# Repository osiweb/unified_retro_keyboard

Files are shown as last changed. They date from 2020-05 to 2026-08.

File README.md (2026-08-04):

## Unified Retrocomputer Keyboard Project

This project aims to provide a unified collection of keyboards and encoders for
vintage computers, with modular design to reuse as many elements as possible
across the designs.

Home computers of the 1970's typically either polled a switch matrix, or
interfaced to a parallel ASCII keyboard via a parallel port.

The keyboard allows use of Cherry MX keys, or Futaba MD-4PCS (aka George Risk
KBM-01-01) keys.

The keyboard is designed using KiCad in order to be the most useful for anybody
wishing to modify the keyboard for more specific uses, or to add to the project.

For construction and notes, see the the wiki at https://github.com/osiweb/unified_retro_keyboard/wiki.

### Capabilities so far:
- Replacement keyboard for OSI computers
- Replacement keyboard for Apple II/II+ computers
- Replacement keyboard for the Sol-20 computer
- Generic ADM-3A/Teletype style keyboard
- Apple I keyboard (multiple styles)
- Franklin ACE 1000 replacement keyboard by Chris Ryu (https://github.com/ryucats/Franklin-ACE-1000-Keyboard)

### Coming soon:
- Replace encoder board on Apple II/II+ keyboards
- Convert an OSI 542 keyboard into a generic ASCII keyboard
- Replica for Knight keyboard

### This keyboard project so far consists of:
- A classic retro-style ASCII keyboard, modeled after the ADM-3A keyboard, which
  can be also be populated to fit perfectly in an Apple II/II+ case (with corresponding Apple II keymaps), or an OSI
  case (with OSI adapter).
- A Sol-20 compatible keyboard.
- Keyscan/decoder interface modules that can output parallel ASCII, and can be adapted for other protocols.
- An OSI interface module, to connect the classic keyboard to an OSI computer.

### Firmware

The ASDF keyscan/encoder firmware lives in its own repository:
<https://github.com/unified-retro-keyboard/asdf-firmware>

- **Download page**: <https://unified-retro-keyboard.github.io/asdf-firmware/> — per-target `.hex` files and release notes.
- **GitHub Releases**: <https://github.com/unified-retro-keyboard/asdf-firmware/releases/latest>

The full firmware history, including everything that was previously under `firmware/`
in this repository, is preserved there.

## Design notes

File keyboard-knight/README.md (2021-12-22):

# Knight keyboard

This keyboard replicates the keyboards on the MIT AI PDP-10.

## Differences from the original include:

1. The original keyboard used Hall effect switches. This keyboard uses
   standard switches (either Cherry or Futaba).

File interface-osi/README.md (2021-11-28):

* OSI Compatible interface

An interface for OSI computers that is compatible with the OSI 542C keyboard, including sound circuits.  

This interface also permits substitution of a soft-shiftlock function using 
a regular momentary keyswitch, instead of the hard-to-find latching keyswitch.
An LED is provided to indicate SHIFT LOCK status.  This interface mates with
the Classic ASCII keyboard, configured with the OSI keycaps.  

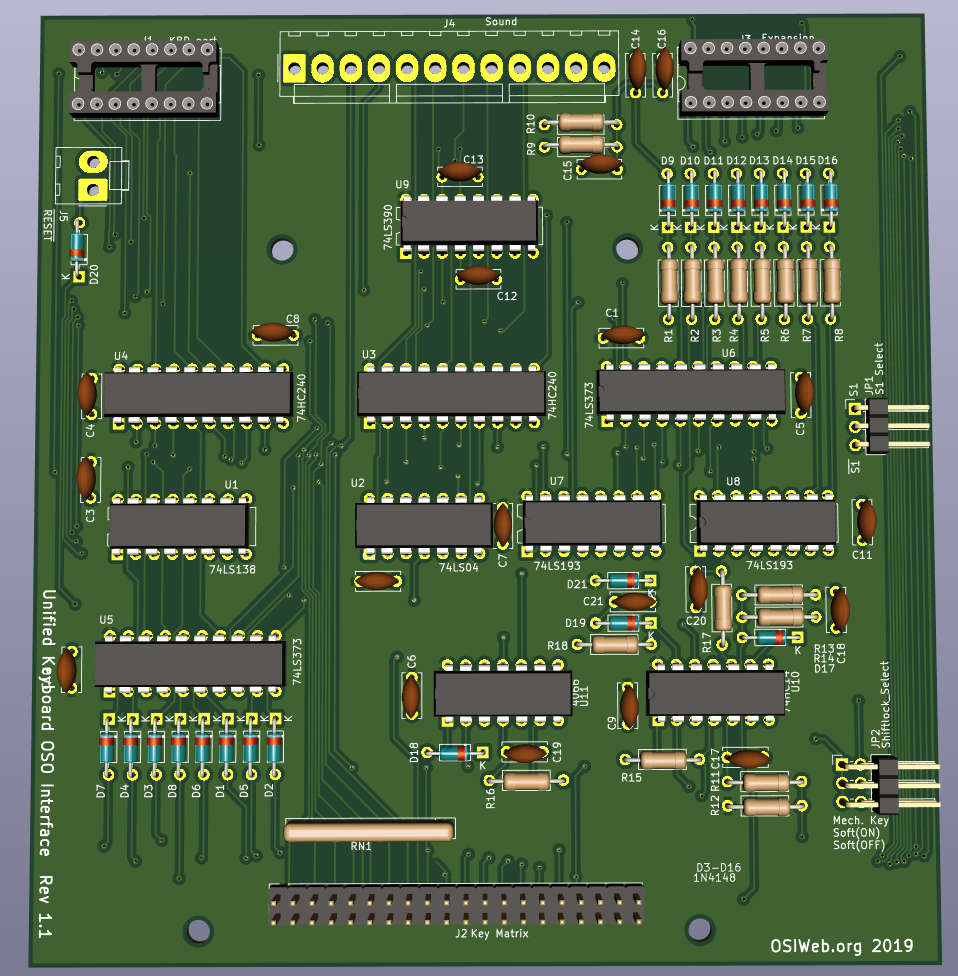
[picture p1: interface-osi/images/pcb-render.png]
Assembly Rendering


**Construction Notes:

1. If a diode per key is installed on the keyboard, then omit diodes D1-D8 and install D18.

1. If the keyboard is not installed with a diode per key, then install D1-D8, and omit D18.

1. The RESET delay is about 3 seconds with a 6.8 uF capacitor at C20.  4.7 uF gives about
2 seconds, and 3.3 uF gives about a 1 second delay.

1. If you want to use the sound circuit with an older 540A video board, then on the 540A board, jumper pin 13
of IC E4 to pin 15 of the keyboard connector, and on the OSI interface board, set JP1 to "S1".

1. If you use a 540B video board, then set JP1 to "/S1"

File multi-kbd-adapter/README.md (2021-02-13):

# Unified Keyboard Project Multi Adapter

This is a keyboard adapter to permit use of Apple 1, Apple 2, and Sol-20
compatible keyboards with any of these three computers.

## Notes
- Protoboard-style pad matrix permits flexible choice of on-board RESET and CLEAR (OR
  LOCAL) switches.
- Pin header allows external RESET and CLEAR (or LOCAL) switches
- Note that the SOL and Apple keyboards have different strobe polarity. Make
  sure the strobe polarity on the keyboard is properly configured.

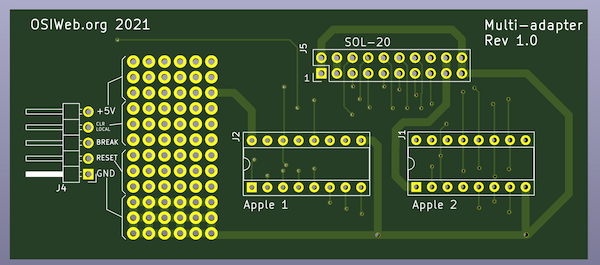
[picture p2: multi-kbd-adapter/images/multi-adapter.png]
Assembly Rendering


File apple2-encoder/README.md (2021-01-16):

# Apple II/II+ Encoder

This is a version of the ASCII interface wired up to be compatible with the
Apple II/Apple II+ keyboard matrix. This board was broken out as a separate PCB
from the Atmega2560-based interface board on which it was based, in order to
keep the "custom" connector customizable on that board.

This board is otherwise identical to rev 3.4 of the ATMega2560-based ASCII interface board, and shares the same firmware and features.

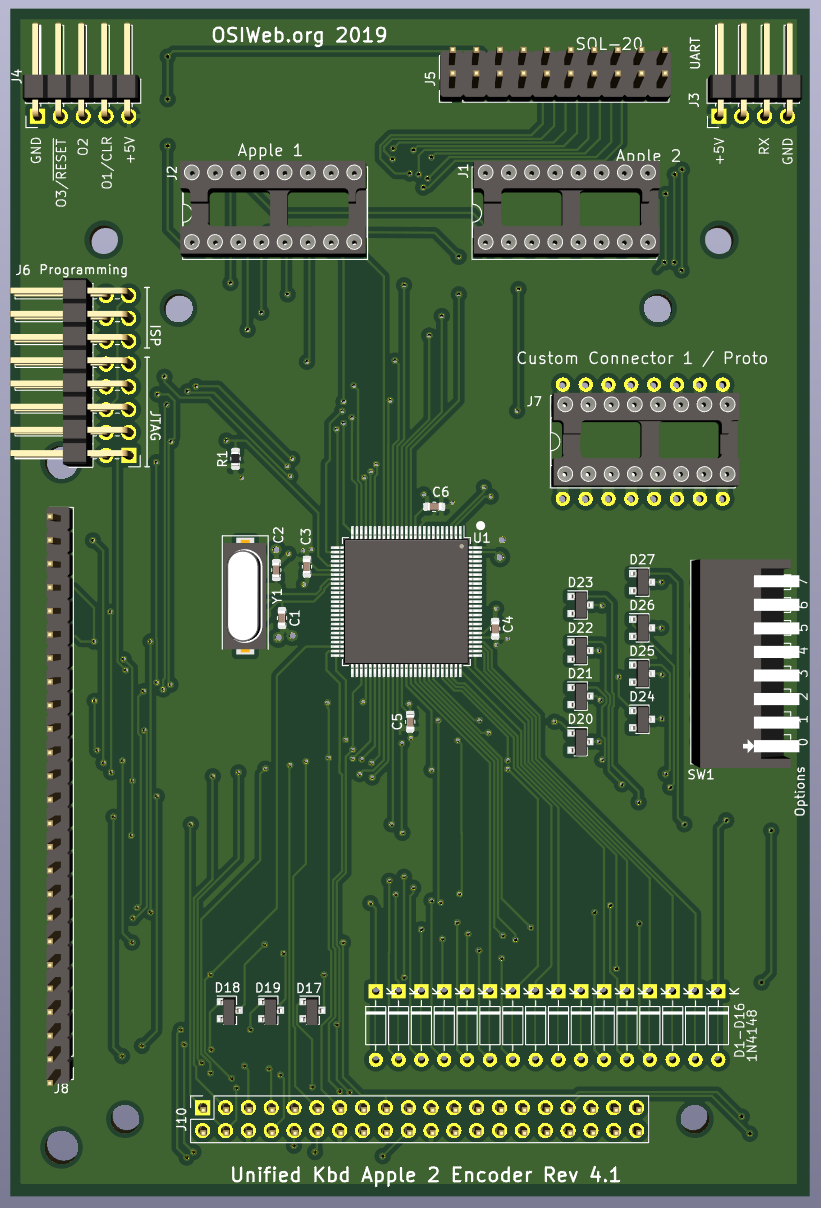
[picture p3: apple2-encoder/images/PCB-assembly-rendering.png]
Assembly Rendering


## Features
- Parallel or serial output
- Up to 8 configuration settings via an up-to-8 position DIP switch
- Apple 1, Apple 2, and SOL-20 compatible outputs. Other configurations can be
  supported by making a custom cable.
- Can decode arbitrary keyboards up 16 rows by 8 columns.
- Supports up to 3 keyboard LEDs
- Supports up to 3 "special" host outputs, such as RESET, SCREEN_CLEAR, BREAK, etc.
- Socket for custom connector

## Assembly Notes

- You may build this board as if it is a general purpose ASCII interface. In
   that case, you may want to avoid installing the 1x25 Apple2 keyboard header
   if it interferes with the target keyboard matrix. 
   
- This encoder is normally used with keyboards that have a diode per key.  For use 
with a key  matrix with no diodes (such as the Apple 2 key matrix), cut the PCB 
traces that short diodes D1-16, and install D1-16.

- If you ARE building this board as an Apple 2 encoder, then you may OMIT:

    - Sol-20 connector J5
    - Custom connector J7
    - D17,D18,D19 - These are used for the "classic" keyboard matrix.
    - D7,D8,D15,D16 - These are diodes for rows 12-15, which are not used.
    - The serial out connector J3 if you do not plan to use a serial output.
    - The I/O connector J4, as all the I/O lines are routed through the
       keyboard connector.
    - If you will be using the keyboard with only an Apple 1 or Apple 2, then
       you do not need to install both the Apple 2 connector (J1) AND the Apple
       1 connector (J2). You may install only the one you plan to use, and
       reduce the risk of plugging into the wrong socket (and possibly damaging
       the encoder).
    
1. Solder the surface-mount microcontroller first. Be sure to match pin 1 to the
   dot on the silk-screen layer.
1. Next, install the surface mount crystal, Y1.  The orientation is not important.
1. Next, solder in the resitor R1
1. Install all the capacitors. Be sure to separate out the two capacitors for the XTAL 
   circuit from the other capacitors, the rest of which are 0.1uF bypass capacitors.
1. Install the In-circuit Serial Programming (ISP) header, J6. (right-angle, 2x3
   0.100")
1. If you will be using the Apple 1 connector, install the DIP socket J1 (16-pin
   dip). If you plan to insert and remove the cable many times, a dual-wipe
   socket may be preferable to machine-pin, since it has a lower insertion
   force, and you will be less likely to bend pins. If you plan to insert the
   cable once and leave it forever, I suggest a machine-pin DIP socket.
1. If you will be using the Apple 2 connector, install the DIP socket J2 (16-pin
   dip).  The note for the Apple 1 connector selection applies here as well.

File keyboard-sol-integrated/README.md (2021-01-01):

# SOL keyboard with built-in encoder

This keyboard with integrated encoder replicates the keyboard on the SOL-20.

This keyboard has a sibling Sol-20 keyboard without integrated
encoder [(here)](../keyboard-sol). The two keyboards are identical except for the following differences:

1. This integrated version places the connector closer to the main board keyboard
   socket, so the original cable fits more easily.

1. The non-integrated version requires a piggy-back encoder board. When
   installing in a Sol-20, this piggyback board must be mounted on the right
   side of the keyboard, and connected with a cable, to avoid mechanical
   interference from the Sol main board.
   
1. The piggy-back encoder is more flexible for use with other machines, via the Apple-1 and
   Apple-2 sockets, and two different user-configurable headers.
   
1. The piggy-back encoder also includes a UART interface.

The keyboard is designed using KiCad in order to be the most useful for anybody
wishing to modify the keyboard for more specific uses, or to add to the project.

The keyset for the SOL-20 keyboard consists of the Unified Keyboard Project
classic ASCII keyset, with a special SOL-20 add-on keyset.

## Differences from the original include:

1. The original keyboard is a capacitive keyboard. This keyboard uses standard
   switches (either Cherry or Futaba).
   
1. The original keycaps have an 11 degree angled stem. It may be possible to
   find such keycaps, but I was unable to find any. It also may be possible to
   create 11 degree adapters. But this keyboard uses straight keycaps. I have
   tried both styles, and do not find a difference in typing comfort or speed,
   althought there is an aesthetic difference. There is s tiny bit of space
   between keys using straight keycaps, so an 11 degree adapter may not require
   any change to the layout.

1. The original uses UPPERCASE+REPEAT to reset the system. For technical
   reasons, this version uses CTRL+MODE_SELECT to RESET the system. 

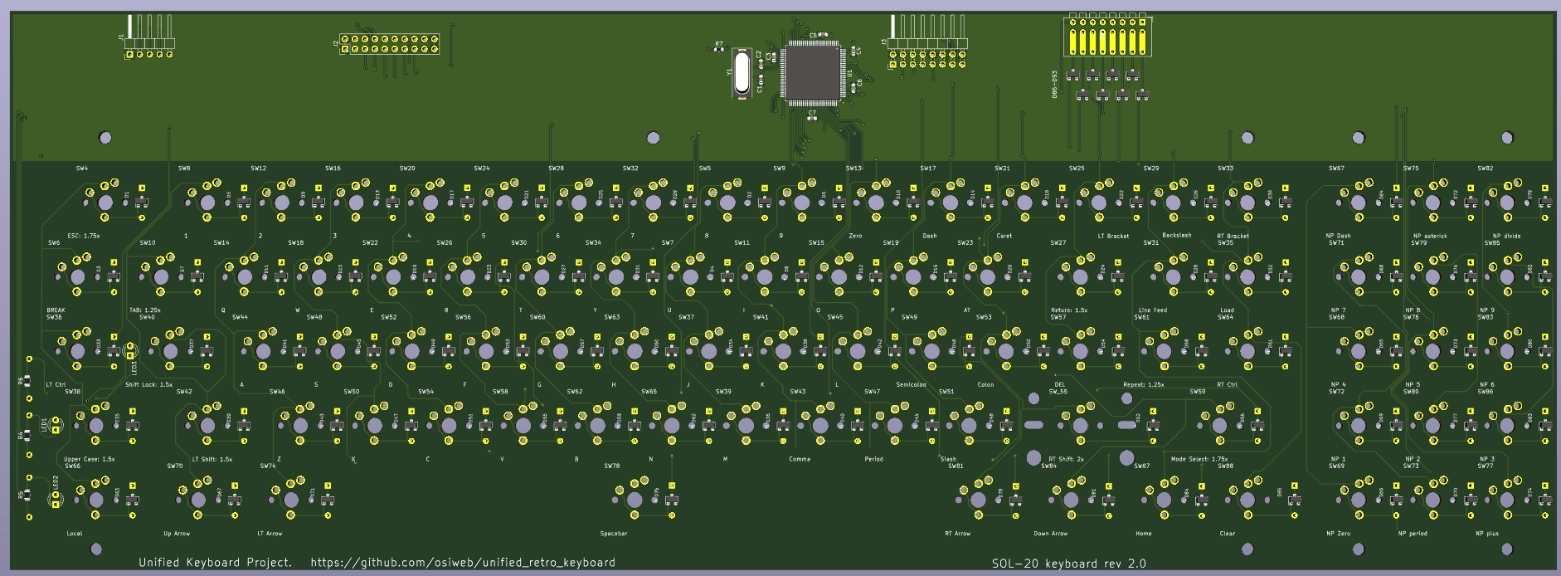
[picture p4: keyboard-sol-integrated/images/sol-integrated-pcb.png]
Sol 20 Keyboard

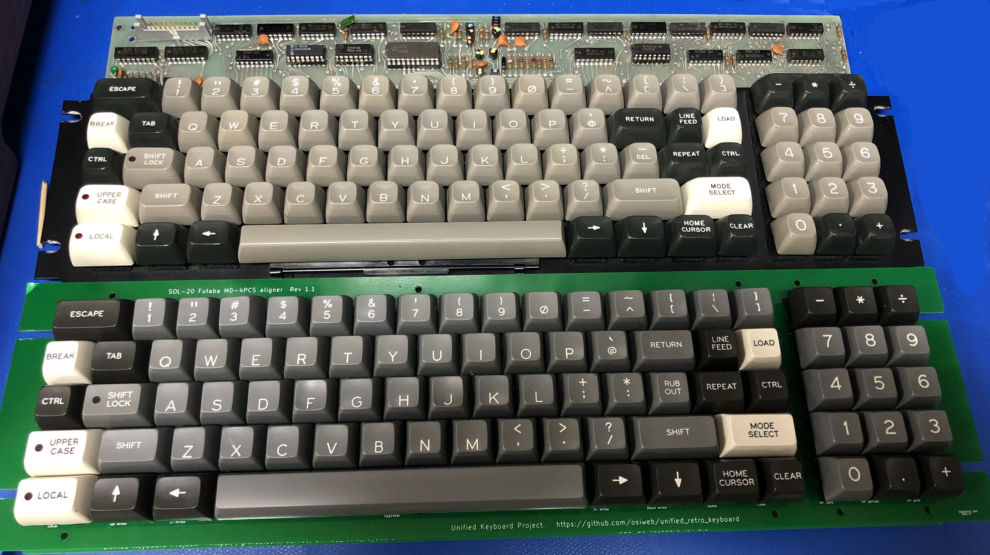
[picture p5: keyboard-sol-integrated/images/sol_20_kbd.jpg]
Sol 20 Keyboard

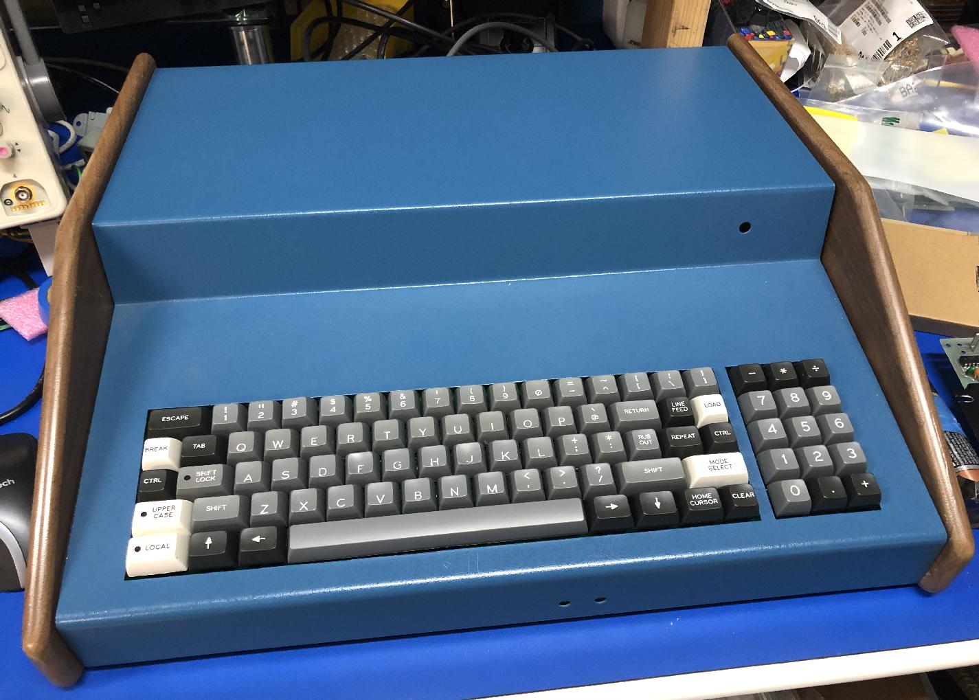
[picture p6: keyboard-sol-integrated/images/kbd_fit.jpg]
Sol 20 Keyboard


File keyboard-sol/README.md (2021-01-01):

# SOL keyboard

This keyboard replicates the keyboard on the SOL-20.

This keyboad matrix works with one of the add-on ASCII encoders from this
project, which must be separately built or acquired.

This keyboard has a sibling Sol-20 keyboard with integrated
encoder [(here)](../keyboard-sol-integrated). The two keyboards are identical except for the following differences:

1. The integrated version places the connector closer to the main board keyboard
   socket, so the original cable fits more easily.

1. This non-integrated version requires a piggy-back encoder board. When
   installing in a Sol-20, this piggyback board must be mounted on the right
   side of the keyboard, and connected with a cable, to avoid mechanical
   interference from the Sol main board.
   
1. The piggy-back encoder is more flexible for use with other machines, via the
   Apple-1 and Apple-2 sockets, and two different user-configurable headers.
   
1. The piggy-back encoder also includes a UART interface.

The keyboard is designed using KiCad in order to be the most useful for anybody
wishing to modify the keyboard for more specific uses, or to add to the project.

The keyset for the SOL-20 keyboard consists of the Unified Keyboard Project
classic ASCII keyset, with a special SOL-20 add-on keyset.

## Differences from the original include:

1. The original keyboard is a capacitive keyboard. This keyboard uses standard
   switches (either Cherry or Futaba).
   
1. The original keycaps have an 11 degree angled stem. It may be possible to
   find such keycaps, but I was unable to find any. It also may be possible to
   create 11 degree adapters. But this keyboard uses straight keycaps. I have
   tried both styles, and do not find a difference in typing comfort or speed,
   althought there is an aesthetic difference. There is s tiny bit of space
   between keys using straight keycaps, so an 11 degree adapter may not require
   any change to the layout.

1. The original uses UPPERCASE+REPEAT to reset the system. For technical
   reasons, this version uses CTRL+MODE_SELECT to RESET the system. 

Sol 20 Keyboard
Sol 20 Keyboard

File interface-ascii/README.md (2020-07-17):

# ASCII Interface - Atmega328p

This is is a key scanner module with parallel output, and optional serial
output, supporting keyboards of up to 16 rows X 8 columns.

The ATMega 328P was selected for the sole reason that it is an architecture
familiar to many hobbyists, with an accessible programming environment and
ecosystem, in a DIP format that fits the retro look and is easy to solder for
most hobbyists. All of the ICs, other than the microcontroller, are only present
to compensate for the limited number of GPIO lines on this small 28-pin
microcontroller. Using a bigger chip would greatly simplify the hardware and
even slightly simplify the hardware layer of the firmware.

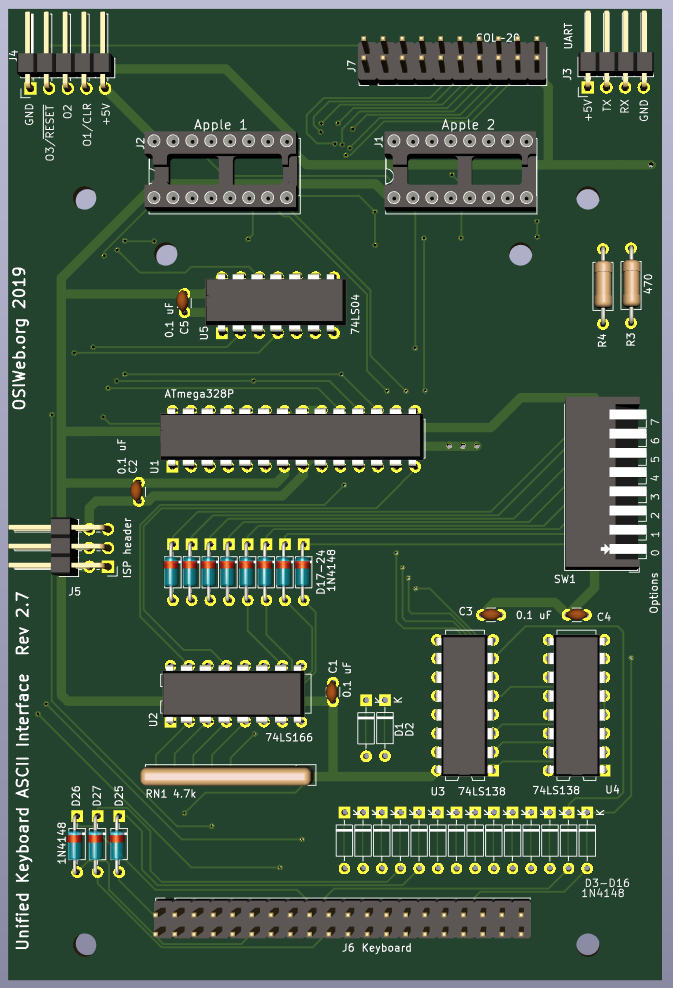
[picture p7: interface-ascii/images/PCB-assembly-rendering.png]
Assembly Rendering


## Features
- Parallel or serial output
- Up to 8 configuration settings via an up-to-8 position DIP switch
- Apple 1, Apple 2, and SOL-20 compatible outputs. Other configurations can be
  supported by making a custom cable.
- Can decode arbitrary keyboards up 16 rows by 8 columns.
- Supports up to 3 keyboard LEDs
- Supports up to 3 "special" host outputs, such as RESET, SCREEN_CLEAR, BREAK, etc.

## Overview
- The keyboard rows are driven by a pair of 74LS138 decoders, allowing 4 GPIO
  lines to drive 16 rows.
- The columns are read in via an 8-bit shift register, controlled by 3 GPIO lines.
- One 8-bit port is used for the parallel ASCII output.
- Three GPIO lines are used to generate special outputs to the host. These could
  be RESET, BREAK, CLEAR, etc. Two of these may be configured as emulated
  open-collector drivers.
- Three GPIO lines are used to control keyboard LEDs. 
- The DIP switch is wired into row 8 (of 0-15) to reduce RAM usage and speed up
  key scanning.

- The top two parallel I/O bits can also be configured as UART I/O. This could
be used to provide serial output instead or parallel output, to support a
bootloader, or even to accept a serial input stream from another computer to
send to the host as parallel ASCII data. This last application would require
careful timing to avoid conflicts.

## Assembly Notes

A typical build includes:
1. the Microcontroller (U1)
1. the 74LS166 shift register (U2)
1. both 74LS138 decoder (U3)
1. Diodes D17-D24 and D25-D27.
1. The two resistors R3 and R4. If you are using the keyboard in only a parallel
   configuration or only a serial configuration, then you can jumper these
   resistors with a piece of wire.
1. The resistor network RN1
1. The DIP switch SW1
1. The 40-pin keyboard connector (2x20 0.1" pin header)
1. At least one output connector (Apple 1, Apple 2, or Sol-20)
1. The 6-pin programming header J5.

The MINIMUM functioning circuit includes 
1. the Microcontroller (U1)
1. the 74LS166 shift register (U2)
1. One 74LS138 decoder (U3). Without the second decoder, the DIP switch is not
   supported, so only one keymap must be assigned as keymap 0 at compile time.
1. The resistor network RN1
1. The two resistors R3 and R4. If you are using the keyboard in only a parallel
   configuration or only a serial configuration, then you can jumper these
   resistors with a piece of wire.
1. Any connectors required.

## Optional components
### Diodes D1-D16
NOT NORMALLY POPULATED. 

These diodes are intended to prevent conflicts between
high and low keyboard driver outputs. They allow the row drivers to pull rows
low, but not high, emulating open collector outputs.

If you are attaching a keyboard with no diodes, then you only need to populate
the diodes corresponding to rows on the keyboard. If the keyboard has 8 rows,
then you may want to install 8 diodes corresponding to those rows.

Note that the footprints for these diodes include a copper jumper on the TOP
copper layer. If you install any of these diodes, you should cut the jumpers for
those diodes. Otherwise the diodes would do nothing.

If you are attaching a keyboard with a diode per key, then the diodes on the
keys perform the same function, in addition to preventing "ghosting", so the
per-row diodes do not need to be installed.

### DIP switch and associated diodes
TYPICALLY INSTALLED.

If you don't want to select keymaps or options via the DIP
switch, then you may omit the DIP switch and diodes. If you do this, then you
will have to set the keymap and all preferences in the firmware. DIP switches,
you can set all your preferences in the firmware, or just accept the default
behavior, and skip the DIP switch and Diodes D17-D20 and D24-D27.

### Second 74LS138 multiplexer (U4)
TYPICALLY INSTALLED.

You may omit this if 
1. your keyboard matrix has 8 rows or fewer
1. AND you don't want any DIP options
1. AND you only want one pre-compiled keymap.

### The 74LS07 hex buffer (U5) and pullup R6
TYPICALLY INSTALLED.

The 74LS07 is needed if you are using LED2 or LED3 on the keyboard, or the OUT2
open collector output. If OUT2 is not open collector, then use a 74LS04 instead.

### Diodes D21, D22, D23
TYPICALLY INSTALLED.

Some keyboards may not wire all keys into the matrix. For example, some other
interface modules may assign special hardware functions to certain keys. Those
keys are brought directly to the keyboard connector. For the classic keyboard,
the POWER key, the '@' key, and the RUBOUT key are not directly wired. This
module wires them into the matrix via D21, D22, and D23, respectively. For
keyboards with no separately wired keys, these diodes may be omitted.

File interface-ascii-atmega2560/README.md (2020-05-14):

# ASCII Interface - Atmega2560

This is is a key scanner module with parallel output, and optional serial
output, supporting keyboards of up to 16 rows X 8 columns.  This design uses the ATMega2560, since it's an easy port from the ATMega328P, which was initially selected for the sole reason of being familiar to hobbyists. The 2560 has much more I/O, which simplifies the design, assembly, and firmware, and opens up some additional possibilities. 

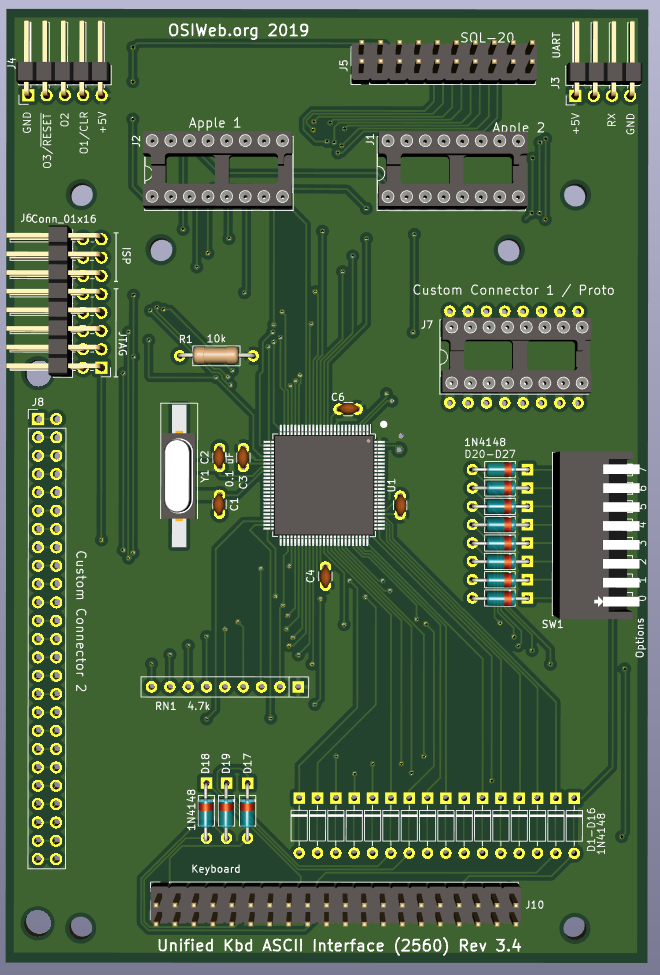
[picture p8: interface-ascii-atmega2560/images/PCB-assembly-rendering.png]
Assembly Rendering


## Features
- Parallel or serial output
- Up to 8 configuration settings via an up-to-8 position DIP switch
- Apple 1, Apple 2, and SOL-20 compatible outputs. Other configurations can be
  supported by making a custom cable.
- Can decode arbitrary keyboards up 16 rows by 8 columns.
- Supports up to 3 keyboard LEDs
- Supports up to 3 "special" host outputs, such as RESET, SCREEN_CLEAR, BREAK, etc.
- Socket for custom connector

## Differences from ATMega328P version
- Backward compatible with the ATMega328P version, with following enhancements:
1. All the TTL outputs can be regualar push-pull TTL, open-collector, or open-emitter. In the
   328P version, changing between regular TTL output and open-collector on
   Output 2 required changing an IC.
1. The serial port no longer shares lines with the parallel output port, so both
   serial I/O and parallel output can be used at the same time without risk of
   conflict. However, serial I/O is not yet supported in the firmware.
1. Because the rows are no longer driven by a 4-to-16 decoder circuit, and the
   columns are no longer read via a shift register, the row and column lines can
   be used for both input and output, which allows this board to interface with
   OSI keyboards directly (not yet supported in firmware).
   
## Overview
- Two GPIO ports are used to drive the row outputs, and one GPIO port is used to
  read the columns.
- One 8-bit port is used for the parallel ASCII output.
- Three GPIO lines are used to generate special outputs to the host. These could
  be RESET, BREAK, CLEAR, etc. These may be configured as open-collector (Hi-Z
  for HI, GND for LO), or open-emitter (5V for high, Hi-Z for LO).
- Three GPIO lines are used to control keyboard LED, or other keyboard functions.
- A serial (UART) port is provided. This could be used to provide serial output
instead or parallel output, to support a bootloader, or even to accept a serial
input stream from another source to send to the host as parallel ASCII data.
- JTAG port is provided for programming and debugging
- Two custom connectors (16-pin DIP and 1x25 0.1" header) are provided to allow
  custom ASCII interfaces, or custom keyboard matrix interface.
  
## Assembly Notes

1. Solder the surface-mount microcontroller first. Be sure to match pin 1 to the
   dot on the silk-screen layer.
1. Next, install the surface mount crystal, Y1.  The orientation is not important.
1. Next, solder in the Diodes D17-D19 and D20-D27
1. Install all the capacitors. These are all 0.1 uF ceramic capacitors with 0.1"
   lead spacing. Many capacitors with 0.2" lead spacing are actually 0.1"
   emerging from the body, bent to 0.2", and can be straightened back to 0.1".
1. Next, solder in the resitor R1 and Resistor network RN1.
1. Install DIP switch SW1.
1. Install connector J7 
1. Install the In-circuit Serial Programming (ISP) header, J6. (right-angle, 2x3
   0.100")
1. (Optional) If you will be the digital outputs, or if you will be attaching
   switches or other sources of open-collector signals (such as RESET), then
   install connector J4 (riginht-angle, 1x5 0.100")
1. (Optional) If you will be using the serial port, install the serial header
   J3. (right angle, 1x4 0.100")
1. If you will be using the Apple 1 connector, install the DIP socket J1 (16-pin
   dip). If you plan to insert and remove the cable many times, a dual-wipe
   socket may be preferable to machine-pin, since it has a lower insertion
   force, and you will be less likely to bend pins. If you plan to insert the
   cable once and leave it forever, I suggest a machine-pin DIP socket.
1. If you will be using the Apple 2 connector, install the DIP socket J2 (16-pin
   dip).  The note for the Apple 1 connector selection applies here as well.
1. If you will be using the SOL-20 connector, install connector J5 (vertical
   2x10 0.100")
1. Do not populate diodes D1-D16. These diodes are jumpered short. If you are
   using a key matrix with no diodes, then cut the jumpers with an x-acto knife
   and populate the diodes.
1. Do not populate RN1. The Microprocessor uses internal pullups, so this
   network is not required. The footprint is left in place in case a stronger
   pullup (in the 1K-10K range) is needed.

configuration or only a serial configuration, then you can jumper these
resistors with a piece of wire.
1. Any connectors required.

## Optional components
### Diodes D1-D16
These diodes are intended to prevent conflicts between high and low keyboard
driver outputs. They allow the row drivers to pull rows low, but not high,
emulating open collector outputs.

If you are attaching a keyboard with no diodes, then you only need to populate
the diodes corresponding to rows on the keyboard. If the keyboard has 8 rows,
then you may want to install 8 diodes corresponding to those rows.

Note that the footprints for these diodes include a copper jumper on the TOP
copper layer. If you install any of these diodes, you should cut the jumpers for
those diodes. Otherwise the diodes do nothing.

If you are attaching a keyboard with a diode per key, then the diodes on the keys perform the same function, in addition to preventing "ghosting", so the per-row diodes do not need to be installed.

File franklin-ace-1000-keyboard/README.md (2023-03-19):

# Franklin-ACE-1000-Keyboard
Replacement Franklin ACE 1000 keyboard for use with osiweb's Unified Retro Keyboard

## Images
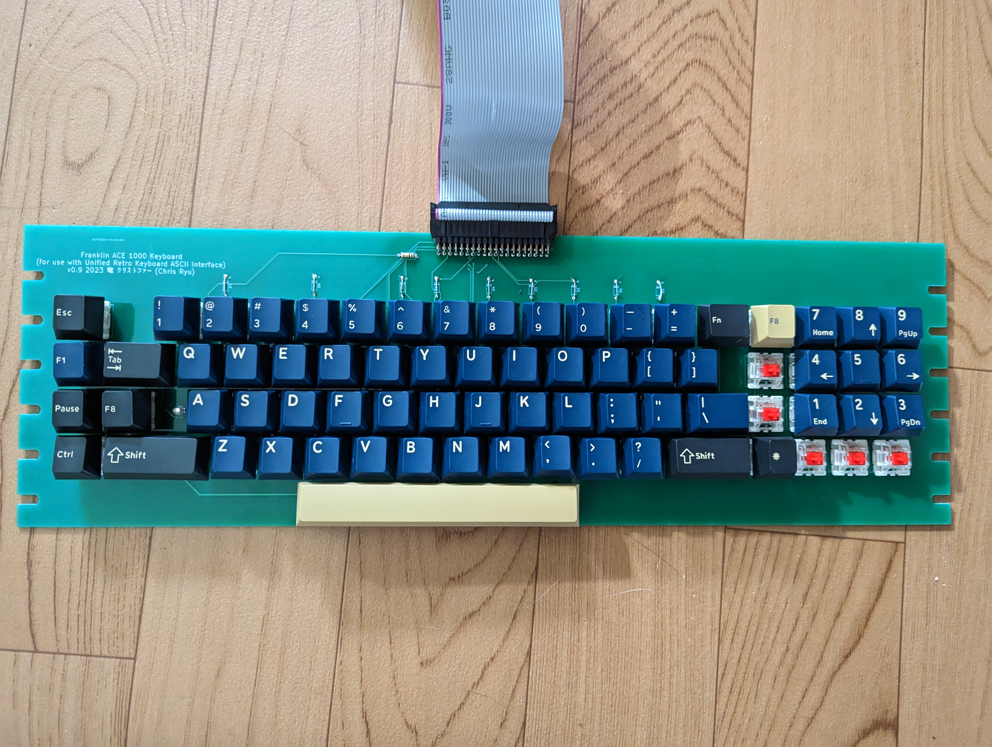
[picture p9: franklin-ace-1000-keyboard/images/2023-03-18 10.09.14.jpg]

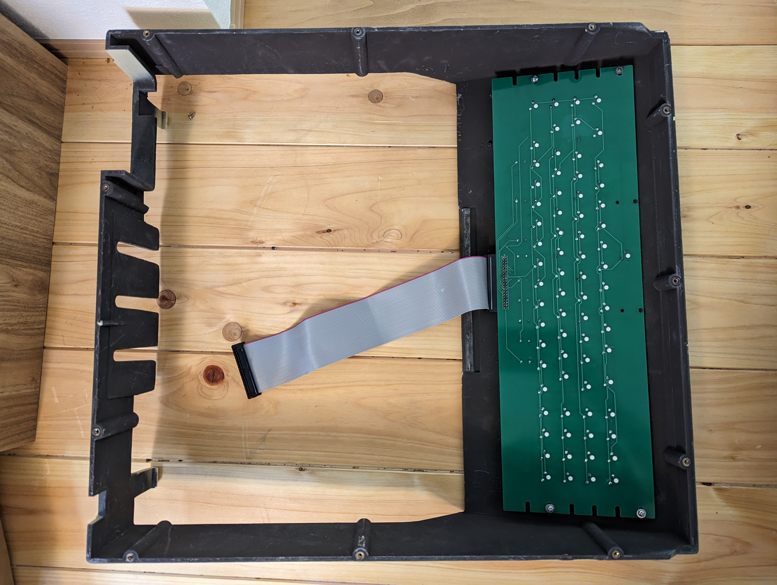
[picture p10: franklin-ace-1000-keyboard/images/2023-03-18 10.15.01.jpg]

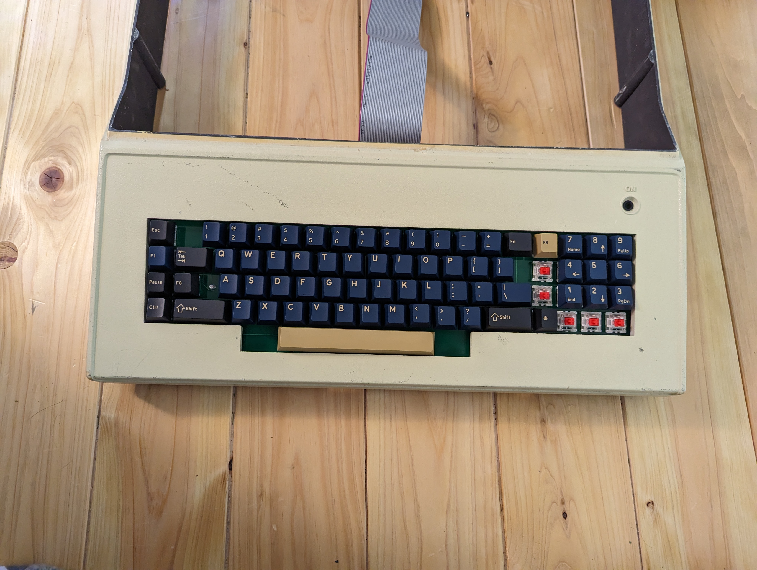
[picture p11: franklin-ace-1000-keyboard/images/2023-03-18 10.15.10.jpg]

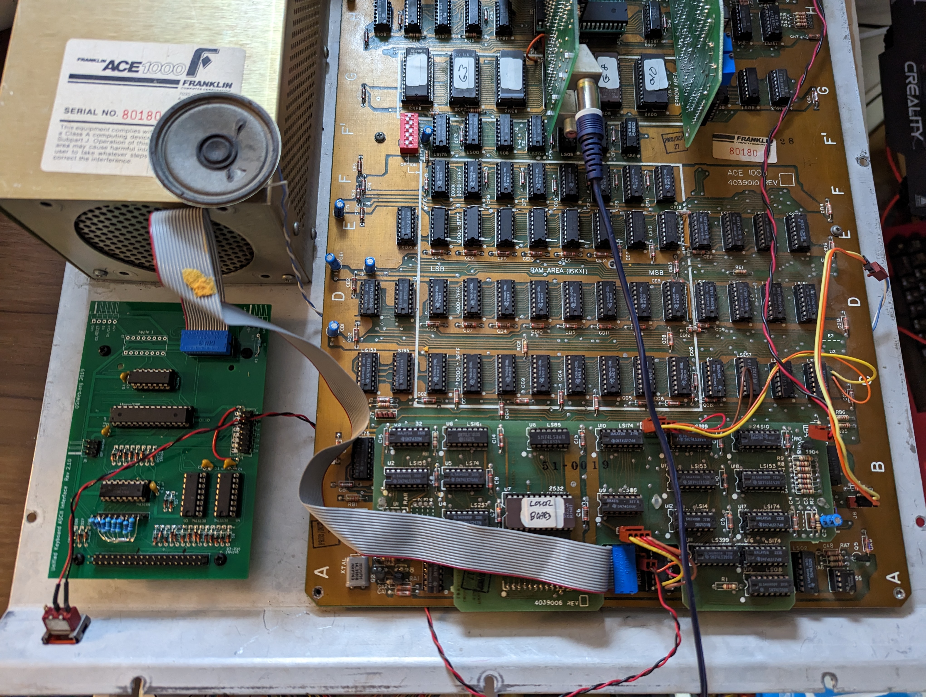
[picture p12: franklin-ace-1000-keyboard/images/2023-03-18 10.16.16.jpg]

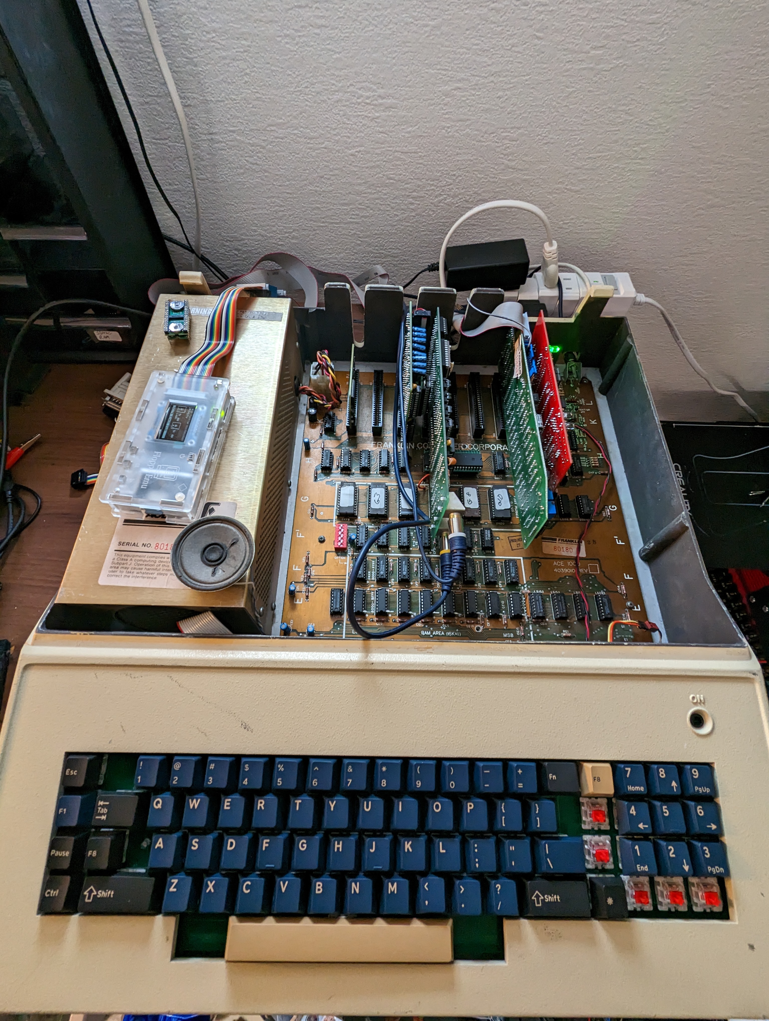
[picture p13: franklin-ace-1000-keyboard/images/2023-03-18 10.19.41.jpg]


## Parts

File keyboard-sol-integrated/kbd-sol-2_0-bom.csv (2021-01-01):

Comment | Designator | Footprint | LCSC
36pf | C1,C2 | Capacitor_SMD:C_0603_1608Metric | C134070
0.1 uF | C3,C4,C5,C6,C7 | Capacitor_SMD:C_0603_1608Metric | C14663
1N4148 | D1,D2,D3,D4,D5,D6,D7,D8,D9,D10,D11,D12,D13,D14,D15,D16,D17,D18,D19,D20,D21,D22,D23,D24,D25,D26,D27,D28,D29,D30,D31,D32,D33,D34,D35,D36,D37,D38,D39,D40,D41,D42,D43,D44,D45,D46,D47,D48,D49,D50,D51,D52,D53,D54,D55,D56,D57,D58,D59,D60,D61,D62,D63,D64,D65,D66,D67,D68,D69,D70,D71,D72,D73,D74,D75,D76,D77,D78,D79,D80,D81,D82,D83,D84,D85, D86,D87,D88,D89,D90,D91,D92,D93 | unikbd:diode-combined | C118751
330 | R4,R5,R6 | Resistor_SMD:R_0805_2012Metric
10k | R7 | Resistor_SMD:R_0603_1608Metric | C98220
ATmega2560-16AU | U1 | Package_QFP:TQFP-100_14x14mm_P0.5mm | C22460
16.000 MHz | Y1 | Crystal:Crystal_SMD_HC49-SD | C326544

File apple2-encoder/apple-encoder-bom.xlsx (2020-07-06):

Ref | Quantity | Value | Label | Fitted | Mount Style | Package | Manufacturer | LCSC | Part No. | Datasheet | Substitution OK | Comment
C1-C2 | 2 | 36pf | 36pf | YES | SMT | 603 |  | C159790 (https://lcsc.com/product-detail/Multilayer-Ceramic-Capacitors-MLCC-SMD-SMT_SAMSUNG_CL10C360JB8NNNC_36pF-36R-5-50V_C159790.html/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) |  | ~ | YES
C3-C6 | 4 | 100 nF | 0.1 uF | YES | SMT | 603 |  | C14663 (https://lcsc.com/product-detail/Multilayer-Ceramic-Capacitors-MLCC-SMD-SMT_100nF-104-10-50V_C14663.html/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) |  | ~ | YES
D17-D27 | 11 | Gen. Purpose, 1.25V or less forward drop | 1N4148 | YES | SMT | SOT-23-3 |  | C181113 (https://lcsc.com/product-detail/Switching-Diode_MMBD4148A_C181113.html/?href=jlc-SMT) |  | https://assets.nexperia.com/documents/data-sheet/1N4148_1N4448.pdf | YES
D1-D16 | 16 | Gen. Purpose, 1.25V or less forward drop | 1N4148 | NO | TH | Through-hole |  |  |  | https://assets.nexperia.com/documents/data-sheet/1N4148_1N4448.pdf | YES | Only install for key matrix without diodes. Cut jumper if installed.
J1 | 1 | 16-pin DIP socket | Apple 2 | YES | TH | 16-pin DIP socket |  |  |  | ~ | YES
J10 | 1 | 2x20 0.1" vertical header | Keyboard | YES | TH | 2x20 0.1" header |  |  |  | ~ | YES
J2 | 1 | 16-pin DIP socket | Apple 1 | NO | TH | 16-pin DIP socket |  |  |  | ~ | YES
J3 | 1 | 1x4 0.1" right angle header | UART | NO | TH |  |  |  |  | ~ | YES
J4 | 1 | 1x5 0.1" right angle header | Outputs | NO | TH |  |  |  |  | ~ | YES
J5 | 1 | 2x10 0.1" right angle pin header | SOL-20 | NO | TH |  |  |  |  | ~ | YES
J6 | 1 | 2x8 0.1" right angle header | Programming | YES | TH |  |  |  |  | ~ | YES
J7 | 1 | 16 pin DIP socket | Custom Connector 1 / Proto | NO | TH | 16-pin DIP socket |  |  |  | ~ | YES
J8 | 1 | 1x25 0.1" vertical header, 1" pins | Apple II Matrix | NO | TH |  | YES |  |  | ~ | YES | 1" pins
R1-R9 | 9 | 10k, 1% | 10k | YES | SMT | 603 | Panasonic | C25804 (https://lcsc.com/product-detail/Chip-Resistor-Surface-Mount_Uniroyal-Elec-0603WAF1002T5E_C25804.html/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) | ERJ-3EKF1002V | https://industrial.panasonic.com/cdbs/www-data/pdf/RDA0000/DMA0000COL9.pdf | YES
SW1 | 1 | 8-pos DIP switch, piano style | Options | YES | TH | Through-hole |  |  |  | ~ | YES
U1 | 1 | ATmega2560-16AU | ATmega2560-16AU | YES | SMT | TQFP-100 | Atmel | C22460 (https://lcsc.com/product-detail/ATMEL-AVR_MICROCHIP_ATMEGA2560-16AU_ATMEGA2560-16AU_C22460.html/?href=jlc-SMT) | AtMega2560-16AU | http://ww1.microchip.com/downloads/en/DeviceDoc/Atmel-2549-8-bit-AVR-Microcontroller-ATmega640-1280-1281-2560-2561_datasheet.pdf | NO
Y1 | 1 | 16.000 MHz, parallel resonant | 16.000 MHz | YES | SMT | HC-49/US | ABRACON |  | ABLS2-16.000MHz-B1U-T | https://abracon.com/Resonators/ABLS2.pdf | YES

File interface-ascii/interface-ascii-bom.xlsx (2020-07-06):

Bill of Materials, ASCII Interface, Rev 2.8
Referece Designator | Qty | Label | Fitted | Manufacturer | Manufacturer PN | Substitution OK | Value | Datasheet | Comments
C1-C5 | 5 | 0.1 uF | Y | Murata | RCER71E104K0A2H3B | Y | 0.1 uF | ~
D1-D16 | 16 | 1N4148 | N | Vishay | 1N4148 | Y | Gen. Purpose/switching | https://assets.nexperia.com/documents/data-sheet/1N4148_1N4448.pdf | Install only for matrix without diodes. Cut jumper if installed
D17-D27 | 11 | 1N4148 | Y | Vishay | 1N4148 | Y | Gen. Purpose/switching | https://assets.nexperia.com/documents/data-sheet/1N4148_1N4448.pdf
J1 | 1 | Apple 2 | Y | 3M | 4816-3000-CP | Y | 16-pin Dual-wipe DIP socket | ~ | Install for Apple 2. Dual Wipe recommended to reduce insertion force
J2 | 1 | Apple 1 | Y | 3M | 4816-3000-CP | Y | 16-pin Dual-wipe DIP socket | ~ | Install for Apple 2. Dual Wipe recommended to reduce insertion force
J3 | 1 | UART | Y | Molex | 22-28-8040 | Y | 1x4 0.1" right angle header | ~ | Install for UART
J4 | 1 | Outputs | Y | Molex | 22-28-8050 | Y | 1x5 0.1" right angle header | ~ | ~
J5 | 1 | ISP header | Y | Molex | 90122-0763 | Y | 2x3 0.1" right angle header | ~ | ~
J6 | 1 | Keyboard | Y | Molex | 90131-0140 | Y | 2x20 0.1" vertical header | ~ | ~
J7 | 1 | SOL-20 | Y | Molex | 90122-0770 | Y | 2x10 0.1" right angle header | ~ | Install for SOL-20
R3, R4 | 2 | 470 | Y | Yageo | MFR-25FTE52-470R | Y | 470 | ~ | ~
RN1 | 1 | 4.7k | Y | Bourns | 4609X-101-472LF | Y | 4.7k |  | ~
SW1 | 1 | Options | Y | CTS | 195-8MST | Y | 8-pos DIP switch | ~ | ~
U1 | 1 | ATmega328P | Y | Atmel (Microchip) | ATMEGA328P-PU | N | ATmega328P | http://ww1.microchip.com/downloads/en/DeviceDoc/ATmega48A-PA-88A-PA-168A-PA-328-P-DS-DS40002061A.pdf | ~
U2 | 1 | 74LS166 | Y | Texas Instruments | SN74LS166AN | Y | 74LS166 | https://www.ti.com/lit/ds/symlink/sn74ls166a | ~
U3, U4 | 2 | 74LS138 | Y | Texas Instruments | SN74LS138N | Y | 74LS138 | http://www.ti.com/lit/gpn/sn74LS138 | ~
U5 | 1 | 74LS04 | Y | Texas Instruments | SN74LS04N | Y | 74LS04 | www.ti.com/lit/ds/symlink/sn74ls04.pdf | ~

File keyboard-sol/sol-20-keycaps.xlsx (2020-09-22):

Sol-20 keycap set |  | Date: | 2020-01-30
All keys SA Row 3
Line # | Color (key/legend) | Size | Top | Top font | Bottom | Bottom Font | Centered | Centered Font | Comment
3 | GD/WFO | 1u |  |  |  |  | 0 | 0.230"
4 | GD/WFO | 1u |  |  |  |  | 1 | 0.230"
5 | GD/WFO | 1u |  |  |  |  | 2 | 0.230"
6 | GD/WFO | 1u |  |  |  |  | 3 | 0.230"
7 | GD/WFO | 1u |  |  |  |  | 4 | 0.230"
8 | GD/WFO | 1u |  |  |  |  | 5 | 0.230"
9 | GD/WFO | 1u |  |  |  |  | 6 | 0.230"
10 | GD/WFO | 1u |  |  |  |  | 7 | 0.230"
11 | GD/WFO | 1u |  |  |  |  | 8 | 0.230"
12 | GD/WFO | 1u |  |  |  |  | 9 | 0.230"
13 | GD/WFO | 1u | _ | 0.100" | DEL | 0.100" |  |  | Top is "_" (underscore)
14 | GD/WFO | 2u |  |  |  |  | SHIFT | 0.100"
15 | GX/WFO | 1u |  |  |  |  | CTRL | 0.100" | Right ctrl
16 | GX/WFO | 1u |  |  |  |  | CTRL | 0.100" | Left ctrl
17 | GX/WFO | 1u |  |  |  |  | CLEAR | 0.100"
18 | GX/WFO | 1u | LINE | 0.100" | FEED | 0.100"
19 | GX/WFO | 1u |  |  |  |  | - | 0.230" | minus
20 | GX/WFO | 1u |  |  |  |  | + | 0.230" | plus
21 | GX/WFO | 1u |  |  |  |  | ÷ | 0.230" | divide
22 | GX/WFO | 1u |  |  |  |  | * | 0.230" | multiply
23 | GX/WFO | 1u |  |  |  |  | . | 0.230" | decimal point. Centered vertically and horizontally in keycap.
24 | GX/WFO | 1.25u |  |  |  |  | → | 0.230" | Right arrow
25 | GX/WFO | 1.25u |  |  |  |  | ← | 0.230" | Left arrow
26 | GX/WFO | 1.25u |  |  |  |  | ↑ | 0.230" | Up arrow
27 | GX/WFO | 1.25u |  |  |  |  | ↓ | 0.230" | Down arrow
28 | GX/WFO | 1.25u | HOME | 0.100" | CURSOR | 0.100"
29 | GX/WFO | 1.25u |  |  |  |  | TAB | 0.100"
30 | GX/WFO | 1.25u |  |  |  |  | REPEAT | 0.100"
31 | GX/WFO | 1.5u |  |  |  |  | RETURN | 0.100"
32 | GX/WFO | 1.75u |  |  |  |  | ESCAPE | 0.100"
33 | WFO/NN | 1u |  |  |  |  | LOAD | 0.100"
34 | WFO/NN | 1u |  |  |  |  | BREAK | 0.100"
35 | WFO/NN | 1.75u | MODE | 0.100" | SELECT | 0.100"
For all LED keys: RED LED window is 0.12” diameter, positioned 0.4” to the LEFT of the stem center. (see example image)
36 | GD/WFO + LED | 1.5u | SHIFT | 0.100" | LOCK | 0.100" |  |  | Pad print the legend with WFO color.
37 | WFO/NN + LED | 1.5u | UPPER | 0.100" | CASE | 0.100" |  |  | Pad print the legend with NN color.
38 | WFO/NN + LED | 1.5u |  |  |  |  | LOCAL | 0.100" | Pad print the legend with NN color.

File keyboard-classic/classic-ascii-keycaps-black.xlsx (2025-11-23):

Classic Keycap set (Black) |  |  |  | Date: |  | 2021-11-29
Order specifications for Signature Plastics keycaps
Colors are specified using Signature Plastics color codes. Reference for colors: https://pimpmykeyboard.com/colors
Reference for key profiles: https://pimpmykeyboard.com/key-cap-family-specs
All keys SA Row 3
Line | Keycap Color | Legend Color | Size | Top | Top font | Bottom | Bottom Font | Centered | Centered Font | Comment
1 | NN | WFO | 1u |  |  | A | 0.187"
2 | NN | WFO | 1u |  |  | B | 0.187"
3 | NN | WFO | 1u |  |  | C | 0.187"
4 | NN | WFO | 1u |  |  | D | 0.187"
5 | NN | WFO | 1u |  |  | E | 0.187"
6 | NN | WFO | 1u |  |  | F | 0.187" |  |  | Deep Dish
7 | NN | WFO | 1u | BELL | 0.100" | G | 0.187"
8 | NN | WFO | 1u |  |  | G | 0.187"
9 | NN | WFO | 1u |  |  | H | 0.187"
10 | NN | WFO | 1u |  |  | I | 0.187"
11 | NN | WFO | 1u |  |  | J | 0.187" |  |  | Deep Dish
12 | NN | WFO | 1u |  |  | K | 0.187"
13 | NN | WFO | 1u |  |  | L | 0.187"
14 | NN | WFO | 1u |  |  | M | 0.187"
15 | NN | WFO | 1u |  |  | N | 0.187"
16 | NN | WFO | 1u | ^ | 0.187" | N | 0.187"
17 | NN | WFO | 1u |  |  | O | 0.187"
18 | NN | WFO | 1u |  |  | P | 0.187"
19 | NN | WFO | 1u | @ | 0.187" | P | 0.187"
20 | NN | WFO | 1u |  |  | Q | 0.187"
21 | NN | WFO | 1u |  |  | R | 0.187"
22 | NN | WFO | 1u |  |  | S | 0.187"
23 | NN | WFO | 1u |  |  | T | 0.187"
24 | NN | WFO | 1u |  |  | U | 0.187"
25 | NN | WFO | 1u |  |  | V | 0.187"
26 | NN | WFO | 1u |  |  | W | 0.187"
27 | NN | WFO | 1u |  |  | X | 0.187"
28 | NN | WFO | 1u |  |  | Y | 0.187"
29 | NN | WFO | 1u |  |  | Z | 0.187"
30 | NN | WFO | 1u | ! | .150" | .150" | 0.187"
31 | NN | WFO | 1u | “ | .150" | .150" | 0.187"
32 | NN | WFO | 1u | # | .150" | .150" | 0.187"
33 | NN | WFO | 1u | $ | .150" | .150" | 0.187"
34 | NN | WFO | 1u | % | .150" | .150" | 0.187"
35 | NN | WFO | 1u | & | .150" | .150" | 0.187"
36 | NN | WFO | 1u | ' | .150" | .150" | 0.187" |  |  | straight apostrophe and 7
37 | NN | WFO | 1u | ( | .150" | .150" | 0.187"
38 | NN | WFO | 1u | ) | .150" | .150" | 0.187"
39 | NN | WFO | 1u |  |  | .150" | 0.187"
40 | NN | WFO | 1u | * | .150" | .150" | 0.187"
41 | NN | WFO | 1u | = | .150" | .150" | 0.187" |  |  | equal and minus
42 | NN | WFO | 1u | + | .150" | .150" | 0.187"
43 | NN | WFO | 1u | < | .150" | .150" | 0.187" |  |  | < and comma
44 | NN | WFO | 1u | > | .150" | .150" | 0.187" |  |  | > and period
45 | NN | WFO | 1u | ? | .150" | .150" | 0.187"
46 | NN | WFO | 1u | { | .150" | .150" | 0.187"
47 | NN | WFO | 1u | } | .150" | .150" | 0.187"
48 | NN | WFO | 1u | ~ | .150" | .150" | 0.187"
49 | NN | WFO | 1u | ` | .150" | .150" | 0.187" |  |  | grave accent and @
50 | NN | WFO | 1u | | | .150" | .150" | 0.187" |  |  | vertical bar and backslash
51 | NN | WFO | 1u |  |  |  |  | → | 0.230" | Right arrow
52 | NN | WFO | 1u |  |  |  |  | ← | 0.230" | Left arrow
53 | NN | WFO | 1u |  |  |  |  | ↑ | 0.230" | Up arrow
54 | NN | WFO | 1u |  |  |  |  | ↓ | 0.230" | Down arrow
55 | NN | WFO | 1u |  |  |  |  | ESC | 0.100"
56 | NN | WFO | 1u |  |  |  |  | CTRL | 0.100"
57 | NN | WFO | 1u |  |  |  |  | REPEAT | 0.100"
58 | NN | WFO | 1u |  |  |  |  | BREAK | 0.100"
59 | NN | WFO | 1u |  |  |  |  | TAB | 0.100"
60 | NN | WFO | 1u |  |  |  |  | RESET | 0.100"
61 | NN | WFO | 1u |  |  |  |  | CLEAR | 0.100"
62 | NN | WFO | 1u | RUB | 0.100" | OUT | 0.100"
63 | NN | WFO | 1u | LINE | 0.100" | FEED | 0.100"
64 | NN | WFO | 1u | SHIFT | 0.100" | LOCK | 0.100"
65 | NN | WFO | 1u | CAPS | 0.100" | LOCK | 0.100"
66 | NN | WFO | 1u | HERE | 0.100" | IS | 0.100"
67 | NN | WFO | 1.5u |  |  |  |  | SHIFT | 0.100" | Left shift
68 | NN | WFO | 1.5u |  |  |  |  | SHIFT | 0.100" | Right shift
69 | NN | WFO | 1.5u |  |  |  |  | RETURN | 0.100"
70 | NN | WFO | 1.5u |  |  |  |  | TAB | 0.100"
71 | NN | n/a (no legend) | 8u |  |  |  |  |  |  | Spacebar
72 | WEL | BLACK | 1u |  |  |  |  | POWER | 0.100" | Pad print legend (lighted key)

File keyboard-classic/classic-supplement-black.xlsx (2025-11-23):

Classic Supplement set |  |  |  | Date: |  | 2021-11-29
Order specifications for Signature Plastics keycaps
Colors are specified using Signature Plastics color codes. Reference for colors: https://pimpmykeyboard.com/colors
Reference for key profiles: https://pimpmykeyboard.com/key-cap-family-specs
All keys SA Row 3
Line | Keycap Color | Legend Color | Size | Top | Top font | Bottom | Bottom Font | Centered | Centered Font | Comment
1 | NN | WFO | 1u | { | 0.150" | [ | 0.150"
2 | NN | WFO | 1u | } | 0.150" | ] | 0.150"
3 | NN | WFO | 1u | ^ | 0.150" | ~ | 0.150" |  |  | ^ over ~
4 | NN | WFO | 1u | ~ | 0.150" | ^ | 0.150" |  |  | ~ over ^
5 | NN | WFO | 1u | @ | 0.150" | \ | 0.150" |  |  | grave accent and @
6 | NN | WFO | 1u | ` | 0.150" | @ | 0.150" |  |  | grave accent and @
7 | NN | WFO | 1u | | | 0.150" | \ | 0.150" |  |  | vertical bar and backslash
8 | NN | WFO | 1u |  |  |  |  | ↑ | 0.230" | Up arrow
9 | NN | WFO | 1u |  |  |  |  | ↓ | 0.230" | Down arrow
10 | NN | WFO | 1u |  |  |  |  | TAB | 0.100"
11 | NN | WFO | 1u |  |  |  |  | DELETE | 0.100"
12 | NN | WFO | 1u |  |  |  |  | CLEAR | 0.100"
13 | NN | WFO | 1u |  |  |  |  | SHIFT | 0.100" | 1U SHIFT (left)
14 | NN | WFO | 1u |  |  |  |  | SHIFT | 0.100" | 1U SHIFT (right)
15 | NN | WFO | 1u | HERE | 0.100" | IS | 0.100"
16 | NN | WFO | 1u | SHIFT | 0.100" | LOCK | 0.100"
17 | NN | WFO | 1u | ALPHA | 0.100" | LOCK | 0.100"
18 | NN | WFO | 1u | CAPS | 0.100" | LOCK | 0.100"
19 | NN | WFO | 1u |  |  | N | 0.187"
20 | NN | WFO | 1u |  |  | P | 0.187"
21 | NN | WFO | 1u |  |  | G | 0.187"
22 | NN | WFO | 1u | RUB | 0.100" | OUT | 0.100"
23 | NN | WFO | 1u | LINE | 0.100" | FEED | 0.100"
24 | NN | WFO | 1u |  |  |  |  |  | 0.100" | blank key
25 | NN | WFO | 1u |  |  |  |  |  | 0.100" | blank key
26 | NN | WFO | 1u |  |  |  |  |  | 0.100" | blank key
27 | NN | WFO | 1.5u |  |  |  |  | TAB | 0.100"

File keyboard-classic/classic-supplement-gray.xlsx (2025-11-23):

Classic Supplement set |  |  |  | Date: |  | 2021-11-29
Order specifications for Signature Plastics keycaps
Colors are specified using Signature Plastics color codes. Reference for colors: https://pimpmykeyboard.com/colors
Reference for key profiles: https://pimpmykeyboard.com/key-cap-family-specs
All keys SA Row 3
Line | Keycap Color | Legend Color | Size | Top | Top font | Bottom | Bottom Font | Centered | Centered Font | Comment
1 | GD | WFO | 1u | { | 0.150" | [ | 0.150"
2 | GD | WFO | 1u | } | 0.150" | ] | 0.150"
3 | GD | WFO | 1u | ^ | 0.150" | ~ | 0.150" |  |  | ^ over ~
4 | GD | WFO | 1u | ~ | 0.150" | ^ | 0.150" |  |  | ~ over ^
5 | GD | WFO | 1u | @ | 0.150" | \ | 0.150" |  |  | grave accent and @
6 | GD | WFO | 1u | ` | 0.150" | @ | 0.150" |  |  | grave accent and @
7 | GD | WFO | 1u | | | 0.150" | \ | 0.150" |  |  | vertical bar and backslash
8 | GD | WFO | 1u |  |  |  |  | ↑ | 0.230" | Up arrow
9 | GD | WFO | 1u |  |  |  |  | ↓ | 0.230" | Down arrow
10 | GD | WFO | 1u |  |  |  |  | TAB | 0.100"
11 | GD | WFO | 1u |  |  |  |  | DELETE | 0.100"
12 | GD | WFO | 1u |  |  |  |  | CLEAR | 0.100"
13 | GD | WFO | 1u |  |  |  |  | SHIFT | 0.100" | 1U SHIFT (left)
14 | GD | WFO | 1u |  |  |  |  | SHIFT | 0.100" | 1U SHIFT (right)
15 | GD | WFO | 1u | HERE | 0.100" | IS | 0.100"
16 | GD | WFO | 1u | SHIFT | 0.100" | LOCK | 0.100"
17 | GD | WFO | 1u | ALPHA | 0.100" | LOCK | 0.100"
18 | GD | WFO | 1u | CAPS | 0.100" | LOCK | 0.100"
19 | GD | WFO | 1u |  |  | N | 0.187"
20 | GD | WFO | 1u |  |  | P | 0.187"
21 | GD | WFO | 1u |  |  | G | 0.187"
22 | GD | WFO | 1u | RUB | 0.100" | OUT | 0.100"
23 | GD | WFO | 1u | LINE | 0.100" | FEED | 0.100"
24 | GD | WFO | 1u |  |  |  |  |  | 0.100" | blank key
25 | GD | WFO | 1u |  |  |  |  |  | 0.100" | blank key
26 | GD | WFO | 1u |  |  |  |  |  | 0.100" | blank key
27 | GD | WFO | 1.5u |  |  |  |  | TAB | 0.100"

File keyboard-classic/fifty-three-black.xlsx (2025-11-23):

Classic Keycap set |  |  |  | Date: |  | 2022-11-18
Order specifications for Signature Plastics keycaps
Colors are specified using Signature Plastics color codes. Reference for colors: https://pimpmykeyboard.com/colors
Reference for key profiles: https://pimpmykeyboard.com/key-cap-family-specs
All keys SA Row 3
Line | Keycap Color | Legend Color | Size | Top | Top font | Bottom | Bottom Font | Centered | Centered Font | Comment
1 | NN | WFO | 1u |  |  | A | 0.187"
2 | NN | WFO | 1u |  |  | B | 0.187"
3 | NN | WFO | 1u |  |  | C | 0.187"
4 | NN | WFO | 1u |  |  | D | 0.187"
5 | NN | WFO | 1u |  |  | E | 0.187"
6 | NN | WFO | 1u |  |  | F | 0.187" |  |  | Deep Dish
7 | NN | WFO | 1u | BELL | 0.100" | G | 0.187"
8 | NN | WFO | 1u |  |  | H | 0.187"
9 | NN | WFO | 1u |  |  | I | 0.187"
10 | NN | WFO | 1u |  |  | J | 0.187" |  |  | Deep Dish
11 | NN | WFO | 1u |  |  | K | 0.187"
12 | NN | WFO | 1u |  |  | L | 0.187"
13 | NN | WFO | 1u |  |  | M | 0.187"
14 | NN | WFO | 1u | ^ | 0.187" | N | 0.187"
15 | NN | WFO | 1u |  |  | O | 0.187"
16 | NN | WFO | 1u | @ | 0.187" | P | 0.187"
17 | NN | WFO | 1u |  |  | Q | 0.187"
18 | NN | WFO | 1u |  |  | R | 0.187"
19 | NN | WFO | 1u |  |  | S | 0.187"
20 | NN | WFO | 1u |  |  | T | 0.187"
21 | NN | WFO | 1u |  |  | U | 0.187"
22 | NN | WFO | 1u |  |  | V | 0.187"
23 | NN | WFO | 1u |  |  | W | 0.187"
24 | NN | WFO | 1u |  |  | X | 0.187"
25 | NN | WFO | 1u |  |  | Y | 0.187"
26 | NN | WFO | 1u |  |  | Z | 0.187"
27 | NN | WFO | 1u | ! | 0.150" | 1 | 0.150"
28 | NN | WFO | 1u | “ | 0.150" | 2 | 0.150"
29 | NN | WFO | 1u | # | 0.150" | 3 | 0.150"
30 | NN | WFO | 1u | $ | 0.150" | 4 | 0.150"
31 | NN | WFO | 1u | % | 0.150" | 5 | 0.150"
32 | NN | WFO | 1u | & | 0.150" | 6 | 0.150"
33 | NN | WFO | 1u | ' | 0.150" | 7 | 0.150" |  |  | straight apostrophe and 7
34 | NN | WFO | 1u | ( | 0.150" | 8 | 0.150"
35 | NN | WFO | 1u | ) | 0.150" | 9 | 0.150"
36 | NN | WFO | 1u |  |  | 0 | 0.150"
37 | NN | WFO | 1u | * | 0.150" | : | 0.150"
38 | NN | WFO | 1u | = | 0.150" | - | 0.150" |  |  | equal and minus
39 | NN | WFO | 1u | + | 0.150" | ; | 0.150"
40 | NN | WFO | 1u | < | 0.150" | , | 0.150" |  |  | < and comma
41 | NN | WFO | 1u | > | 0.150" | . | 0.150" |  |  | > and period
42 | NN | WFO | 1u | ? | 0.150" | / | 0.150"
43 | NN | WFO | 1u |  |  |  |  | → | 0.230" | Right arrow
44 | NN | WFO | 1u |  |  |  |  | ← | 0.230" | Left arrow
45 | NN | WFO | 1u |  |  |  |  | ESC | 0.100"
46 | NN | WFO | 1u |  |  |  |  | CTRL | 0.100"
47 | NN | WFO | 1u |  |  |  |  | REPEAT | 0.100"
48 | NN | WFO | 1u |  |  |  |  | RESET | 0.100"
49 | NN | WFO | 1.5u |  |  |  |  | SHIFT | 0.100" | Left shift
50 | NN | WFO | 1.5u |  |  |  |  | SHIFT | 0.100" | Right shift
51 | NN | WFO | 1.5u |  |  |  |  | RETURN | 0.100"
52 | NN | n/a (no legend) | 8u |  |  |  |  |  |  | Spacebar, leveling posts 5.25" apart
53 | WEL | BLACK | 1u |  |  |  |  | POWER | 0.100" | Pad print legend (lighted key)

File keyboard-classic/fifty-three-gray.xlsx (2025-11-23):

Classic Keycap set |  |  |  | Date: |  | 2021-11-29
Order specifications for Signature Plastics keycaps
Colors are specified using Signature Plastics color codes. Reference for colors: https://pimpmykeyboard.com/colors
Reference for key profiles: https://pimpmykeyboard.com/key-cap-family-specs
All keys SA Row 3
Line | Keycap Color | Legend Color | Size | Top | Top font | Bottom | Bottom Font | Centered | Centered Font | Comment
1 | GD | WFO | 1u |  |  | A | 0.187"
2 | GD | WFO | 1u |  |  | B | 0.187"
3 | GD | WFO | 1u |  |  | C | 0.187"
4 | GD | WFO | 1u |  |  | D | 0.187"
5 | GD | WFO | 1u |  |  | E | 0.187"
6 | GD | WFO | 1u |  |  | F | 0.187" |  |  | Deep Dish
7 | GD | WFO | 1u | BELL | 0.100" | G | 0.187"
8 | GD | WFO | 1u |  |  | H | 0.187"
9 | GD | WFO | 1u |  |  | I | 0.187"
10 | GD | WFO | 1u |  |  | J | 0.187" |  |  | Deep Dish
11 | GD | WFO | 1u |  |  | K | 0.187"
12 | GD | WFO | 1u |  |  | L | 0.187"
13 | GD | WFO | 1u |  |  | M | 0.187"
14 | GD | WFO | 1u | ^ | 0.187" | N | 0.187"
15 | GD | WFO | 1u |  |  | O | 0.187"
16 | GD | WFO | 1u | @ | 0.187" | P | 0.187"
17 | GD | WFO | 1u |  |  | Q | 0.187"
18 | GD | WFO | 1u |  |  | R | 0.187"
19 | GD | WFO | 1u |  |  | S | 0.187"
20 | GD | WFO | 1u |  |  | T | 0.187"
21 | GD | WFO | 1u |  |  | U | 0.187"
22 | GD | WFO | 1u |  |  | V | 0.187"
23 | GD | WFO | 1u |  |  | W | 0.187"
24 | GD | WFO | 1u |  |  | X | 0.187"
25 | GD | WFO | 1u |  |  | Y | 0.187"
26 | GD | WFO | 1u |  |  | Z | 0.187"
27 | GD | WFO | 1u | ! | 0.150" | 1 | 0.150"
28 | GD | WFO | 1u | “ | 0.150" | 2 | 0.150"
29 | GD | WFO | 1u | # | 0.150" | 3 | 0.150"
30 | GD | WFO | 1u | $ | 0.150" | 4 | 0.150"
31 | GD | WFO | 1u | % | 0.150" | 5 | 0.150"
32 | GD | WFO | 1u | & | 0.150" | 6 | 0.150"
33 | GD | WFO | 1u | ' | 0.150" | 7 | 0.150" |  |  | straight apostrophe and 7
34 | GD | WFO | 1u | ( | 0.150" | 8 | 0.150"
35 | GD | WFO | 1u | ) | 0.150" | 9 | 0.150"
36 | GD | WFO | 1u |  |  | 0 | 0.150"
37 | GD | WFO | 1u | * | 0.150" | : | 0.150"
38 | GD | WFO | 1u | = | 0.150" | - | 0.150" |  |  | equal and minus
39 | GD | WFO | 1u | + | 0.150" | ; | 0.150"
40 | GD | WFO | 1u | < | 0.150" | , | 0.150" |  |  | < and comma
41 | GD | WFO | 1u | > | 0.150" | . | 0.150" |  |  | > and period
42 | GD | WFO | 1u | ? | 0.150" | / | 0.150"
43 | GD | WFO | 1u |  |  |  |  | → | 0.230" | Right arrow
44 | GD | WFO | 1u |  |  |  |  | ← | 0.230" | Left arrow
45 | GD | WFO | 1u |  |  |  |  | ESC | 0.100"
46 | GD | WFO | 1u |  |  |  |  | CTRL | 0.100"
47 | GD | WFO | 1u |  |  |  |  | REPEAT | 0.100"
48 | GD | WFO | 1u |  |  |  |  | RESET | 0.100"
49 | GD | WFO | 1.5u |  |  |  |  | SHIFT | 0.100" | Left shift
50 | GD | WFO | 1.5u |  |  |  |  | SHIFT | 0.100" | Right shift
51 | GD | WFO | 1.5u |  |  |  |  | RETURN | 0.100"
52 | GD | n/a (no legend) | 8u |  |  |  |  |  |  | Spacebar, leveling posts 5.25" apart
53 | WEL | BLACK | 1u |  |  |  |  | POWER | 0.100" | Pad print legend (lighted key)

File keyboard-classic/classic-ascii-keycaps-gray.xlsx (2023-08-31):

Classic Keycap set |  |  |  | Date: |  | 2021-11-29
Order specifications for Signature Plastics keycaps
Colors are specified using Signature Plastics color codes. Reference for colors: https://pimpmykeyboard.com/colors
Reference for key profiles: https://pimpmykeyboard.com/key-cap-family-specs
All keys SA Row 3
Line | Keycap Color | Legend Color | Size | Top | Top font | Bottom | Bottom Font | Centered | Centered Font | Comment
1 | GD | WFO | 1u |  |  | A | 0.187"
2 | GD | WFO | 1u |  |  | B | 0.187"
3 | GD | WFO | 1u |  |  | C | 0.187"
4 | GD | WFO | 1u |  |  | D | 0.187"
5 | GD | WFO | 1u |  |  | E | 0.187"
6 | GD | WFO | 1u |  |  | F | 0.187" |  |  | Deep Dish
7 | GD | WFO | 1u | BELL | 0.100" | G | 0.187"
8 | GD | WFO | 1u |  |  | G | 0.187"
9 | GD | WFO | 1u |  |  | H | 0.187"
10 | GD | WFO | 1u |  |  | I | 0.187"
11 | GD | WFO | 1u |  |  | J | 0.187" |  |  | Deep Dish
12 | GD | WFO | 1u |  |  | K | 0.187"
13 | GD | WFO | 1u |  |  | L | 0.187"
14 | GD | WFO | 1u |  |  | M | 0.187"
15 | GD | WFO | 1u |  |  | N | 0.187"
16 | GD | WFO | 1u | ^ | 0.187" | N | 0.187"
17 | GD | WFO | 1u |  |  | O | 0.187"
18 | GD | WFO | 1u |  |  | P | 0.187"
19 | GD | WFO | 1u | @ | 0.187" | P | 0.187"
20 | GD | WFO | 1u |  |  | Q | 0.187"
21 | GD | WFO | 1u |  |  | R | 0.187"
22 | GD | WFO | 1u |  |  | S | 0.187"
23 | GD | WFO | 1u |  |  | T | 0.187"
24 | GD | WFO | 1u |  |  | U | 0.187"
25 | GD | WFO | 1u |  |  | V | 0.187"
26 | GD | WFO | 1u |  |  | W | 0.187"
27 | GD | WFO | 1u |  |  | X | 0.187"
28 | GD | WFO | 1u |  |  | Y | 0.187"
29 | GD | WFO | 1u |  |  | Z | 0.187"
30 | GD | WFO | 1u | ! | .150" | .150" | 0.187"
31 | GD | WFO | 1u | “ | .150" | .150" | 0.187"
32 | GD | WFO | 1u | # | .150" | .150" | 0.187"
33 | GD | WFO | 1u | $ | .150" | .150" | 0.187"
34 | GD | WFO | 1u | % | .150" | .150" | 0.187"
35 | GD | WFO | 1u | & | .150" | .150" | 0.187"
36 | GD | WFO | 1u | ' | .150" | .150" | 0.187" |  |  | straight apostrophe and 7
37 | GD | WFO | 1u | ( | .150" | .150" | 0.187"
38 | GD | WFO | 1u | ) | .150" | .150" | 0.187"
39 | GD | WFO | 1u |  |  | .150" | 0.187"
40 | GD | WFO | 1u | * | .150" | .150" | 0.187"
41 | GD | WFO | 1u | = | .150" | .150" | 0.187" |  |  | equal and minus
42 | GD | WFO | 1u | + | .150" | .150" | 0.187"
43 | GD | WFO | 1u | < | .150" | .150" | 0.187" |  |  | < and comma
44 | GD | WFO | 1u | > | .150" | .150" | 0.187" |  |  | > and period
45 | GD | WFO | 1u | ? | .150" | .150" | 0.187"
46 | GD | WFO | 1u | { | .150" | .150" | 0.187"
47 | GD | WFO | 1u | } | .150" | .150" | 0.187"
48 | GD | WFO | 1u | ~ | .150" | .150" | 0.187"
49 | GD | WFO | 1u | ` | .150" | .150" | 0.187" |  |  | grave accent and @
50 | GD | WFO | 1u | | | .150" | .150" | 0.187" |  |  | vertical bar and backslash
51 | GD | WFO | 1u |  |  |  |  | → | 0.230" | Right arrow
52 | GD | WFO | 1u |  |  |  |  | ← | 0.230" | Left arrow
53 | GD | WFO | 1u |  |  |  |  | ↑ | 0.230" | Up arrow
54 | GD | WFO | 1u |  |  |  |  | ↓ | 0.230" | Down arrow
55 | GD | WFO | 1u |  |  |  |  | ESC | 0.100"
56 | GD | WFO | 1u |  |  |  |  | CTRL | 0.100"
57 | GD | WFO | 1u |  |  |  |  | REPEAT | 0.100"
58 | GD | WFO | 1u |  |  |  |  | BREAK | 0.100"
59 | GD | WFO | 1u |  |  |  |  | TAB | 0.100"
60 | GD | WFO | 1u |  |  |  |  | RESET | 0.100"
61 | GD | WFO | 1u |  |  |  |  | CLEAR | 0.100"
62 | GD | WFO | 1u | RUB | 0.100" | OUT | 0.100"
63 | GD | WFO | 1u | LINE | 0.100" | FEED | 0.100"
64 | GD | WFO | 1u | SHIFT | 0.100" | LOCK | 0.100"
65 | GD | WFO | 1u | CAPS | 0.100" | LOCK | 0.100"
66 | GD | WFO | 1u | HERE | 0.100" | IS | 0.100"
67 | GD | WFO | 1.5u |  |  |  |  | SHIFT | 0.100" | Left shift
68 | GD | WFO | 1.5u |  |  |  |  | SHIFT | 0.100" | Right shift
69 | GD | WFO | 1.5u |  |  |  |  | RETURN | 0.100"
70 | GD | WFO | 1.5u |  |  |  |  | TAB | 0.100"
71 | GD | n/a (no legend) | 8u |  |  |  |  |  |  | Spacebar
72 | WEL | BLACK | 1u |  |  |  |  | POWER | 0.100" | Pad print legend (lighted key)

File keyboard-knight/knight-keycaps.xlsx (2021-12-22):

Knight Keycap set |  |  |  | Date: |  | 2021-12-20
Order specifications for Signature Plastics keycaps
Colors are specified using Signature Plastics color codes. Reference for colors: https://pimpmykeyboard.com/colors
Reference for key profiles: https://pimpmykeyboard.com/key-cap-family-specs
All keys SA Row 3
Line | Keycap Color | Legend Color | Size | Top | Top font | Bottom | Bottom Font | Centered | Centered Font | Comment
1 | GY | WFO | 1u | ≤ | 0.187" | A | 0.187" |  |  | less than or equal
2 | GY | WFO | 1u | π | 0.187" | B | 0.187" |  |  | greek pi
3 | GY | WFO | 1u | ϵ | 0.187" | C | 0.187" |  |  | lunate epsilon
4 | GY | WFO | 1u | ≡ | 0.187" | D | 0.187" |  |  | equivalent
5 | GY | WFO | 1u | ∩ | 0.187" | E | 0.187" |  |  | set intersection
6 | GY | WFO | 1u | ∂ | 0.187" | F | 0.187" |  |  | partial differential
7 | GY | WFO | 1u | ≠ | 0.187" | G | 0.187" |  |  | not equals
8 | GY | WFO | 1u | HELP | 0.100" | H | 0.187"
9 | GY | WFO | 1u | ⊗ | 0.187" | I | 0.187"
10 | GY | WFO | 1u | ← | 0.187" | J | 0.187" |  |  | left arrow
11 | GY | WFO | 1u | → | 0.187" | K | 0.187" |  |  | right arrow
12 | GY | WFO | 1u | ↔ | 0.187" | L | 0.187" |  |  | double arrow
13 | GY | WFO | 1u | ∃ | 0.187" | M | 0.187" |  |  | there exists
14 | GY | WFO | 1u | ∀ | 0.187" | N | 0.187" |  |  | for all
15 | GY | WFO | 1u | ↓ | 0.187" | O | 0.187" |  |  | down arrow
16 | GY | WFO | 1u | ↑ | 0.187" | P | 0.187" |  |  | up arrow
17 | GY | WFO | 1u | ∧ | 0.187" | Q | 0.187" |  |  | logical and
18 | GY | WFO | 1u | ∪ | 0.187" | R | 0.187" |  |  | set union
19 | GY | WFO | 1u | ≥ | 0.187" | S | 0.187" |  |  | greater than or equal
20 | GY | WFO | 1u | ⊂ | 0.187" | T | 0.187" |  |  | subset
21 | GY | WFO | 1u | ¬ | 0.187" | U | 0.187" |  |  | logical not
22 | GY | WFO | 1u | λ | 0.187" | V | 0.187" |  |  | greek lambda
23 | GY | WFO | 1u | ∨ | 0.187" | W | 0.187" |  |  | logical or
24 | GY | WFO | 1u | β | 0.187" | X | 0.187" |  |  | greek beta
25 | GY | WFO | 1u | ⊃ | 0.187" | Y | 0.187" |  |  | superset
26 | GY | WFO | 1u | α | 0.187" | Ƶ | 0.187" |  |  | z with stroke, greek alpha
27 | GY | WFO | 1u | ! | 0.187" | 1 | 0.187"
28 | GY | WFO | 1u | " | 0.187" | 2 | 0.187"
29 | GY | WFO | 1u | # | 0.187" | 3 | 0.187"
30 | GY | WFO | 1u | $ | 0.187" | 4 | 0.187"
31 | GY | WFO | 1u | % | 0.187" | 5 | 0.187"
32 | GY | WFO | 1u | & | 0.187" | 6 | 0.187"
33 | GY | WFO | 1u | ´ | 0.187" | 7 | 0.187" |  |  | acute accent
34 | GY | WFO | 1u | ( | 0.187" | 8 | 0.187"
35 | GY | WFO | 1u | ) | 0.187" | 9 | 0.187"
36 | GY | WFO | 1u | _ | 0.187" | ∅ | 0.187" |  |  | underscore, zero with slash
37 | BFP | WFO | 1u | * | 0.187" | : | 0.187"
38 | BFP | WFO | 1u | = | 0.187" | - | 0.187" |  |  | equal, minus
39 | GY | WFO | 1u | + | 0.187" | ; | 0.187"
40 | GY | WFO | 1u | < | 0.187" | , | 0.187" |  |  | < and comma
41 | GY | WFO | 1u | > | 0.187" | . | 0.187" |  |  | > and period
42 | GY | WFO | 1u | ? | 0.187" | / | 0.187"
43 | BFP | WFO | 1u | { | 0.187" | [ | 0.187"
44 | BFP | WFO | 1u | } | 0.187" | ] | 0.187"
45 | BFP | WFO | 1u | ~ | 0.187" | ^ | 0.187"
46 | BFP | WFO | 1u | ` | 0.187" | @ | 0.187" |  |  | grave accent and @
47 | BFP | WFO | 1.5u | | | 0.187" | \ | 0.187" |  |  | vertical bar and backslash
48 | BFP | WFO | 1u | ∞ | 0.187" | / | 0.187" |  |  | infinity
49 | BFP | WFO | 1u | Δ | 0.187" | ⊖ | 0.187"
50 | BFP | WFO | 1u | ∇ | 0.187" | ⊕ | 0.187"
51 | BFP | WFO | 1u |  |  |  |  | BREAK | 0.100"
52 | BFP | WFO | 2u |  |  |  |  | ESC | 0.100"
53 | BFP | WFO | 2u |  |  |  |  | BS | 0.100"
54 | BFP | WFO | 2u |  |  |  |  | CALL | 0.100"
55 | BFP | WFO | 1u |  |  |  |  | CLEAR | 0.100"
56 | BFP | WFO | 1.5u |  |  |  |  | TAB | 0.100"
57 | BFP | WFO | 1u |  |  |  |  | ALT | 0.100"
58 | BFP | WFO | 1u |  |  |  |  | FORM | 0.100"
59 | BFP | WFO | 1u |  |  |  |  | VT | 0.100"
60 | BFP | WFO | 1.75u |  |  |  |  | RUB OUT | 0.100"
61 | BFP | WFO | 2u |  |  |  |  | RETURN | 0.100"
62 | BFP | WFO | 1.25u |  |  |  |  | LINE | 0.100"
63 | BFP | WFO | 1u | BACK | 0.100" | NEXT | 0.100"
64 | BFP | WFO | 1u | SHIFT | 0.100" | LOCK | 0.100"
65 | BFP | WFO | 1.25u |  |  |  |  | TOP | 0.100" | left
66 | BFP | WFO | 2u |  |  |  |  | SHIFT | 0.100" | left
67 | BFP | WFO | 1.75u |  |  |  |  | SHIFT | 0.100" | right shift
68 | BFP | WFO | 2u |  |  |  |  | TOP | 0.100" | right
69 | BFP | WFO | 1.5u |  |  |  |  | META | 0.100" | left
70 | BFP | WFO | 1.5u |  |  |  |  | CTRL | 0.100" | left
71 | BFP | WFO | 1.5u |  |  |  |  | CTRL | 0.100" | right
72 | BFP | WFO | 1.5u |  |  |  |  | META | 0.100" | right
73 | BFP | n/a (no legend) | 8u |  |  |  |  |  |  | spacebar

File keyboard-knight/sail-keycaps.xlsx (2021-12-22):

SAIL Keycap set |  |  |  | Date: |  | 2021-12-21
Order specifications for Signature Plastics keycaps
Colors are specified using Signature Plastics color codes. Reference for colors: https://pimpmykeyboard.com/colors
Reference for key profiles: https://pimpmykeyboard.com/key-cap-family-specs
All keys SA Row 3
Line | Keycap Color | Legend Color | Size | Top | Top font | Bottom | Bottom Font | Centered | Centered Font | Comment
1 | BFT | WFO | 1u | ≤ | 0.187" | A | 0.187" |  |  | less than or equal
2 | BFT | WFO | 1u | π | 0.187" | B | 0.187" |  |  | greek pi
3 | BFT | WFO | 1u | ϵ | 0.187" | C | 0.187" |  |  | lunate epsilon
4 | BFT | WFO | 1u | < | 0.187" | D | 0.187"
5 | BFT | WFO | 1u | @ | 0.187" | E | 0.187"
6 | BFT | WFO | 1u | > | 0.187" | F | 0.187"
7 | BFT | WFO | 1u | ≠ | 0.187" | G | 0.187" |  |  | not equals
8 | BFT | WFO | 1u | = | 0.100" | H | 0.187"
9 | BFT | WFO | 1u | ´ | 0.187" | I | 0.187" |  |  | acute accent
10 | BFT | WFO | 1u | ← | 0.187" | J | 0.187" |  |  | left arrow
11 | BFT | WFO | 1u | → | 0.187" | K | 0.187" |  |  | right arrow
12 | BFT | WFO | 1u | ↔ | 0.187" | L | 0.187" |  |  | double arrow
13 | BFT | WFO | 1u | ∃ | 0.187" | M | 0.187" |  |  | there exists
14 | BFT | WFO | 1u | ∀ | 0.187" | N | 0.187" |  |  | for all
15 | BFT | WFO | 1u | { | 0.187" | O | 0.187"
16 | BFT | WFO | 1u | } | 0.187" | P | 0.187"
17 | BFT | WFO | 1u | ∧ | 0.187" | Q | 0.187" |  |  | logical and
18 | BFT | WFO | 1u | # | 0.187" | R | 0.187"
19 | BFT | WFO | 1u | ≥ | 0.187" | S | 0.187" |  |  | greater than or equal
20 | BFT | WFO | 1u | & | 0.187" | T | 0.187"
21 | BFT | WFO | 1u | ` | 0.187" | U | 0.187" |  |  | grave accent
22 | BFT | WFO | 1u | λ | 0.187" | V | 0.187" |  |  | greek lambda
23 | BFT | WFO | 1u | ∨ | 0.187" | W | 0.187" |  |  | logical or
24 | BFT | WFO | 1u | β | 0.187" | X | 0.187" |  |  | greek beta
25 | BFT | WFO | 1u | “ | 0.187" | Y | 0.187"
26 | BFT | WFO | 1u | α | 0.187" | Ƶ | 0.187" |  |  | z with stroke, greek alpha
27 | BFT | WFO | 1u | ≡ | 0.187" | 1 | 0.187" |  |  | equivalent
28 | BFT | WFO | 1u | ∩ | 0.187" | 2 | 0.187" |  |  | set intersection
29 | BFT | WFO | 1u | ∪ | 0.187" | 3 | 0.187" |  |  | set union
30 | BFT | WFO | 1u | ⊂ | 0.187" | 4 | 0.187" |  |  | subset
31 | BFT | WFO | 1u | ⊃ | 0.187" | 5 | 0.187" |  |  | superset
32 | BFT | WFO | 1u | $ | 0.187" | 6 | 0.187"
33 | BFT | WFO | 1u | % | 0.187" | 7 | 0.187"
34 | BFT | WFO | 1u | ~ | 0.187" | 8 | 0.187"
35 | BFT | WFO | 1u | _ | 0.187" | 9 | 0.187"
36 | BFT | WFO | 1u |  |  |  |  | Ø | 0.200" | zero with slash
37 | BFT | WFO | 1u | ↓ | 0.187" | : | 0.187" |  |  | down arrow
38 | BFT | WFO | 1u | ¬ | 0.187" | - | 0.187" |  |  | logical not, minus
39 | BFT | WFO | 1u | ↑ | 0.187" | ; | 0.187" |  |  | up arrow
40 | BFT | WFO | 1u | ! | 0.187" | , | 0.187"
41 | BFT | WFO | 1u | ? | 0.187" | . | 0.187"
42 | BFT | WFO | 1u | ∂ | 0.187" | / | 0.187" |  |  | partial differential
43 | BFT | WFO | 1u | [ | 0.187" | ( | 0.187"
44 | BFT | WFO | 1u | ] | 0.187" | ) | 0.187"
45 | BFT | WFO | 1u | ⊗ | 0.187" | * | 0.187"
46 | BFT | WFO | 1u | | | 0.187" | + | 0.187" |  |  | vertical bar
47 | BFT | WFO | 1u | ∞ | 0.187" | \ | 0.187" |  |  | infinity
48 | BFT | WFO | 1u |  |  |  |  | BREAK | 0.100"
49 | BFT | WFO | 1.5u |  |  |  |  | ESC | 0.100"
50 | BFT | WFO | 1.5u |  |  |  |  | BS | 0.100"
51 | BFT | WFO | 1.5u |  |  |  |  | CALL | 0.100"
52 | BFT | WFO | 1u |  |  |  |  | CLEAR | 0.100"
53 | BFT | WFO | 2u |  |  |  |  | TAB | 0.100"
54 | BFT | WFO | 1u |  |  |  |  | ALT | 0.100"
55 | BFT | WFO | 1u |  |  |  |  | FORM | 0.100"
56 | BFT | WFO | 1u |  |  |  |  | VT | 0.100"
57 | BFT | WFO | 1.5u |  |  |  |  | RETURN | 0.100"
58 | BFT | WFO | 1u |  |  |  |  | LINE | 0.100"
59 | BFT | WFO | 1u | SHIFT | 0.100" | LOCK | 0.100"
60 | BFT | WFO | 1u |  |  |  |  | TOP | 0.100" | left
61 | BFT | WFO | 2u |  |  |  |  | SHIFT | 0.100" | left
62 | BFT | WFO | 2u |  |  |  |  | SHIFT | 0.100" | right
63 | BFT | WFO | 1u |  |  |  |  | TOP | 0.100" | right
64 | BFT | WFO | 2u |  |  |  |  | META | 0.100" | left
65 | BFT | WFO | 2u |  |  |  |  | CTRL | 0.100" | left
66 | BFT | WFO | 2u |  |  |  |  | CTRL | 0.100" | right
67 | BFT | WFO | 2u |  |  |  |  | META | 0.100" | right
68 | BFT | n/a (no legend) | 3u |  |  |  |  |  |  | spacebar

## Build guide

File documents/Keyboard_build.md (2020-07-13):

# Keyboard build notes
## Preparing the Keyboard PCB
I recommend installing the diodes and resistors at ALL switch positions.  Doing so will allow you to install additional switches later, and will give you flexibility to modify the keymap.  Installing the components is easiest before the switches are installed.

1. The keyboard is too big for most PCB holders. To keep the components flat as
   you insert them, I suggest taping the keyboard PCB to the edge of your bench,
   and install two rows at a time.

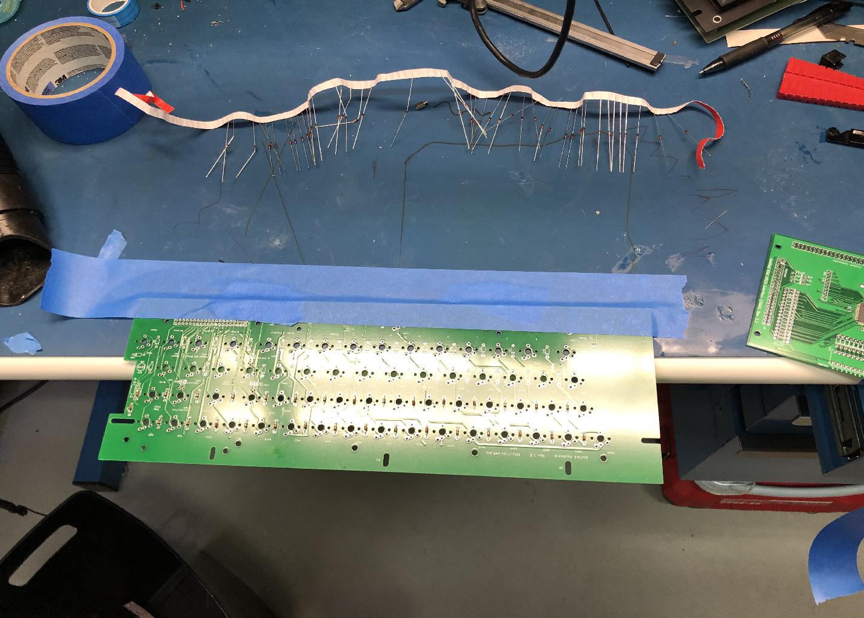
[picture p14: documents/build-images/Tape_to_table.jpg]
Secure the PCB with space for the leads
   

1. Using a lead-bender will help speed up the process and can help produce a
   neater result. However, neatness is not critical, as the diodes will be
   mostly hidden.
   
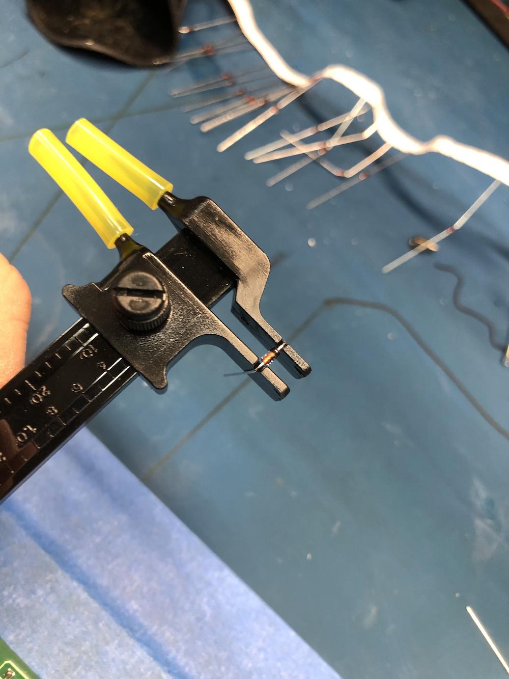
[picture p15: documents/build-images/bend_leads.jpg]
Lead bending tool
   

1. Check that the diodes are all facing the same (correct) direction.

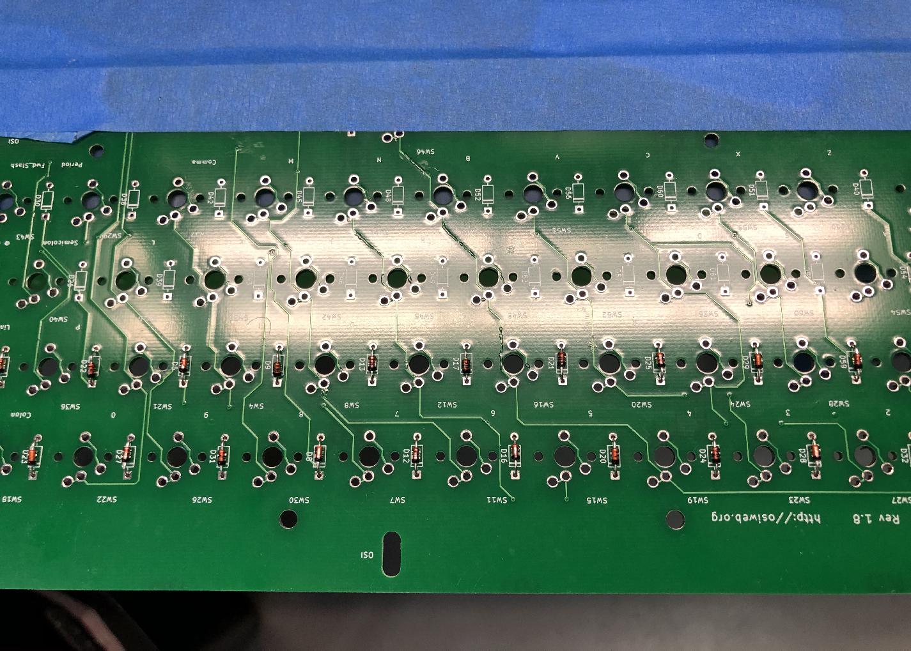
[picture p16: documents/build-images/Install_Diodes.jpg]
   

1. Once the diodes are inserted, I suggest using a piece of painters tape to
   keep then in place when you flip over the board for soldering.

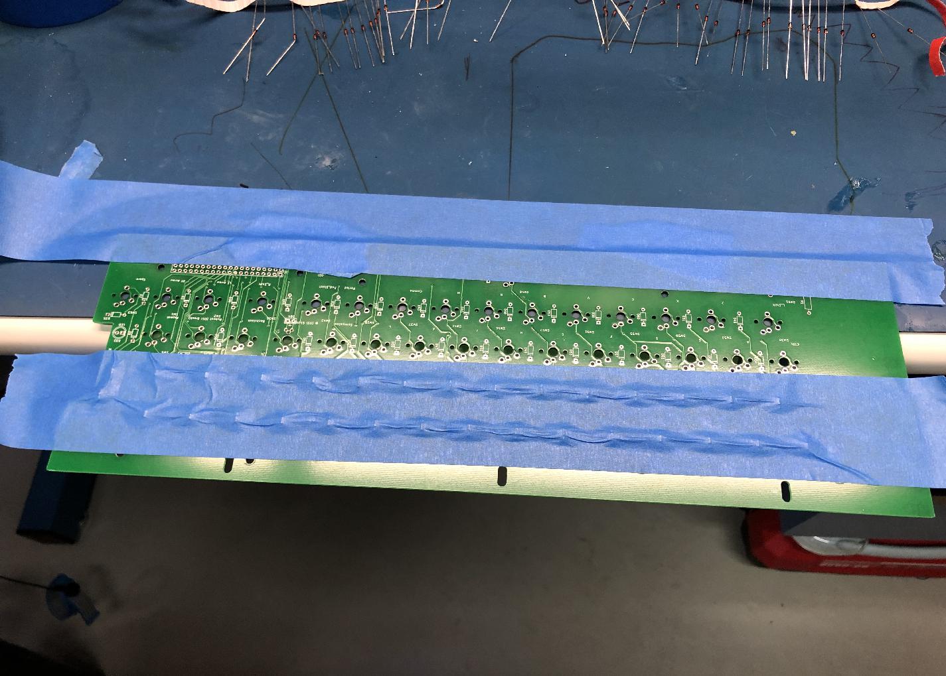
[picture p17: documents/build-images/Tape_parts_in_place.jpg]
Use Painters' tape to secure components
   

1. After installing the diodes, install all the through-hole resistors.

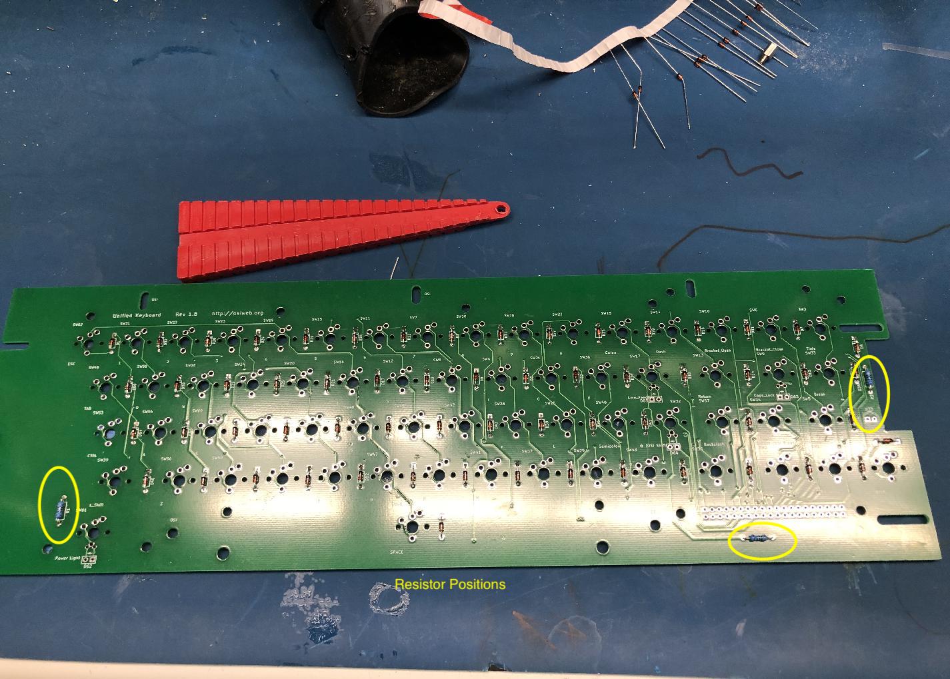
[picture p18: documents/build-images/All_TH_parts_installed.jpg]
All parts installed
   

1. Finally, flip over the PCB and install the 40-pin connector on the back side
   (opposite side from the diodes and resistors).
   
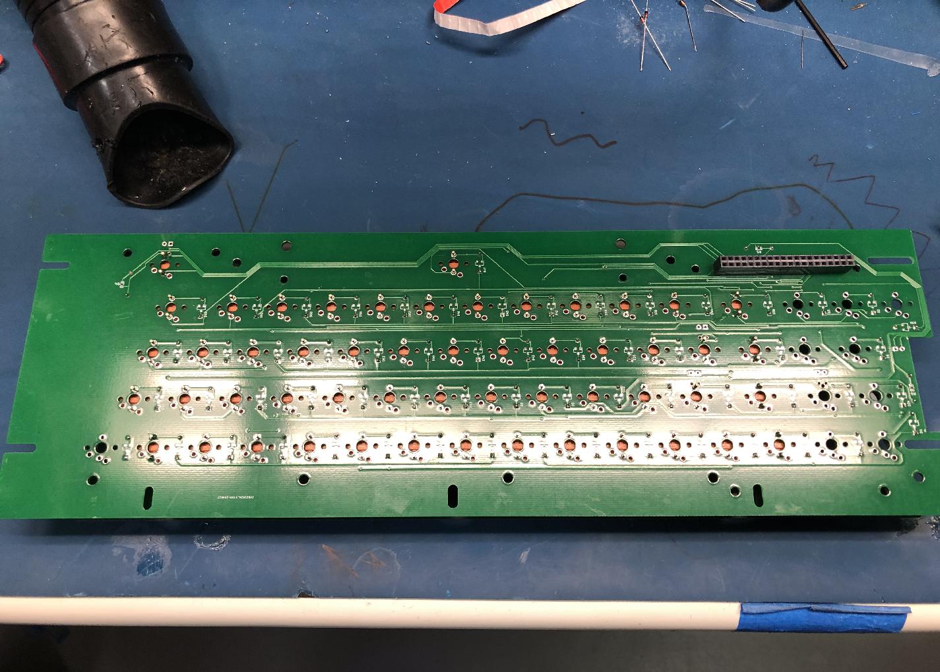
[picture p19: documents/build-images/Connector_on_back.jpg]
Connector is opposite side fromg the through-hole components
   

1. It's important that the connector is seated flat to the PCB. To ensure a
   properly seated connector, first tack pins on opposite corners of the
   connector. Then, applying heat to one tacked pin, press the connector flat
   onto the PCB. You will feel a small "snap" as the connector seats. Repeat for
   the other tacked pin.

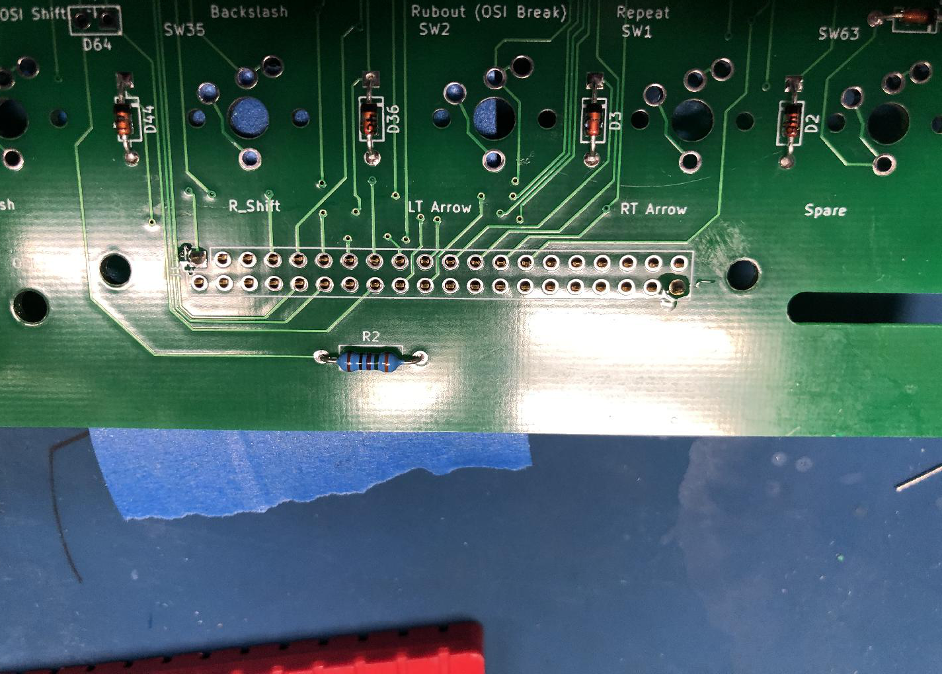
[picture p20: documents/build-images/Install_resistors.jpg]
Tack corners of connector for flush install
   

## Preparing the Aligner (futaba)

## Combining the PCB and aligner (futaba switches)
For futaba switches, no standoffs are required between the aligner and PCB,
   since the futaba switches provide sufficently sturdy mechanical support.
   
1. For the futaba aligners, the simplest way to assemble is to install all the
   key switches in the aligner by press-fitting them into place. Install the
   switches necessary for the keyboard you plan to build. Shown below is the
   switch configuration for the Apple II+ keyboard.
   
1. Install the cherry MX PCB-mount stabilizers onto the PCB.

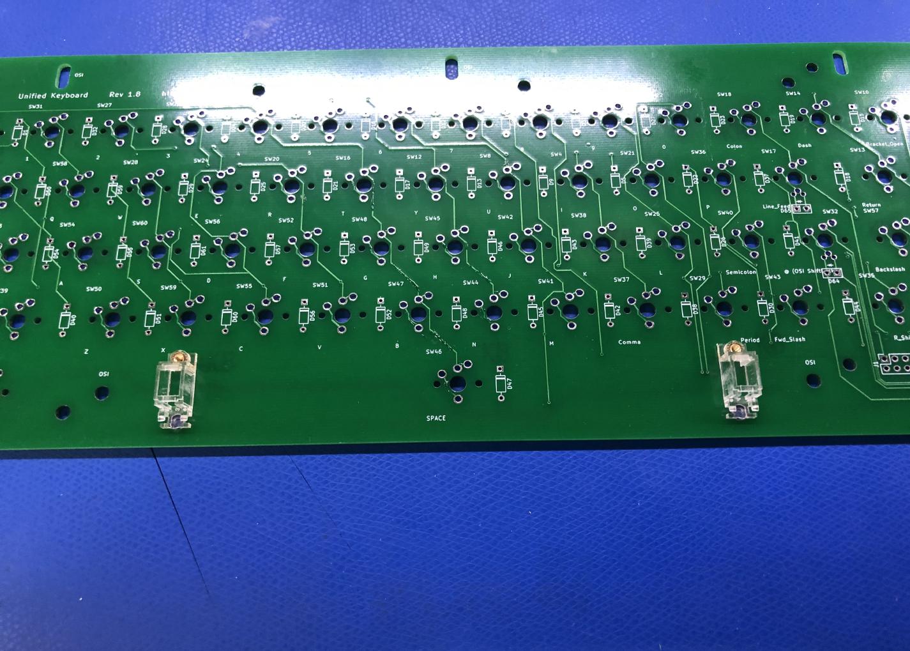
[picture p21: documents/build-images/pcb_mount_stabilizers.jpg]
Install the stabilizers
   

1. Line up the pins of the switches in the aligner assembly with the PCB. The
   two assemblies should "zip" together easily. If you feel resistance, take the
   assemblies apart and check the pins on all the switches to make sure none are
   bent.

1. Once the assemblies are combined, it's important to make sure that the
   switches are seated flush on the PCB. To do this, first tack ONE pin on each
   of the four switches at the corners of the keyboard.
   
1. Now, one by one, reheat each tacked pin while pressing the corresponding
   switch tightly against the PCB. You should feel a small "snap" as the key
   seats. Remove the heat, and repeat for the pins on all four corners. Finally,
   solder the second pin on each of the four corner keys.

1. Repeat the above for the spacebar and the middle key on the top row.

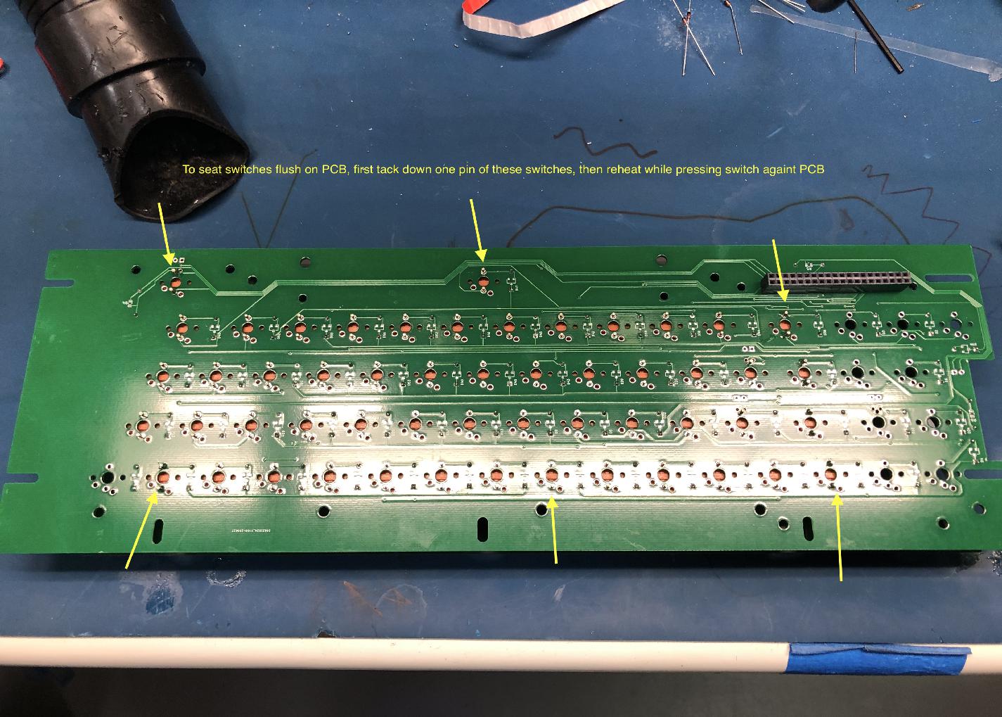
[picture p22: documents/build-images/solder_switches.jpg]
Tack down switches at the edges first
   

1. Now, solder in all the other keys.

### The Spacebar Stabilizer
#### Cherry MX keys
##### Stabilizer hardware
The keyboard is designed to accommodate PCB-mounted Cherry-MX compatible Spacebar aligner hardware.  Most standard aligner kits come with pre-bend rods for a 6.25u spacebar.  Since the 8u spacebar in the retro-keyboards, you will need to bend your own rod.  I have included some sources for the rods below (1).
##### Bending the stabilizer rod
The aligner PCB includes a guide for bending the stabilizer.

1. Start by creating a 90 degree bend about 2 cm from the end of the rod.  This allows enough room to clip the end down to the correct length later.

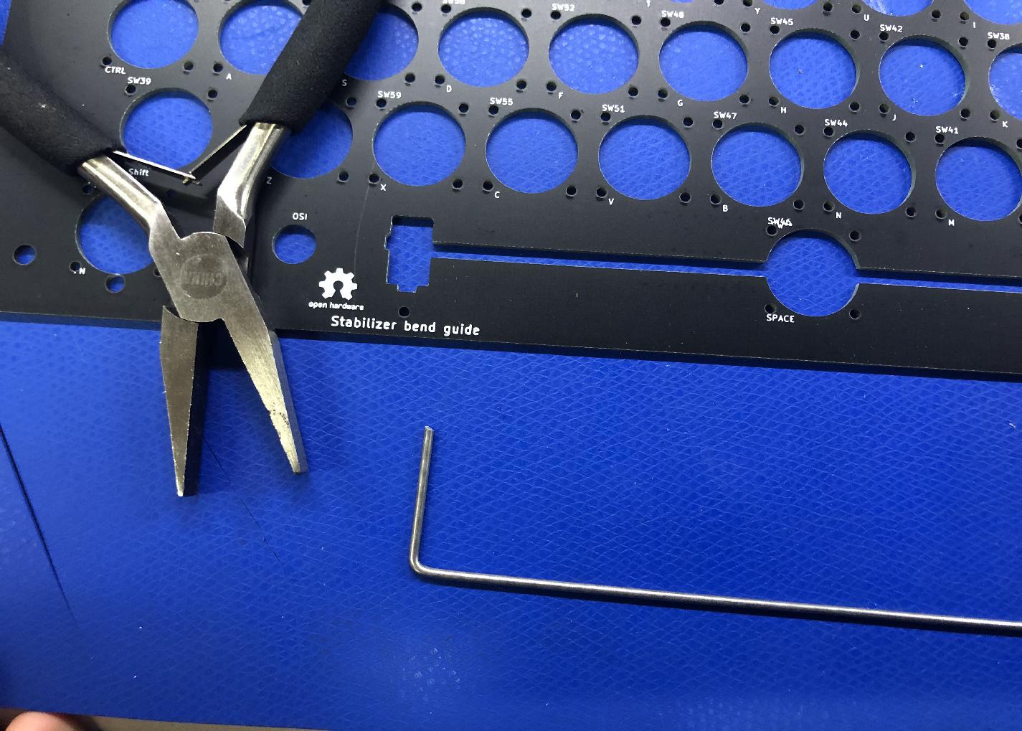
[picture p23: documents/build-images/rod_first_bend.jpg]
First Bend
    

1. Insert the bent end into one guide hole, and, keeping the rod as flat to the board as possible, use the second guide hole to estimate the position of the second bend.  Your estimate should be about 1mm short to allow for a bending radius.  Once you have the pliers positioned on the rod, make your 90 degree bend.

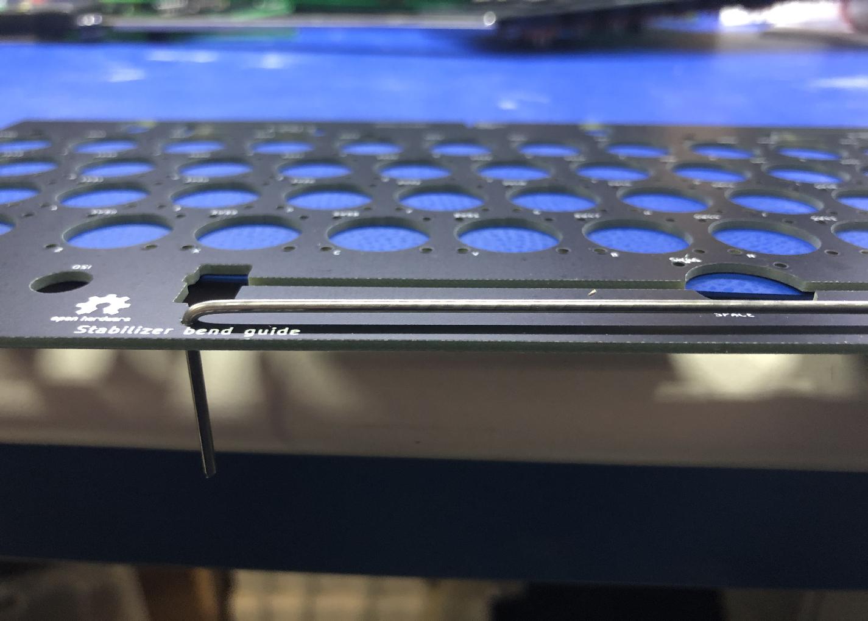
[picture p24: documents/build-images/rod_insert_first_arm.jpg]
Insert Rod in Guide
    

1. Look along the length of the rod to make sure that both "arms" are in line.  If necessary, align the two arms by twisting about the axis of the axis of the rod.

1. Test the fit of the rod by inserting it into the guide holes.  Adjust as needed.

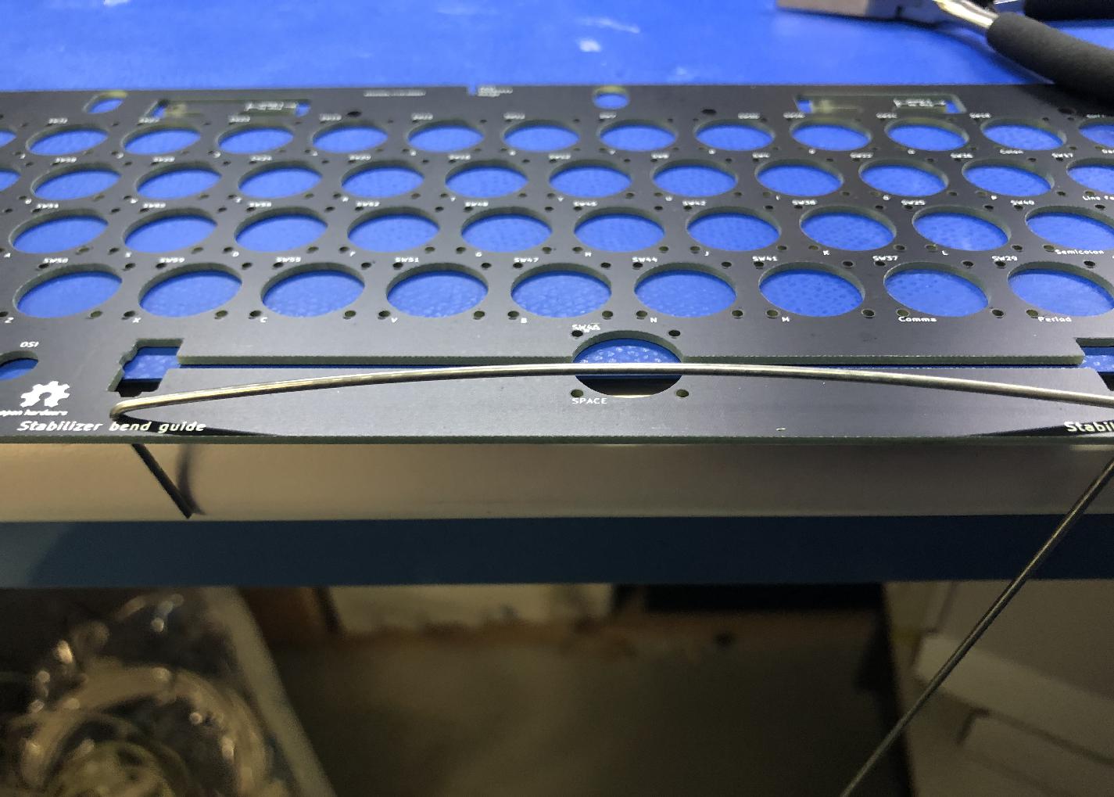
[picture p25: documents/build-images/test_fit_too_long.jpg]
Test Fit
    

1. Clip the arms of the rod to about 11 mm.

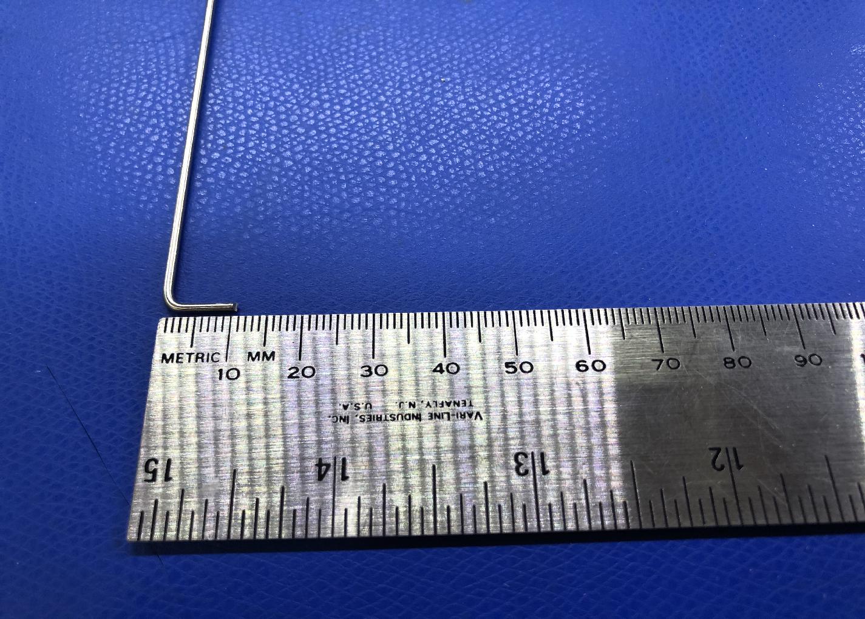
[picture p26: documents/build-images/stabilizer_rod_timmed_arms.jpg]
Clip Arms to Length
    

1. Install the Cherry MX stabilizers to the board.

1. Install the spacebar and insert the rod.

#### Futaba MD4-PCS keys
##### Stabilizer hardware
See the Cherry MX section above for notes on installing the Cherry MX stabilizer hardware and bending the spacebar stabilizer rod.

##### Longer Stabilizer posts for Futaba

The Futaba aligner PCB includes two stabilizer posts, allowing the futaba keys to be used with the Cherry MX PCB-mount stabilizers.

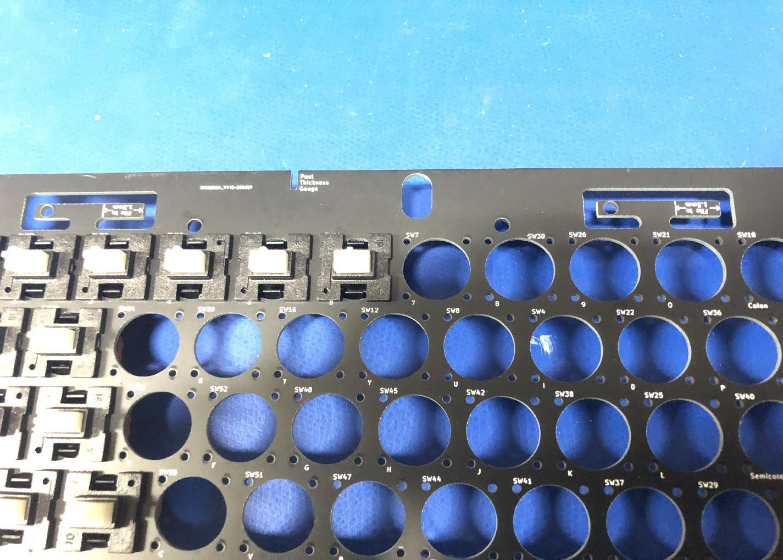
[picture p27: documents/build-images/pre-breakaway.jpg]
Futaba stabilizer adapter posts


1. Remove both posts from the PCB.  Newer revisions of the aligner board include perforations for easier break-away of the posts.

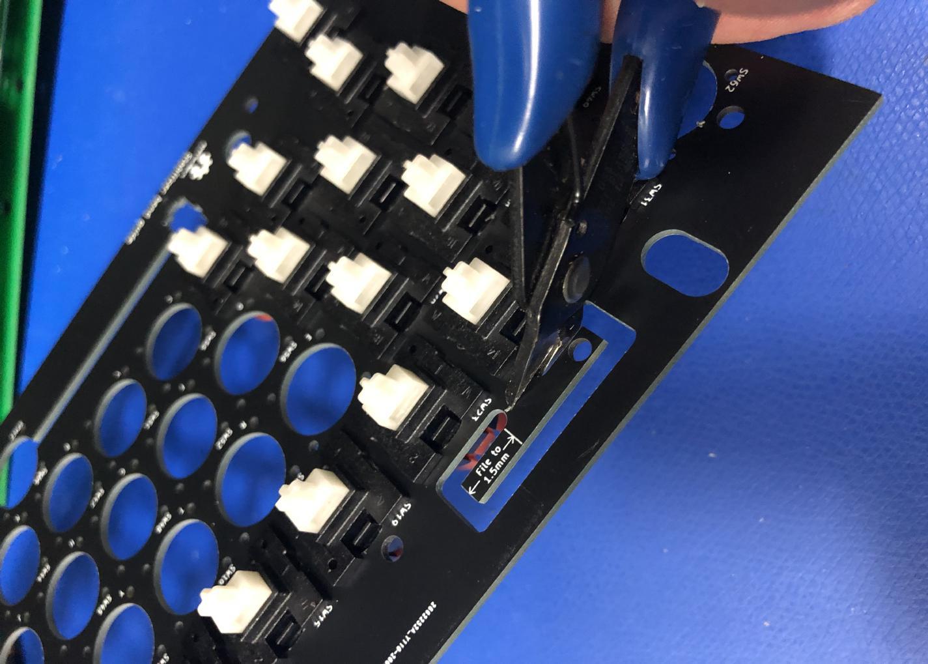
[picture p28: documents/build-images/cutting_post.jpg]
Break away posts from aligner
    

1. Be sure to file away any excess material from the breakaway tab.

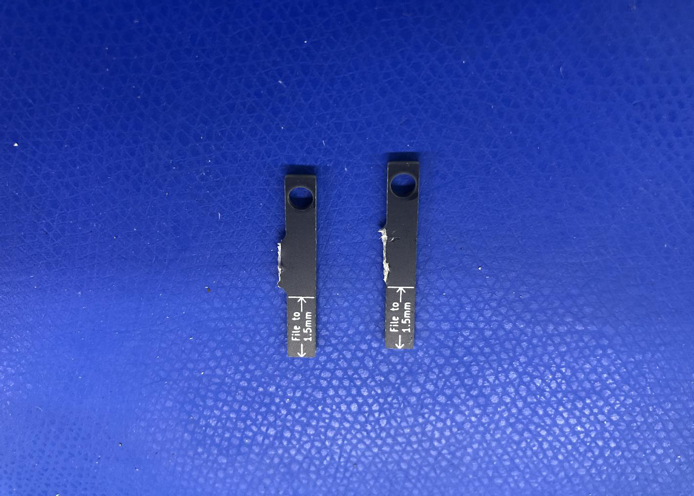
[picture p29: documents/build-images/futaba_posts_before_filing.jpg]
Broken offfiling
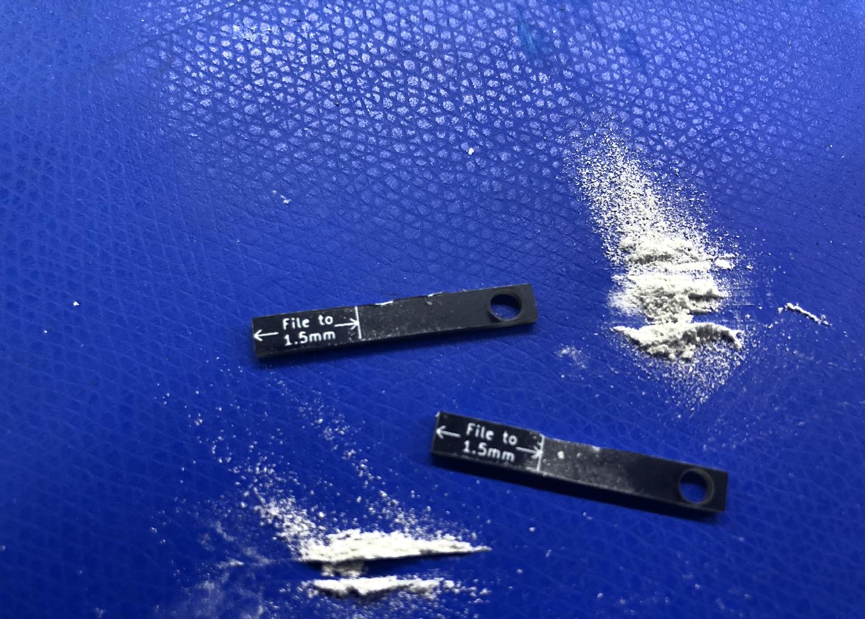
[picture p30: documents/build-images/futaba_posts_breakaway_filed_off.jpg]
Removed breakaway tabs
     

1. File away the area marked "File to 1.5mm".  The aligner includes a thickness gauge to test fitting, but it turns out that manufacturing tolerances are not adequate, and the gauge is not reliable.  Use a spare key cap to test the thickness.  The post should require some pressure to inert into the keycap base.

1. The post should be just under 4mm wide.  The post in this example is an early revision that was specified at 4mm, and ended being a sliver too wide to fit the keycap base.  It required a alittle extra filing along one side to fit properly.  The posts on newer revs are thinner and should not require extra filing to narrow side-to-side width.

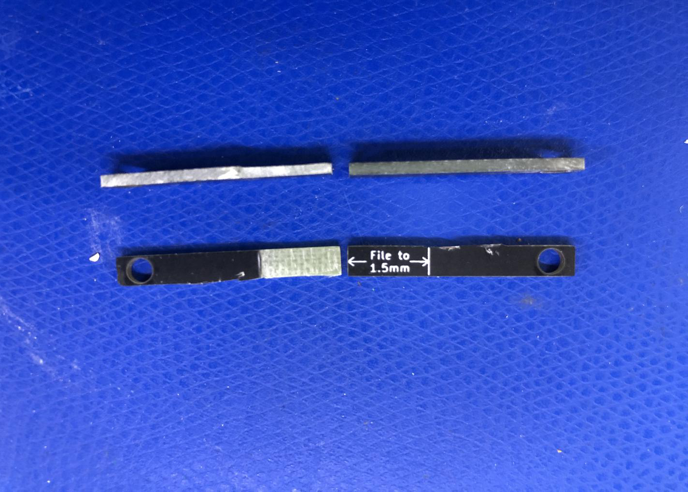
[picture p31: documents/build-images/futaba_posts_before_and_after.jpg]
Posts before and after filing
    

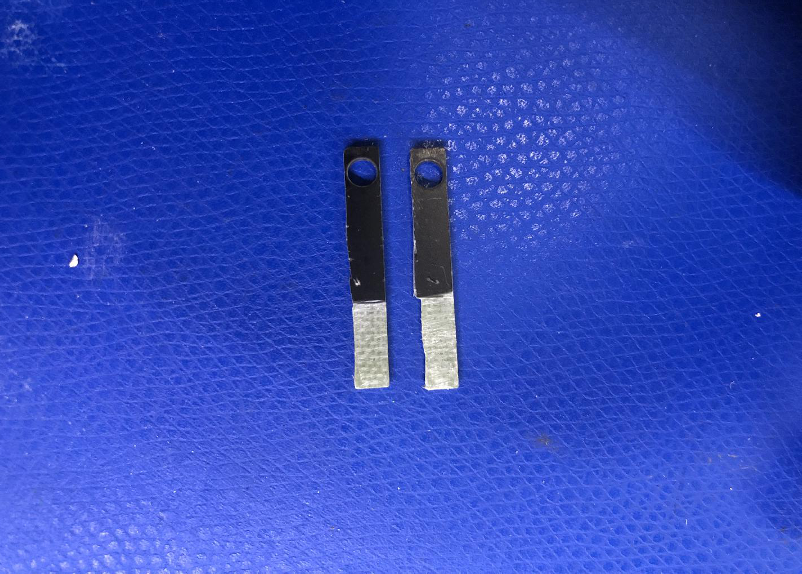
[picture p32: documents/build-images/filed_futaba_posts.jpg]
Posts ready to install
    

1. The posts should be just tight enough to require a pair of pliers to insert.  Use pliers to insert both posts fully.  Use a ruler or caliper to ensure the prodruding portions of both posts are the same length.

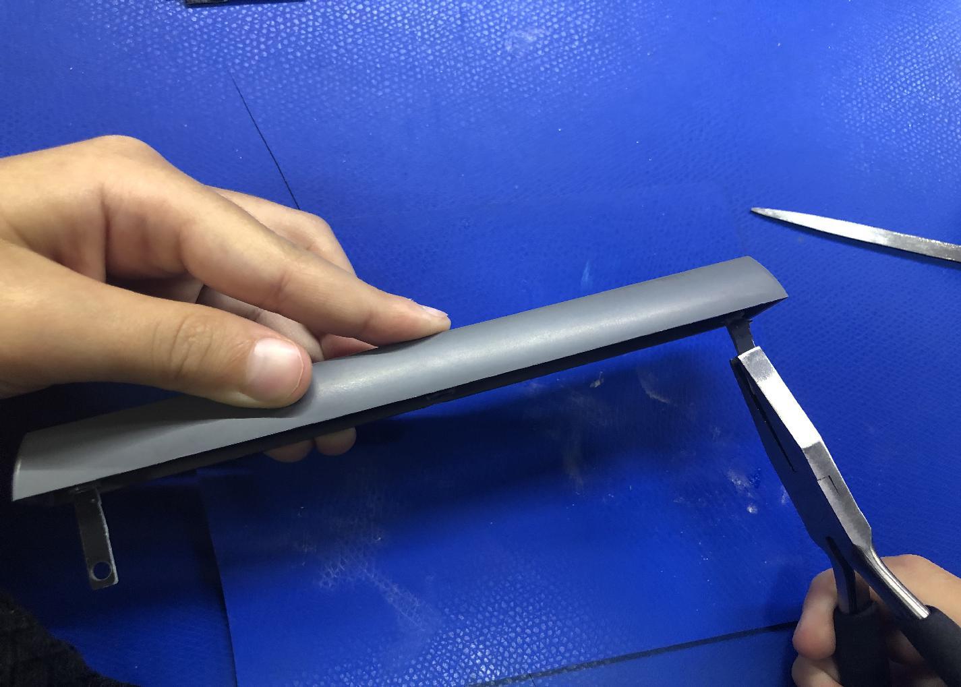
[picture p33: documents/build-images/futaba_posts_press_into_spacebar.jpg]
Press the posts into the spacebar


1. Install the spacebar center mount on the spacebar key, aligning the posts so that they slide into the PCB-mounted stabilizers.

1. Holding down the spacebar, align the arms stabilizer rod with the holes in the posts, and then snap the rod into place at the front of the stabilizer mounts.

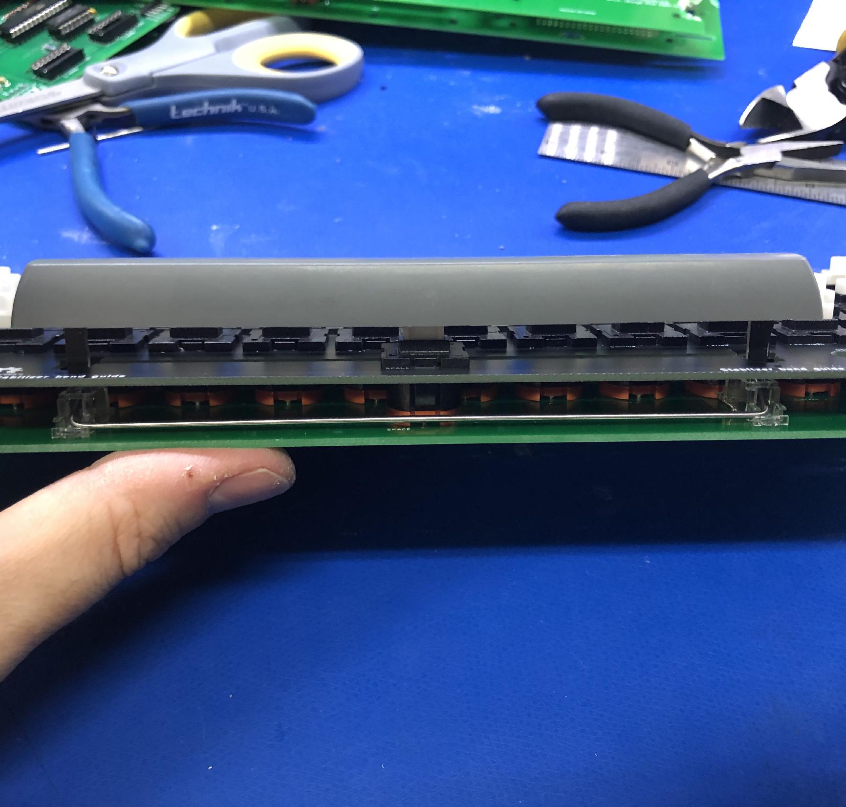
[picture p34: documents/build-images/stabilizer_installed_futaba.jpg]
Stabilizer installed


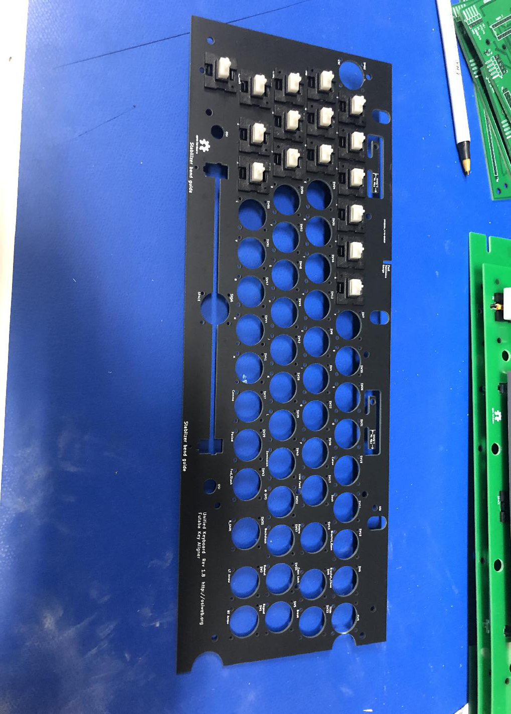
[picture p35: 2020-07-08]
documents/build-images/futaba_aligner.jpg

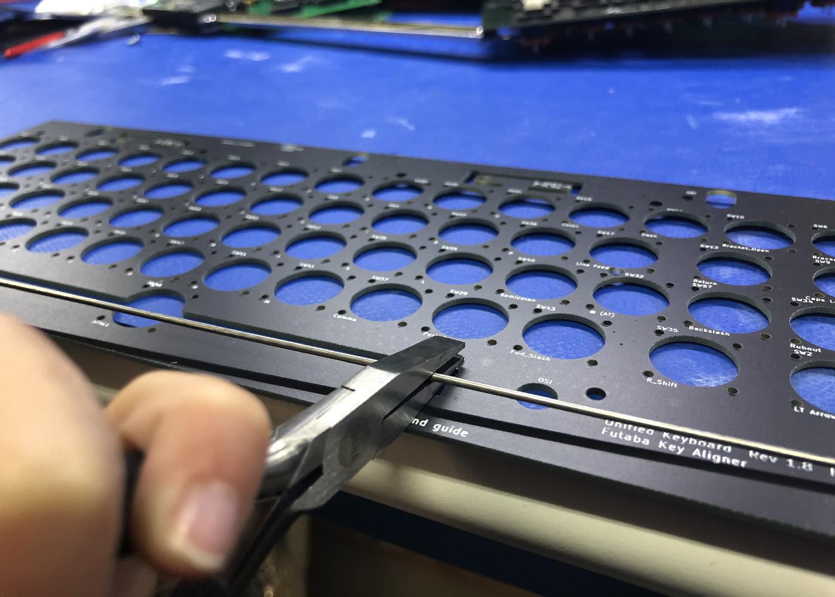
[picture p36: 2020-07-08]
documents/build-images/rod_estimating_second_bend.jpg

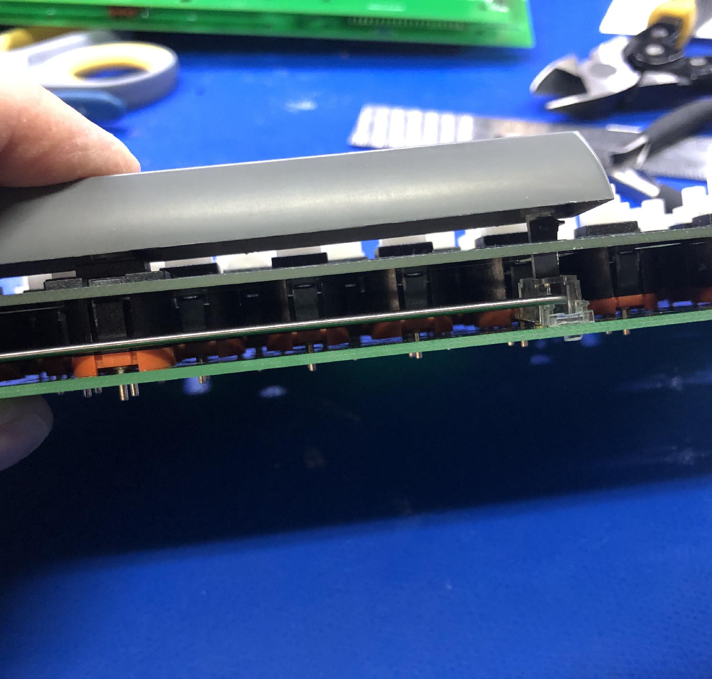
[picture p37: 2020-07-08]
documents/build-images/installing_futaba_spacebar_stabilizer_rod.jpg

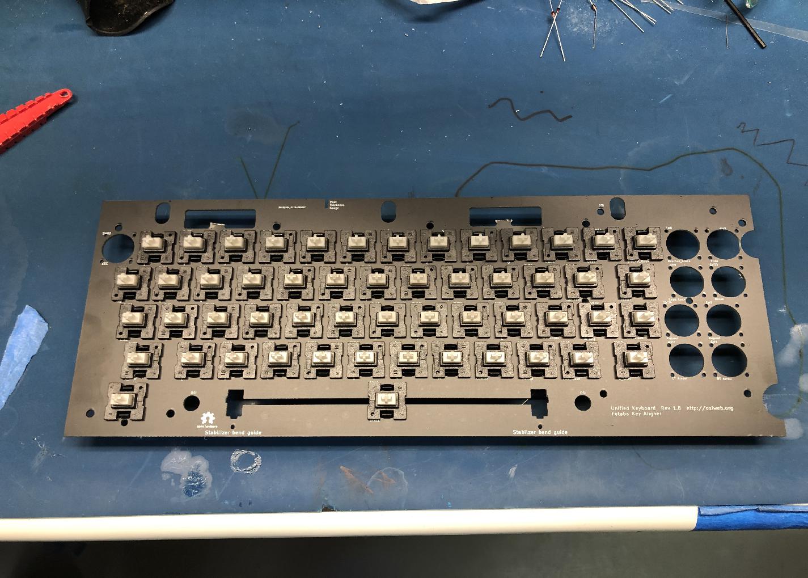
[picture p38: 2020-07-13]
documents/build-images/Install_switches.jpg

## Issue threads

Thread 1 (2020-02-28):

Move DIP switch to row 9

dfnr2, 2020-02-28:
DIP switch on row 15 nearly doubles keyscan times and RAM usage for an 8-row keyboard.  Moving the switch to row 9 will significantly decrease RAM and speed scans, while not interfering with OSI compatibility.

dfnr2, 2020-03-12:
Done for hardware.  Only a single constant needs to be changed in firmware when new hardware is available.

Closed 2020-03-12.

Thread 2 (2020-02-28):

Row number macros in keymap definitions.

dfnr2, 2020-02-28:
Replace hard-coded row numbers in keymaps with row macros, so that keymaps can be specified in a contiguous map of logically ordered rows, without knowing or having to accomodate the position of the DIP switch, or other special rows.

dfnr2, 2020-03-12:
Done

Closed 2020-03-12.

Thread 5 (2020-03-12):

Add protection resistors on the ASCII parallel out port

dfnr2, 2020-03-12:
To reduce risk of damage by backwards hookup, add a 470 ohm resistor on each paralles output line.

dfnr2, 2020-04-06:
Not implemented now due to avoid complexity.  Will revisit for future versions.

Closed 2020-04-06.

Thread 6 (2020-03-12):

move LED current limit resistors to the +5 side of the key matrix LED connections

dfnr2, 2020-03-12:
Moving the LEDs will keep compatibility, while allowing the LED drivers to also drive logic.

dfnr2, 2020-04-06:
Moved resistors to keyboard matrix PCB.  This will allow resistors to be matched to maximum desired LED brightness for a given matrix, and the interface will not affect the maximum brightness.

Closed 2020-04-06.

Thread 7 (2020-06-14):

Ensure MX center post hole has enough tolerance

dfnr2, 2020-06-14:
Some MX clone switches have slightly larger center posts, and tolerance on holes may be variable.  Center post is not critical since aligner lines up the keys.  So allow enough tolerance that the post-hole fit doesn't interfere with ease of building.

dfnr2, 2020-06-17:
Increased hole size to 0.160

dfnr2, 2020-06-17:
Done in Rev 1.7

Closed 2020-06-17.

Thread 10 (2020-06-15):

Add LED at Apple II REPEAT position

dfnr2, 2020-06-15:
to repurpose as CAPS LOCK for upper/lower

dfnr2, 2020-06-16:
also need hole in Futaba aligner

dfnr2, 2020-06-17:
Done, Rev 1.7

Closed 2020-06-17.

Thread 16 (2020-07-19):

Repeat key doesn't work the first time it is used.

dfnr2, 2020-07-19:
Pressing repeat and a code key doesn't work the first time repeat is used after switching to a keymap.  After repeat key is released, subesquent behavior seems correct.

dfnr2, 2020-07-20:
Fixed.  Repeat_init() needs to be called when selecting a new keymap.

Closed 2020-07-20.

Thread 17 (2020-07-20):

Cherry in-button LED pads are too close to Futaba pad and (rarely) short

dfnr2, 2020-07-20:
Options:
1) Specify testing for a short by manufacturer (as long as manufacturer design rules are met)
2) remove in-button LED from cherry, and mount LED in front of switch like the futaba.
3) slightly move the LED and switch pads to increase spacing.

dfnr2, 2020-08-06:
Done.  Moved futaba pads up 0.002" and cherry pads down 0.001" to open up clearance.

Closed 2020-08-06.

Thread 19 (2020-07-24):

Improve stabilizer design

dfnr2, 2020-07-24:
1. To reduce spacebar wobble, create slots under each stabilizer post, for the post to extend from the mount through the keyboard PCB

2. Modify stabilizer post design to optimize hole size to minimize the amount of travel before the rod ends engage.

3. Add holes at two heights, for cherry and Futaba keys.

4. For hobby builds, provide posts on the futaba and cherry aligners.  But for mass production, find a rigid 1.5mm material suitable for laser cutting, or create a jig to easily sand the posts to the right thickness.

dfnr2, 2020-08-06:
Done.  Only needed for futaba.  Extend posts through PCB.

Closed 2020-08-06.

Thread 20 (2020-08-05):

In virtual devices, apply function synchronously to all physical outputs

dfnr2, 2020-08-05:
Currently cycles over physical outputs attached to a virtual output, applying the complete selected function to each physical output in sequence.  For example, a toggle function will toggle each of the attached physical outputs in sequence.

Instead, apply each phase of the selected function to each physical output, then move to the next phase of the function.  This way, the physical outputs are all synchronized.

dfnr2, 2020-08-06:
Done

Closed 2020-08-06.

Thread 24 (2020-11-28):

Allow keymaps to assign functions to keymap codes

dfnr2, 2020-11-28:
In the current implementation, each key code is hard-mapped to a function call or a value.

Consider an alternate approach (which eats more RAM) of maintaining a table of function calls.

Considerations:
1) might save RAM by using a hybrid approach.  Self-insert values below the "action threshold", and look up function calls for values above the threshold.

2) need separate function tables for press and release.

dfnr2, 2021-01-29:
Uses more space, but cleans up function-specific code in dispatch routines.

dfnr2, 2021-03-01:
Explicit assignment of separate functions for press and release in the keymap has some problems:
- generates clutter in the keymap definitions
- error prone
- takes up much more space than keycodes

dfnr2, 2021-03-01:
This functionality will be addressed with issue #26

Closed 2021-03-01.

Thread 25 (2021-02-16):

Each keymap registers an initialize function

dfnr2, 2021-02-16:
In order to change from setting up each keymap behavior with a C function, rather than a complex data sructure, each keymap shall register a single keymap initialization function with the keymap module.  After that, the keymap can register any other function hooks, virtual devices, key mappings, etc. in the supplied keymap-specific initializer function.

Related to Issue #23

dfnr2, 2021-02-20:
Implemented.

Closed 2021-02-20.

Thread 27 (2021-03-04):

Overhaul build process

dfnr2, 2021-03-04:
Current Makefiles are haphazard and don't properly handle dependencies.

Use CMake to clean up the build process
Clean up the test and app build processes
Have build infrastructure in place to simplify configuration of keymaps with the new keymap definition scheme

dfnr2, 2021-03-05:
Closed with commit 7c5a201

dfnr2, 2021-03-05:
Re-open for newmaps branch.

dfnr2, 2021-03-05:
Reopen issue for newmaps branch

dfnr2, 2021-11-30:
Done.  Newmaps merged into master

Closed 2021-11-30.

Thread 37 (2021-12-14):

Knight and SAIL keyboards

larsbrinkhoff, 2021-12-14:
Hello,

Would it be possible to adapt this to make Knight and SAIL keyboards?

larsbrinkhoff, 2021-12-14:
The Knight keyboard was used with the MIT AI lab PDP-10 running ITS, and later also for the first Lisp machines before Kulp designed the infamous space-cadet keyboard.

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

larsbrinkhoff, 2021-12-14:
The SAIL keyboard was designed by Les Earnest for use with the Stanford AI Lab PDP-10.  It predates the Knight keyboard and has pretty much the same features.

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

dfnr2, 2021-12-14:
Yes, it would be possible to add these keyboards. If you are interested in seeing these keyboards replicated in the future, please provide information on the physical interface as well as the data protocol.  It wouldn't hurt if someone contributed a PCB layout compatible with the 40-pin encoder interface.  The classic layout could serve as a starting point.

The keycaps could be made, but the custom symbols might be a substantial up front charge from most manufacturers.  Resin-printing the 3D keycaps may be reasonable, though.

larsbrinkhoff, 2021-12-15:
Thank you.

I think the physical interface or protocol would not be useful since the computers on the other end are long gone, and now only exists as emulators.  So an USB or PS/2 interface would make more sense.

In what ballpark would the cost of the custom keycaps be?  I imagine it could be amortized over a small but dedicated community of PDP-10 enthusiasts.

dfnr2, 2021-12-15:
All this is doable.  PS/2 emulation  would be straightforward to add, and I believe a soft USB/HID emulation could be done, or an arch-* module could be added for a chip with USB engine and PHY.

I have inquired whether the greek & match symbols are available or if they require a setup fee.  The fee is $50 per new symbol.  It looks like either keyboard would need around 30 new symbols, so $1500, only one time.  An order of 10 keyboards would probably be in the range of $100-$120, so let's say the first order of 10 keyboards would probalby run about $250/set of keys.  Subsequent orders would be in the $100-$120 range.  Bigger orders would be less per set.

Of course, another route would be to create a 3D keycap model, then emboss the legends into the keys in CAD, and 3D print the whole thing on a resin printer using colored resin.  If anyone wants to contribute some keycap models, I would welcome them.

larsbrinkhoff, 2021-12-16:
Pricey, but I think many will think it's worth it.  I'll ask around to gauge the interest.

I don't think I could pull off the 3D print, but I'll keep it in mind and see if someone else can.

larsbrinkhoff, 2021-12-17:
Seems there could be a first batch of 40-50 keyboards, so looks like it's a feasible project.

So next step would be to design the PCBs, correct?  Is there anything else I need to do at this stage, or more information to provide to you?

larsbrinkhoff, 2021-12-17:
For reference, @MMcM's Knight keyboard:
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

larsbrinkhoff, 2021-12-17:
Various photos of the SAIL keyboard can be found here:
https://deskthority.net/wiki/SAIL_keyboard

dfnr2, 2021-12-19:
I think the big variable here is the keycaps.  The next step is to get the keycap order placed.  You should start with the spreadsheet for the classic keycaps, and extend to the Knight or SAIL layout.  My suggestion would be to go with the Knight layout, since it seems closer to the modern layouts.  Either way, I think that should be the first step.

Once an order is placed, there is likely an 18 month lead time (as of Dec. 2021), so there is plenty of time to get the PCB and keymaps ready.  I would start from the classic keyboard layout, and extend to the selected layout.

Finally, the last step is to add the layout to the firmware.

I will be happy to assist with any of those steps.  I would prefer someone take the lead on getting a keycap order together.  I will be happy to review the spreadsheet.  I will also work with any volunteer who wants to make the PCB design.   If we have keycaps and PCBs on order, then I will be happy to work with someone on the keymap, or make the keymap myself.

larsbrinkhoff, 2021-12-20:
I posted a pull request with a spreadsheet here: #38

dfnr2, 2021-12-20:
I've merged the pull request.  It would be a good idea to have a couple of other experts look it over.  I will also look it over myself.   Is there a list somewhere where you will be discussing this project with other PDP-10'ers?  I would like to join, if only to listen in.

larsbrinkhoff, 2021-12-20:
Great, thanks!  When there's time, I'd like to hear your comments expecially about font sizes.  Is there a way to see some kind of sample from the manufacturer?

There is no longer any one definitive place for the PDP-10 community.  For now, the most interest seems to be from the PiDP-10 group: https://groups.google.com/g/pidp-10
and the ITS mailing list: http://its.victor.se/mailman/listinfo/its-hackers_its.victor.se

larsbrinkhoff, 2021-12-21:
This is in stock again!  https://novelkeys.com/products/sa-sail
Maybe it can be of use here.

larsbrinkhoff, 2021-12-21:
Sorry, false alarm.  Almost all options are sold out.

larsbrinkhoff, 2021-12-21:
Some comments from @aap and @ams:

- zero with slash is sort weird, its just a zero
- that one is called circle-cross
- the 0 and Z i suppose you just want to note that they are typeset using a slash, and a line over it ... but sorta confundeling, the way 0 is rendered looks spectacularily weird
- [Might use a Scandinavian Ø instead] or the empty set symbol
- " should be straight

larsbrinkhoff, 2021-12-21:
@dabridgham points out that the spreadsheet specifies row 3 profile for all keys.  It's mostly because I copied another file from here, and I haven't checked what the Knight keyboard looks like.

Another consideration is the awkward placement of the CTRL and META keys.  Should they remain in place, be moved, or both (two different layouts)?

larsbrinkhoff, 2021-12-21:
The available profiles can be found here:
https://pimpmykeyboard.com/key-cap-family-specs/

I can see why the "classic keyboard" in this repository chose SA row 3.  It might also be the closest match for the Knight keyboard.  It could be that once the up front charge has been paid, people can order their own keycap set with any profile.

dfnr2, 2021-12-21:
Row 3 for all keys is intentional.  That way, keys can be reconfigured from one row to another freely.  Moving CTRL and META keys is a prime example.  Some might want the original position, and others might want to modify to place some keys in a more contemporary position.  If the keycaps are all row 3, it's pretty easy to support multiple configurations.

larsbrinkhoff, 2021-12-22:
More feedback from @dabridgham:
- Do we need to consider mount styles?  https://pimpmykeyboard.com/template/images/MountStyles.pdf
- Design the PCB with extra key positions, to be flexible with regards to key placement.

@dfnr2 wrote:
> IMO, the flexibility is worth it

Yes, I can see this is a good idea!   Regarding the profiles, I have asked for photos.  It's not easy because I only know of one person that has a keyboard.
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
dabridgham, 2021-12-24:
Well that's clear enough then.  No sculpturing on the keys.

As for Bluetooth, I see these little Bluetooth modules that look like they should be pretty easy to use.  I've never played with any though so I don't know first-hand.  Probably the hardest part there would be powering it.  The expectation with wireless is that the keyboard would have a battery of some sort so then you need a charging circuit.  Or maybe just use removable AAs or an 18650 and an external charger.  Perhaps just put a Bluetooth module connection on the USB interface board and leave the question of powering the whole thing to the builder or to a future and separate project.

larsbrinkhoff, 2021-12-29:
I'm reaching out to these manufacturers:
- [Signature Plastics](https://pimpmykeyboard.com/)
- [Drop](https://drop.com/)
- [WASD Keyboards](https://www.wasdkeyboards.com/)

larsbrinkhoff, 2021-12-29:
This renders keyboards layouts very nicely: https://kle-render.herokuapp.com/

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

dabridgham, 2021-12-29:
Is the purpose of that keyboard editor only to produce renders or is there also a path to going from the design to a set of keycaps or even an actual keyboard?  I notice you can specify mount and switches which suggest to me something more but I'm not finding it.

larsbrinkhoff, 2021-12-29:
I have used this: http://www.keyboard-layout-editor.com/  From which I got the pictures at the top of this issue.

It stores its data as a GitHub gist in JSON format.  Besides "kle-render" mentioned above, rumor has it there's some number of tools that can use the data.  Such as making PCB layouts, but I haven't investigated this.

larsbrinkhoff, 2021-12-29:
Here is a list of "KLE" tools: https://www.keyboard-design.com/tools.html

larsbrinkhoff, 2021-12-30:
The text font seems to be the same as other similar vintage Micro Switch keyboards.  Many samples can be found online.  For example:
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

larsbrinkhoff, 2021-12-30:
The Blender plugin works fine: https://github.com/Kirpal/Keyboard-Layout-Editor-for-Blender

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

larsbrinkhoff, 2021-12-31:
Comparing the SAIL and Knight keycap sets.  They share 21 keycaps if we disregard color differences.

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

larsbrinkhoff, 2021-12-31:
@dfnr2, is this an option?

https://www.reddit.com/r/cableporn/comments/atfbg4/this_is_what_a_mechanical_keyboard_without_a_pcb/

larsbrinkhoff, 2021-12-31:
Tom Knight informs us on Twitter that the awkward positions of KEYS and CTRL were due to a mistake.

dabridgham, 2022-01-01:
Interesting history from TK.  He also suggested moving the parens to lower-case like they are on both the SAIL and Space Cadet keyboards.  I'm good with either/both modifications but also realize that once we start changing things, we run the risk of a protracted "discussion" while we figure it out.  There's always the tension of how much to recreate exactly and how much to improve.  I figured the idea of just putting pads on the keyboard PCB for another key inboard of the two CTRL keys was a pretty reasonable compromise, allowing the builder to do it either way (or even populating all of the positions and adding HYPER or SUPER).

Speaking of Space Cadet keyboards, I noticed you commented on Twitter that you get a lot of requests for those.  I bet printing on the front of the keycaps would be an issue and probably expensive.  I'd put my hand up for those too, if possible/practical.

dabridgham, 2022-01-01:
Two comments about the keyboard circuit board.  First, the USB and PS/2 protocols as well as dfnr2's 40-pin connector all support LEDs (at least three) so I'd suggest, if there's room, that you put three LED positions on the PCB.  These original keyboards didn't have LEDs of course but it'd be trivial to just leave them off when building the board if you didn't want them.

Second, regarding that 40-pin connector, I see that the other keyboards defined here put that connector near the front (closest to the typist).  I suspect that worked well for the SOL enclosure it was aimed at but would suggest that for these standalone keyboards it be moved to the back.  Since the interface circuit board will presumably be sandwiched there, it makes sense to keep the front as thin as possible, adding thickness to the back where you might want the keyboard sloped a bit anyway.

dfnr2, 2022-01-01:
I think this issue is getting a bit far afield.  May I suggest opening up a thread on vcfed.org to discuss various aspects of the Knight/SAIL keyboards?

larsbrinkhoff, 2022-01-02:
Sure!  I opened up this thread:

https://forum.vcfed.org/index.php?threads/remaking-knight-and-sail-keyboards.1237093/

ams, 2024-09-11:
PCB for Space Cadet: https://github.com/rljacobson/SpaceCadet

One with Cherry MX switches: https://github.com/rigidus/SpaceCadet/tree/ModernCherryMx

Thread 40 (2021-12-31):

Apple II: Spacebar return force and Reset key force to activate

Quantamm, 2021-12-31:
I'm assembling the Apple II version of the keyboard and I'm using Gateron red keyswitches (MX clones with a 45 cN activation force). I'm finding that the spacebar doesn't return all the way to the top of its travel on its own and it feels very mushy. Meanwhile, the reset key is as-easy as any other key to press (and therefore easy to accidentally activate).

The original Apple II keyboard solved both issues by having springs under those two keys.

I don't see anything in the Apple II build instructions about springs or increasing the force for these two keys. Am I missing something?

I'm thinking about putting Gateron blacks (60 cN) or greens (80 cN) under those keys. Is there a better way to increase the force needed?

dfnr2, 2021-12-31:
This isn't really an issue, so I will be closing it.  However, I do have the following comments:

1) This project doesn't specify what keys you use.  You can use futaba MD4-PCS, or any flavor of Cherry MX or its clones.

2) If you are having trouble with the spacebar, most likely it is an issue with the stabilizers.  The stabilizers should work with any flavor of keys.  I have tested them with Cherry MX red, and the spacebar feels the same as other keys and returns properly.

3) The Apple II keymaps use CTRL-RESET for the RESET function, and SHIFT-RESET for the CLEAR_SCREEN function (for Apple I interfaces).  Simply hitting RESET will do nothing, so no extra spring needed.  That said, you can modify the keymap to perform a RESET on an unmodified RESET press if you want.  You can also choose whatever switch you want for the RESET key, or add a spring if you like.  Springs are available from multiple vendors.  That's up to you.

4) I tend to prefer Cherry MX/Gateron Black over the other Cherry MX variants.  Black has a little more force and feels closer to vintage keyboards.  Blue is not bad, but I'm not a huge fan of clicky.  I think that Red is more for gaming.

5) For posts discussing keyboard builds, questions, problems that aren't an issue with one or more of the objects in this repository or wiki, consider opening a thread on the vcfed.org or applefritter forums.  I will consider opening up a unified keyboard project forum for general discussions.

Quantamm, 2022-01-01:
I think you misunderstood my intent. I opened this issue because I'm following the instructions on the wiki to the letter and the end result isn't working, which means that there's a documentation gap and I was hoping that we could identify what it was so we could fix it. Closing my issue without doing anything to resolve it isn't going to help the next person.

dfnr2, 2022-05-26:
@Quantamm I see what you are saying.  The RESET key not being stiff really won't be much of an issue due to the two-key combo, but some folks might want the original behavior, and if that is added as a keymap, then the spring would be helpful.  Also, while I haven't seen an issue with the spacebar, the red keys are lower force, so I could see this becoming an issue.

If you have tried out any springs and can recommend some, I will try out the proposed solution, and add it in to the BOM and instructions.

Quantamm, 2022-05-29:
@dfnr2, thanks for getting back to me. Here's what I ended up doing:

For everything except the reset and spacebar keys, I used Gateron Red switches.

For the reset key, I went with a Gateron Green switch. The heavier activation force and the audible click gave me the behavior and feel that I was looking for.

For the spacebar, the pre-bent stabilizer rod that I received was ever-so-slightly too short to the point where it slightly rubbed up against the sides of the plastic stabilizer guides. It wasn't noticeable when operated by hand, but was a problem once the whole board was assembled. If anything, I think that if https://github.com/osiweb/unified_retro_keyboard/wiki/apple-ii-notes , under step 2 of Prepare the keyboard PCB, had me friction fit the key switch and install the spacebar keycap, I probably could have caught it in time. As it was, I didn't find out until after all of the key switches were soldered in place.

I ended up buying a pack of 1/16" x 12" brass rods (https://www.amazon.com/gp/product/B009YO48LK), 3D printing a jig, and bending a new stabilizer rod. I then applied switch lube (https://www.amazon.com/gp/product/B096MHPHBM) to the plastic stabilizer guides. I used a Gateron Black switch and in the final assembly, I added two 9/32" x 1/2" compression springs (https://www.amazon.com/gp/product/B079P5P9LL) over each of the key switch posts. This got me to about 90% of the feel that I was looking for.

Like I mentioned above, I don't think all of this would have been necessary had I thought to check the spacebar behavior with both the key switch and key cap in place before soldering. I could have probably made some minor tweaks at that point, but once it was assembled, my options got limited.

dfnr2, 2022-05-30:
@Quantamm Good detail.  I will add a step to check the stabilizer fit early in the assembly as you suggest.

Perhaps it will be good to add a section about tuning the spacebar.

I'm curious if you checked to see if the metal stabilizer bar was also a little tight on the aligner plate, or if it fit properly.  The stabilizer can also be checked using the mounting posts between the "X" and "." keys.

Are you willing to share your 3D model for the bending jig?  I have a jig made from a couple of wire-bending tools mounted to a piece of plywood, but it's a bit on the expensive side, and tricky to assemble perfectly.  A 3D-printed jig would be more reproducible and accessible.

Did you use the compression springs for all keys, or just the keyboard?  For the keyboard, did you use just one spring fot the key switch, or three--one on the switch and two on the stabilizers?

Quantamm, 2022-06-05:
> I'm curious if you checked to see if the metal stabilizer bar was also a little tight on the aligner plate, or if it fit properly. The stabilizer can also be checked using the mounting posts between the "X" and "." keys.

I did check it, but I don't remember what the result was. If it was way off, I would have stopped, but the bar was only a little short. I can't remember if I noticed if it fit well, or barely fit.

> Are you willing to share your 3D model for the bending jig? I have a jig made from a couple of wire-bending tools mounted to a piece of plywood, but it's a bit on the expensive side, and tricky to assemble perfectly. A 3D-printed jig would be more reproducible and accessible.

I checked my files and I no longer have it. It wasn't anything complicated. It was just a box with a height of whatever the lengths of the arms of the bar needed to be (~8mm) with two holes separated by whatever the length of the bar is (~120mm). I do recall having to print it a couple of times to get the finer measurements just right.

> Did you use the compression springs for all keys, or just the keyboard? For the keyboard, did you use just one spring fot the key switch, or three--one on the switch and two on the stabilizers?

I used springs only over the two stabilizer posts of the spacebar. The keyswitch does not have a spring.

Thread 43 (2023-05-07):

Update Franklin keyboard to use project conventions

dfnr2, 2023-05-07:
The Franklin keyboard needs to be updated to apply the conventions of the unified retro keyboard project.

This includes:

1) Using the dual footprints for futaba / cherry keys
2) include a diode for every key.
3) Add stabilizers to the spacebar
4) The Franklin keyboard is 9u, but it's very hard to find a 9u option.  Instead, use 8u+1u
5) Add cherry and futaba aligner plates

I've started a branch for the Franklin Ace keyboard.   tasks 1 and 3 are done.  Task 2 is done in the schematic, but still WIP in the PCB.

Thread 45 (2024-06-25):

Use IIe Keyboards on Apple II Plus

dkgeorge, 2024-06-25:
Can this project enable the use of Apple IIe Keyboards on the Apple II Plus?

According to the [Apple IIe keyboard pinout documentation](https://github.com/user-attachments/files/15962987/Apple.IIe.keyboard.pinout.txt):
 `4) Unlike the ][ & ][+, the //e keyboard is completely passive with the decoder chip located on the motherboard.`

II've come across references to other projects, such as the [apple-iie-keyboard-ii-encoder-card](https://www.applefritter.com/content/apple-iie-keyboard-ii-encoder-card), which reportedly achieved this compatibility. Unfortunately, detailed information about this project and its author is no longer available.

dfnr2, 2025-01-21:
Yes, that sort of thing is exactly what this project is intended for.

I'd use the one of the ATMega2560-based encoder boards.  I'd dedicate one row for the SHIFT, CTRL,, and CAPSLOCK keys and enable the weak pullup on the corresponding I/O pins.    That would allow the regular matrix read routine to be used.  The RESET line could get the same treatment, or could be routed directly to the /RESET line.  I prefer the first option, which could allow more control over how a RESET is generated.  If you are willing to eliminate the DIP switches from the encoder, you can also map the OA and CA keys the same way.

Then you'd need to modify one of the keymaps for the Apple 2e matrix.

All of that is straightforward.  If anyone wants for volunteer to try this, I'm happy to provide guidance.

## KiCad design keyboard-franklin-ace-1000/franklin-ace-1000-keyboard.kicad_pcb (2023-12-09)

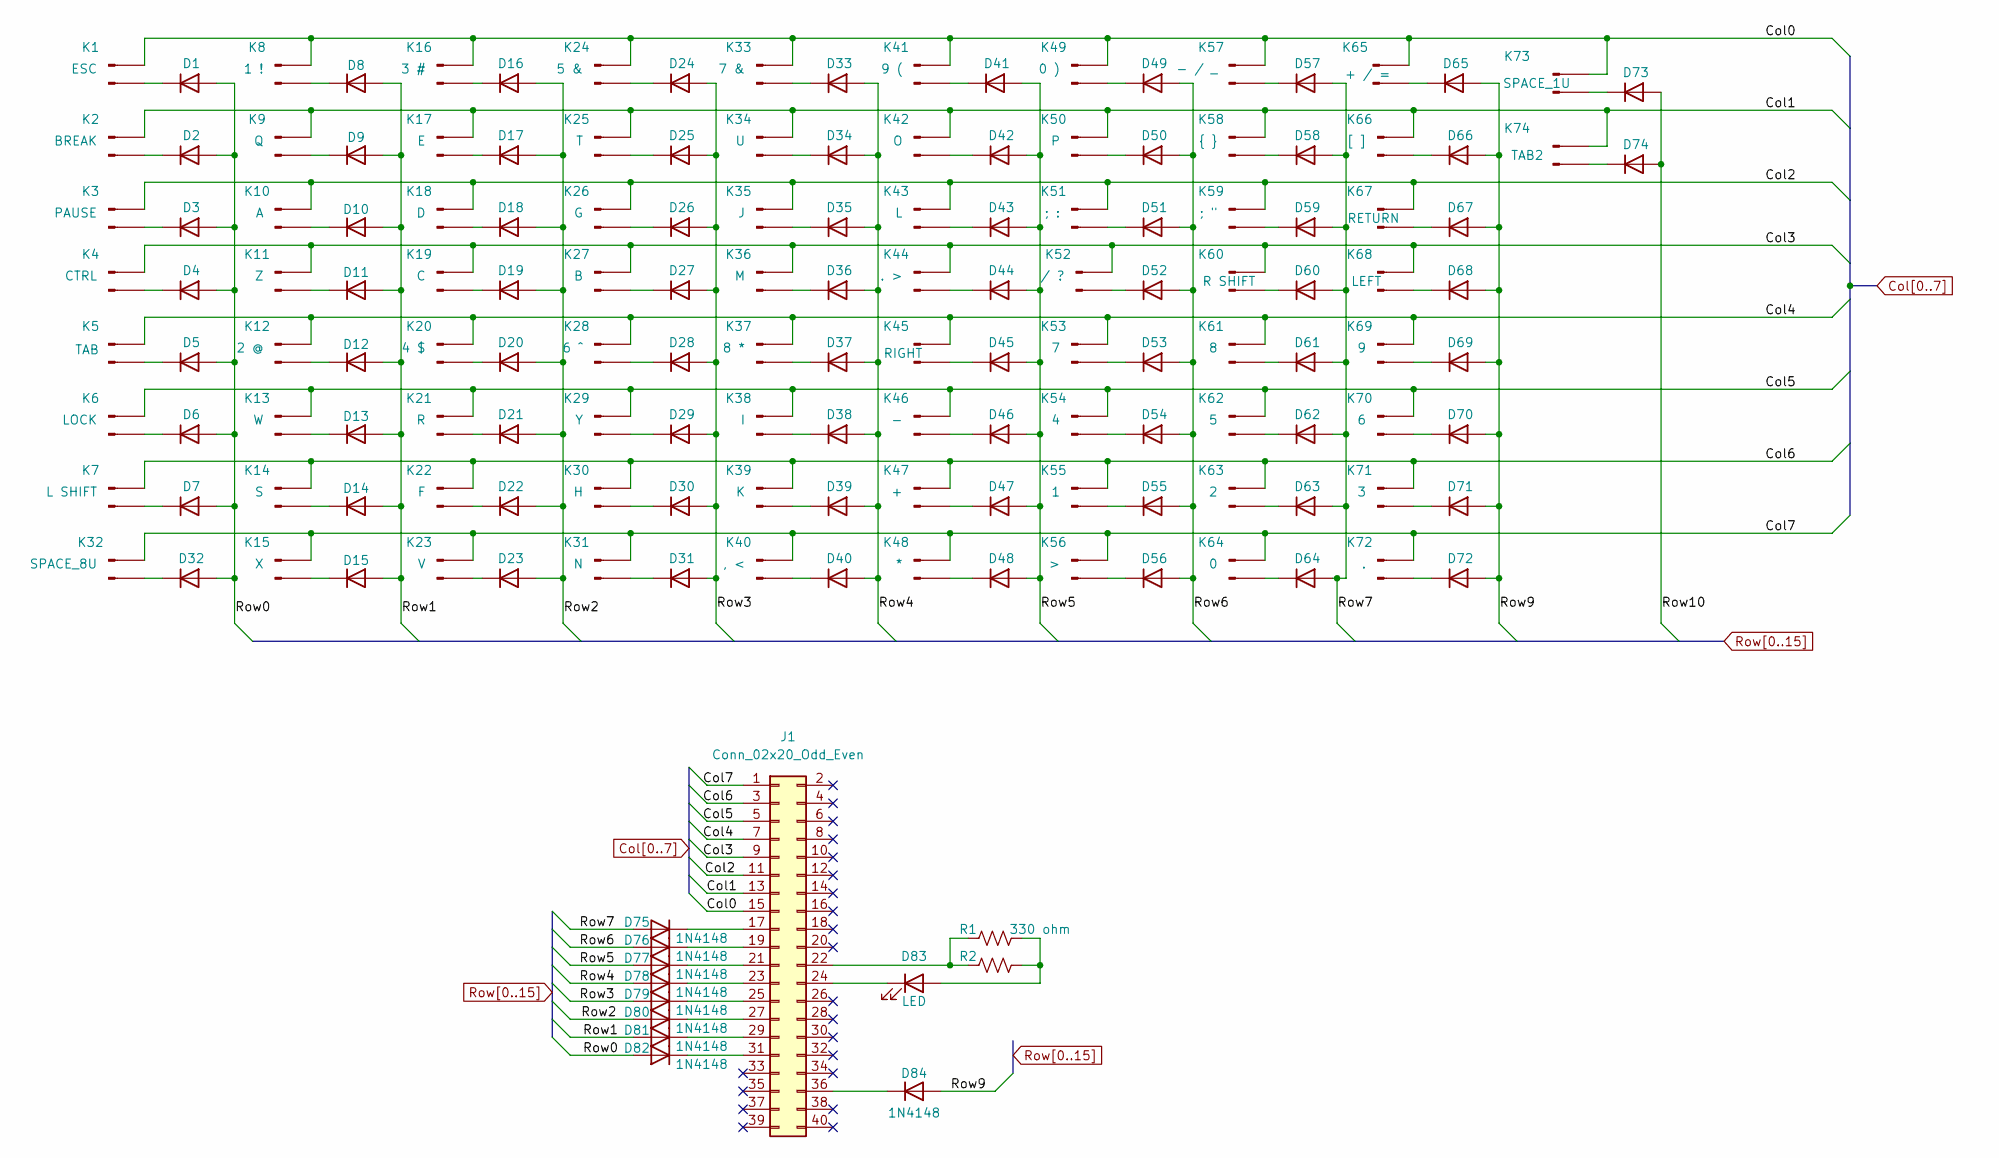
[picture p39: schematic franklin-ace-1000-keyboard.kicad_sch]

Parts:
D1, D2, D3, D4, D5, D6, D7, D8, D9, D10, D11, D12, D13, D14, D15, D16, D17, D18, D19, D20, D21, D22, D23, D24, D25, D26, D27, D28, D29, D30, D31, D32, D33, D34, D35, D36, D37, D38, D39, D40, D41, D42, D43, D44, D45, D46, D47, D48, D49, D50, D51, D52, D53, D54, D55, D56, D57, D58, D59, D60, D61, D62, D63, D64, D65, D66, D67, D68, D69, D70, D71, D72, D73, D74: diode-combined
D75, D76, D77, D78, D79, D80, D81, D82, D84: 1N4148; diode-combined
D83: LED; LED_D3.0mm
J1: Conn_02x20_Odd_Even; PinHeader_2x20_P2.54mm_Vertical
K1: ESC; Key_MX; Tolerance If applicable; Power Rating 10 mA; Manufacturer PN MX1A-11NN
K2: BREAK; Key_MX; Tolerance If applicable; Power Rating 10 mA; Manufacturer PN MX1A-11NN
K3: PAUSE; Key_MX; Tolerance If applicable; Power Rating 10 mA; Manufacturer PN MX1A-11NN
K4: CTRL; Key_MX; Tolerance If applicable; Power Rating 10 mA; Manufacturer PN MX1A-11NN
K5: TAB; Key_MX; Tolerance If applicable; Power Rating 10 mA; Manufacturer PN MX1A-11NN
K6: LOCK; Key_MX; Tolerance If applicable; Power Rating 10 mA; Manufacturer PN MX1A-11NN
K7: L SHIFT; Key_MX_2u; Tolerance If applicable; Power Rating 10 mA; Manufacturer PN MX1A-11NN
K8: 1 !; Key_MX; Tolerance If applicable; Power Rating 10 mA; Manufacturer PN MX1A-11NN
K9: Q; Key_MX; Tolerance If applicable; Power Rating 10 mA; Manufacturer PN MX1A-11NN
K10: A; Key_MX; Tolerance If applicable; Power Rating 10 mA; Manufacturer PN MX1A-11NN
K11: Z; Key_MX; Tolerance If applicable; Power Rating 10 mA; Manufacturer PN MX1A-11NN
K12: 2 @; Key_MX; Tolerance If applicable; Power Rating 10 mA; Manufacturer PN MX1A-11NN
K13: W; Key_MX; Tolerance If applicable; Power Rating 10 mA; Manufacturer PN MX1A-11NN
K14: S; Key_MX; Tolerance If applicable; Power Rating 10 mA; Manufacturer PN MX1A-11NN
K15: X; Key_MX; Tolerance If applicable; Power Rating 10 mA; Manufacturer PN MX1A-11NN
K16: 3 #; Key_MX; Tolerance If applicable; Power Rating 10 mA; Manufacturer PN MX1A-11NN
K17: E; Key_MX; Tolerance If applicable; Power Rating 10 mA; Manufacturer PN MX1A-11NN
K18: D; Key_MX; Tolerance If applicable; Power Rating 10 mA; Manufacturer PN MX1A-11NN
K19: C; Key_MX; Tolerance If applicable; Power Rating 10 mA; Manufacturer PN MX1A-11NN
K20: 4 $; Key_MX; Tolerance If applicable; Power Rating 10 mA; Manufacturer PN MX1A-11NN
K21: R; Key_MX; Tolerance If applicable; Power Rating 10 mA; Manufacturer PN MX1A-11NN
K22: F; Key_MX; Tolerance If applicable; Power Rating 10 mA; Manufacturer PN MX1A-11NN
K23: V; Key_MX; Tolerance If applicable; Power Rating 10 mA; Manufacturer PN MX1A-11NN
K24: 5 &; Key_MX; Tolerance If applicable; Power Rating 10 mA; Manufacturer PN MX1A-11NN
K25: T; Key_MX; Tolerance If applicable; Power Rating 10 mA; Manufacturer PN MX1A-11NN
K26: G; Key_MX; Tolerance If applicable; Power Rating 10 mA; Manufacturer PN MX1A-11NN
K27: B; Key_MX; Tolerance If applicable; Power Rating 10 mA; Manufacturer PN MX1A-11NN
K28: 6 ^; Key_MX; Tolerance If applicable; Power Rating 10 mA; Manufacturer PN MX1A-11NN
K29: Y; Key_MX; Tolerance If applicable; Power Rating 10 mA; Manufacturer PN MX1A-11NN
K30: H; Key_MX; Tolerance If applicable; Power Rating 10 mA; Manufacturer PN MX1A-11NN
K31: N; Key_MX; Tolerance If applicable; Power Rating 10 mA; Manufacturer PN MX1A-11NN
K32: SPACE_8U; Key_MX_Spacebar_5.25; Tolerance If applicable; Power Rating 10 mA; Manufacturer PN MX1A-11NN
K33: 7 &; Key_MX; Tolerance If applicable; Power Rating 10 mA; Manufacturer PN MX1A-11NN
K34: U; Key_MX; Tolerance If applicable; Power Rating 10 mA; Manufacturer PN MX1A-11NN
K35: J; Key_MX; Tolerance If applicable; Power Rating 10 mA; Manufacturer PN MX1A-11NN
K36: M; Key_MX; Tolerance If applicable; Power Rating 10 mA; Manufacturer PN MX1A-11NN
K37: 8 *; Key_MX; Tolerance If applicable; Power Rating 10 mA; Manufacturer PN MX1A-11NN
K38: I; Key_MX; Tolerance If applicable; Power Rating 10 mA; Manufacturer PN MX1A-11NN
K39: K; Key_MX; Tolerance If applicable; Power Rating 10 mA; Manufacturer PN MX1A-11NN
K40: , <; Key_MX; Tolerance If applicable; Power Rating 10 mA; Manufacturer PN MX1A-11NN
K41: 9 (; Key_MX; Tolerance If applicable; Power Rating 10 mA; Manufacturer PN MX1A-11NN
K42: O; Key_MX; Tolerance If applicable; Power Rating 10 mA; Manufacturer PN MX1A-11NN
K43: L; Key_MX; Tolerance If applicable; Power Rating 10 mA; Manufacturer PN MX1A-11NN
K44: . >; Key_MX; Tolerance If applicable; Power Rating 10 mA; Manufacturer PN MX1A-11NN
K45: RIGHT; Key_MX; Tolerance If applicable; Power Rating 10 mA; Manufacturer PN MX1A-11NN
K46: -; Key_MX; Tolerance If applicable; Power Rating 10 mA; Manufacturer PN MX1A-11NN
K47: +; Key_MX; Tolerance If applicable; Power Rating 10 mA; Manufacturer PN MX1A-11NN
K48: *; Key_MX; Tolerance If applicable; Power Rating 10 mA; Manufacturer PN MX1A-11NN
K49: 0 ); Key_MX; Tolerance If applicable; Power Rating 10 mA; Manufacturer PN MX1A-11NN
K50: P; Key_MX; Tolerance If applicable; Power Rating 10 mA; Manufacturer PN MX1A-11NN
K51: ; :; Key_MX; Tolerance If applicable; Power Rating 10 mA; Manufacturer PN MX1A-11NN
K52: / ?; Key_MX; Tolerance If applicable; Power Rating 10 mA; Manufacturer PN MX1A-11NN
K53: 7; Key_MX; Tolerance If applicable; Power Rating 10 mA; Manufacturer PN MX1A-11NN
K54: 4; Key_MX; Tolerance If applicable; Power Rating 10 mA; Manufacturer PN MX1A-11NN
K55: 1; Key_MX; Tolerance If applicable; Power Rating 10 mA; Manufacturer PN MX1A-11NN
K56: >; Key_MX; Tolerance If applicable; Power Rating 10 mA; Manufacturer PN MX1A-11NN
K57: - / _; Key_MX; Tolerance If applicable; Power Rating 10 mA; Manufacturer PN MX1A-11NN
K58: { }; Key_MX; Tolerance If applicable; Power Rating 10 mA; Manufacturer PN MX1A-11NN
K59: ; "; Key_MX; Tolerance If applicable; Power Rating 10 mA; Manufacturer PN MX1A-11NN
K60: R SHIFT; Key_MX_2u; Tolerance If applicable; Power Rating 10 mA; Manufacturer PN MX1A-11NN
K61: 8; Key_MX; Tolerance If applicable; Power Rating 10 mA; Manufacturer PN MX1A-11NN
K62: 5; Key_MX; Tolerance If applicable; Power Rating 10 mA; Manufacturer PN MX1A-11NN
K63: 2; Key_MX; Tolerance If applicable; Power Rating 10 mA; Manufacturer PN MX1A-11NN
K64: 0; Key_MX; Tolerance If applicable; Power Rating 10 mA; Manufacturer PN MX1A-11NN
K65: + / =; Key_MX; Tolerance If applicable; Power Rating 10 mA; Manufacturer PN MX1A-11NN
K66: [ ]; Key_MX; Tolerance If applicable; Power Rating 10 mA; Manufacturer PN MX1A-11NN
K67: RETURN; Key_MX; Tolerance If applicable; Power Rating 10 mA; Manufacturer PN MX1A-11NN
K68: LEFT; Key_MX; Tolerance If applicable; Power Rating 10 mA; Manufacturer PN MX1A-11NN
K69: 9; Key_MX; Tolerance If applicable; Power Rating 10 mA; Manufacturer PN MX1A-11NN
K70: 6; Key_MX; Tolerance If applicable; Power Rating 10 mA; Manufacturer PN MX1A-11NN
K71: 3; Key_MX; Tolerance If applicable; Power Rating 10 mA; Manufacturer PN MX1A-11NN
K72: .; Key_MX; Tolerance If applicable; Power Rating 10 mA; Manufacturer PN MX1A-11NN
K73: SPACE_1U; Key_MX; Tolerance If applicable; Power Rating 10 mA; Manufacturer PN MX1A-11NN
K74: TAB2; Key_MX; Tolerance If applicable; Power Rating 10 mA; Manufacturer PN MX1A-11NN
R1: 330 ohms; R_Axial_DIN0207_L6.3mm_D2.5mm_P7.62mm_Horizontal; Tolerance 1%; Power Rating 1/4 W; Manufacturer PN MFR-25FTE52-330R
R2: RES 330 ohm 1% MLCC 0805 Yageo; R_0805_2012Metric; Tolerance 1%; Power Rating 125 mW; Manufacturer PN RC0805FR-07330RL

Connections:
Col0: J1.15, K1.1, K8.1, K16.1, K24.1, K33.1, K41.1, K49.1, K57.1, K65.1, K73.1
Col1: J1.13, K2.1, K9.1, K17.1, K25.1, K34.1, K42.1, K50.1, K58.1, K66.1, K74.1
Col2: J1.11, K3.1, K10.1, K18.1, K26.1, K35.1, K43.1, K51.1, K59.1, K67.1
Col3: J1.9, K4.1, K11.1, K19.1, K27.1, K36.1, K44.1, K52.1, K60.1, K68.1
Col4: J1.7, K5.1, K12.1, K20.1, K28.1, K37.1, K45.1, K53.1, K61.1, K69.1
Col5: J1.5, K6.1, K13.1, K21.1, K29.1, K38.1, K46.1, K54.1, K62.1, K70.1
Col6: J1.3, K7.1, K14.1, K22.1, K30.1, K39.1, K47.1, K55.1, K63.1, K71.1
Col7: J1.1, K15.1, K23.1, K31.1, K32.1, K40.1, K48.1, K56.1, K64.1, K72.1
unnamed: D1.1 (K), K1.2
unnamed: D2.1 (K), K2.2
unnamed: D3.1 (K), K3.2
unnamed: D4.1 (K), K4.2
unnamed: D5.1 (K), K5.2
unnamed: D6.1 (K), K6.2
unnamed: D7.1 (K), K7.2
unnamed: D8.1 (K), K8.2
unnamed: D9.1 (K), K9.2
unnamed: D10.1 (K), K10.2
unnamed: D11.1 (K), K11.2
unnamed: D12.1 (K), K12.2
unnamed: D13.1 (K), K13.2
unnamed: D14.1 (K), K14.2
unnamed: D15.1 (K), K15.2
unnamed: D16.1 (K), K16.2
unnamed: D17.1 (K), K17.2
unnamed: D18.1 (K), K18.2
unnamed: D19.1 (K), K19.2
unnamed: D20.1 (K), K20.2
unnamed: D21.1 (K), K21.2
unnamed: D22.1 (K), K22.2
unnamed: D23.1 (K), K23.2
unnamed: D24.1 (K), K24.2
unnamed: D25.1 (K), K25.2
unnamed: D26.1 (K), K26.2
unnamed: D27.1 (K), K27.2
unnamed: D28.1 (K), K28.2
unnamed: D29.1 (K), K29.2
unnamed: D30.1 (K), K30.2
unnamed: D31.1 (K), K31.2
unnamed: D32.1 (K), K32.2
unnamed: D33.1 (K), K33.2
unnamed: D34.1 (K), K34.2
unnamed: D35.1 (K), K35.2
unnamed: D36.1 (K), K36.2
unnamed: D37.1 (K), K37.2
unnamed: D38.1 (K), K38.2
unnamed: D39.1 (K), K39.2
unnamed: D40.1 (K), K40.2
unnamed: D41.1 (K), K41.2
unnamed: D42.1 (K), K42.2
unnamed: D43.1 (K), K43.2
unnamed: D44.1 (K), K44.2
unnamed: D45.1 (K), K45.2
unnamed: D46.1 (K), K46.2
unnamed: D47.1 (K), K47.2
unnamed: D48.1 (K), K48.2
unnamed: D49.1 (K), K49.2
unnamed: D50.1 (K), K50.2
unnamed: D51.1 (K), K51.2
unnamed: D52.1 (K), K52.2
unnamed: D53.1 (K), K53.2
unnamed: D54.1 (K), K54.2
unnamed: D55.1 (K), K55.2
unnamed: D56.1 (K), K56.2
unnamed: D57.1 (K), K57.2
unnamed: D58.1 (K), K58.2
unnamed: D59.1 (K), K59.2
unnamed: D60.1 (K), K60.2
unnamed: D61.1 (K), K61.2
unnamed: D62.1 (K), K62.2
unnamed: D63.1 (K), K63.2
unnamed: D64.1 (K), K64.2
unnamed: D65.1 (K), K65.2
unnamed: D66.1 (K), K66.2
unnamed: D67.1 (K), K67.2
unnamed: D68.1 (K), K68.2
unnamed: D69.1 (K), K69.2
unnamed: D70.1 (K), K70.2
unnamed: D71.1 (K), K71.2
unnamed: D72.1 (K), K72.2
unnamed: D73.1 (K), K73.2
unnamed: D74.1 (K), K74.2
unnamed: D75.1 (K), J1.17
unnamed: D76.1 (K), J1.19
unnamed: D77.1 (K), J1.21
unnamed: D78.1 (K), J1.23
unnamed: D79.1 (K), J1.25
unnamed: D80.1 (K), J1.27
unnamed: D81.1 (K), J1.29
unnamed: D82.1 (K), J1.31
unnamed: D83.2 (A), R1.1, R2.1
unnamed: D83.1 (K), J1.24
unnamed: D84.1 (K), J1.36
unnamed: J1.22, R1.2, R2.2
Row0: D1.2 (A), D2.2 (A), D3.2 (A), D4.2 (A), D5.2 (A), D6.2 (A), D7.2 (A), D32.2 (A), D82.2 (A)
Row1: D8.2 (A), D9.2 (A), D10.2 (A), D11.2 (A), D12.2 (A), D13.2 (A), D14.2 (A), D15.2 (A), D81.2 (A)
Row2: D16.2 (A), D17.2 (A), D18.2 (A), D19.2 (A), D20.2 (A), D21.2 (A), D22.2 (A), D23.2 (A), D80.2 (A)
Row3: D24.2 (A), D25.2 (A), D26.2 (A), D27.2 (A), D28.2 (A), D29.2 (A), D30.2 (A), D31.2 (A), D79.2 (A)
Row4: D33.2 (A), D34.2 (A), D35.2 (A), D36.2 (A), D37.2 (A), D38.2 (A), D39.2 (A), D40.2 (A), D78.2 (A)
Row5: D41.2 (A), D42.2 (A), D43.2 (A), D44.2 (A), D45.2 (A), D46.2 (A), D47.2 (A), D48.2 (A), D77.2 (A)
Row6: D49.2 (A), D50.2 (A), D51.2 (A), D52.2 (A), D53.2 (A), D54.2 (A), D55.2 (A), D56.2 (A), D76.2 (A)
Row7: D57.2 (A), D58.2 (A), D59.2 (A), D60.2 (A), D61.2 (A), D62.2 (A), D63.2 (A), D64.2 (A), D75.2 (A)
Row9: D65.2 (A), D66.2 (A), D67.2 (A), D68.2 (A), D69.2 (A), D70.2 (A), D71.2 (A), D72.2 (A), D84.2 (A)
Row10: D73.2 (A), D74.2 (A)

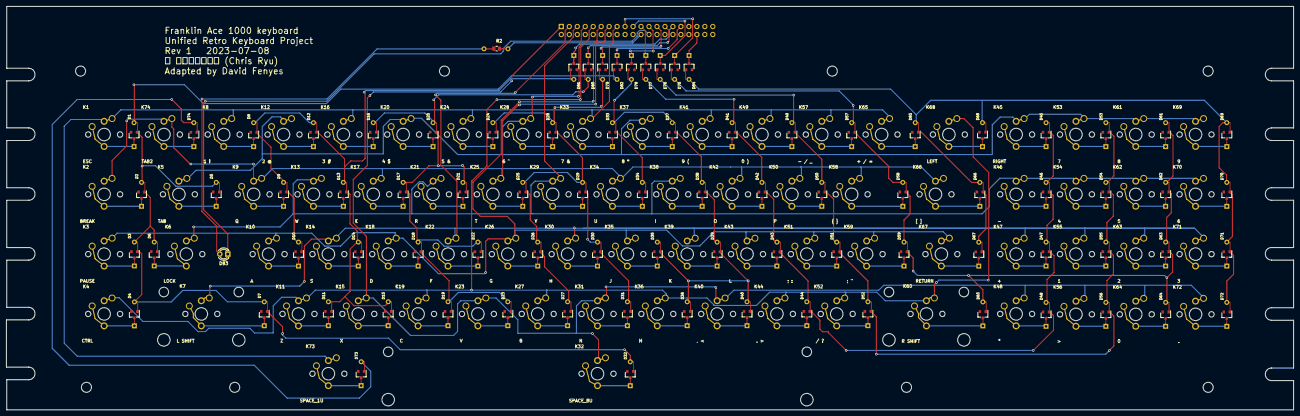
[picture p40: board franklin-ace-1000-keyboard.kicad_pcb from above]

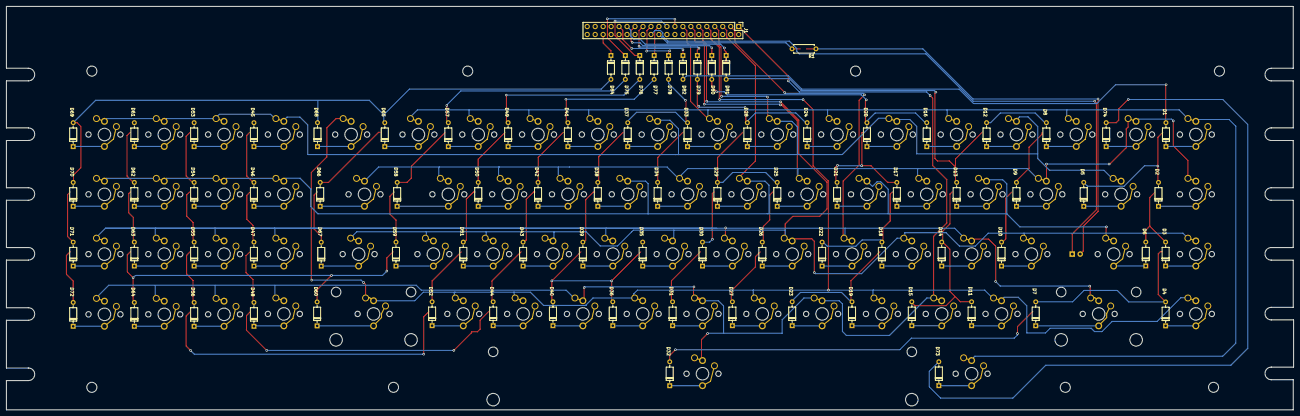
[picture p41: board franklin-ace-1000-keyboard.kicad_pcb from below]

Board: 2 copper layers, 410.0 x 128.5 mm, 161 parts (2 on the bottom side), 104 nets.

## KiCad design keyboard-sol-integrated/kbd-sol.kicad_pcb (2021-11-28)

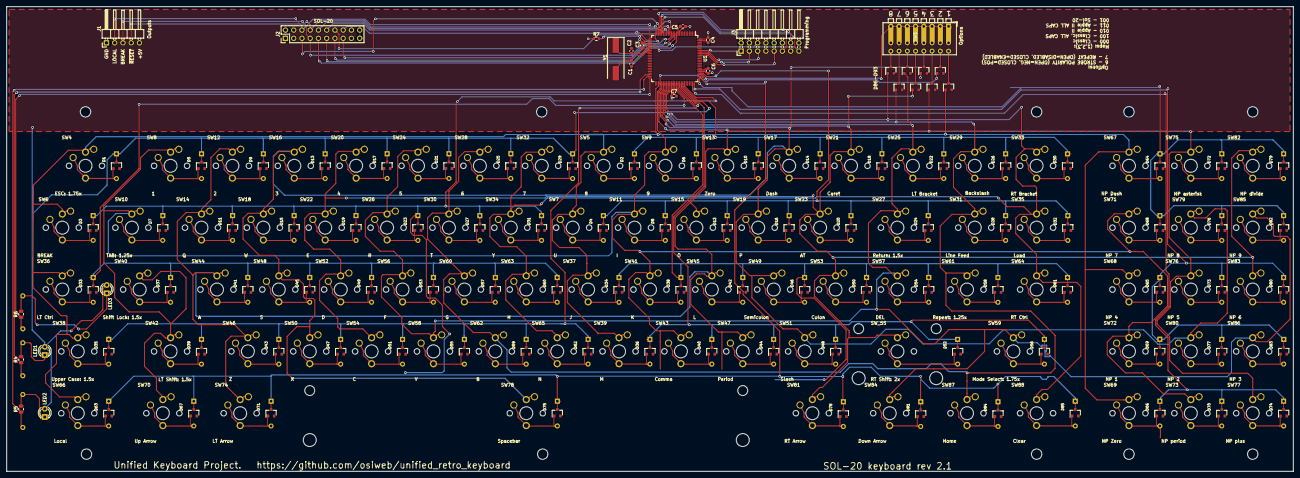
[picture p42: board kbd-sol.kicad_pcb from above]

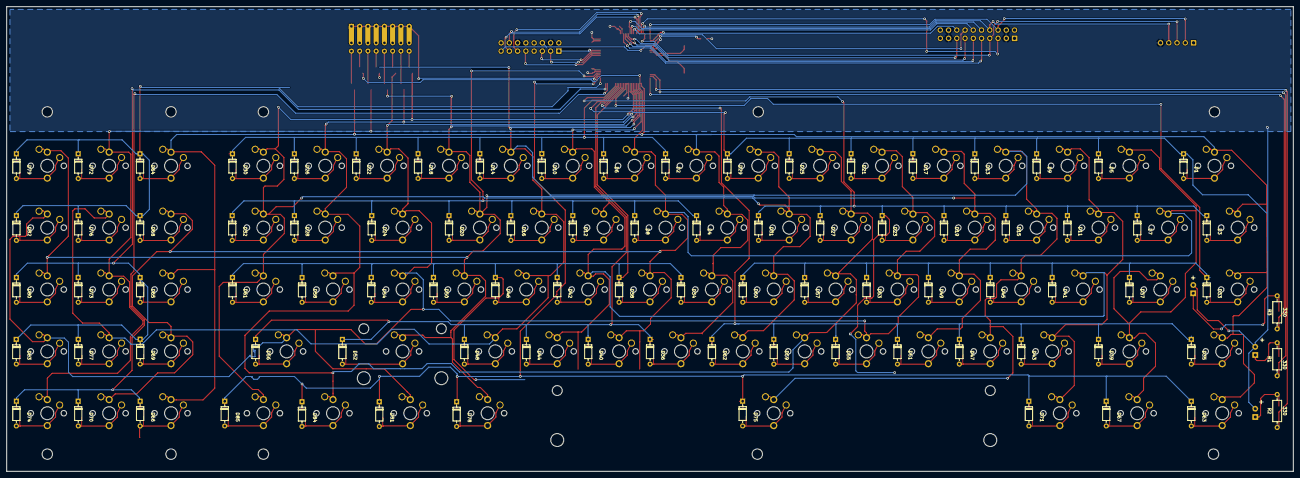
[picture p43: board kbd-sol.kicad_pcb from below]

Board: 2 copper layers, 396.2 x 143.1 mm, 201 parts (3 on the bottom side), 144 nets.

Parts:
C1, C2: 36pf; C_0603_1608Metric
C3, C4, C5, C6, C7: 0.1 uF; C_0603_1608Metric
D1, D2, D3, D4, D5, D6, D7, D8, D9, D10, D11, D12, D13, D14, D15, D16, D17, D18, D19, D20, D21, D22, D23, D24, D25, D26, D27, D28, D29, D30, D31, D32, D33, D34, D35, D36, D37, D38, D39, D40, D41, D42, D43, D44, D45, D46, D47, D48, D49, D50, D51, D52, D53, D54, D55, D56, D57, D58, D59, D60, D61, D62, D63, D64, D65, D66, D67, D68, D69, D70, D71, D72, D73, D74, D75, D76, D77, D78, D79, D80, D81, D82, D83, D84, D85: 1N4148; diode-combined
D86, D87, D88, D89, D90, D91, D92, D93: 1N4148; D_SOT-23_ANK
J1: Outputs; PinHeader_1x05_P2.54mm_Horizontal
J2: SOL-20; SOL20-header-vertical
J3: Programming; PinHeader_2x08_P2.54mm_Horizontal
LED1, LED2, LED3: LED; LED_D3.0mm
R1, R2, R3: 330; R_Axial_DIN0207_L6.3mm_D2.5mm_P10.16mm_Horizontal
R4, R5, R6: 330; R_0805_2012Metric
R7: 10k; R_0603_1608Metric
SW1: Options; SW_DIP_SPSTx08_oriented_backward
SW4: ESC: 1.75x; Key_MX
SW5: 8; Key_MX
SW6: BREAK; Key_MX
SW7: U; Key_MX
SW8: 1; Key_MX
SW9: 9; Key_MX
SW10: TAB: 1.25x; Key_MX
SW11: I; Key_MX
SW12: 2; Key_MX
SW13: Zero; Key_MX
SW14: Q; Key_MX
SW15: O; Key_MX
SW16: 3; Key_MX
SW17: Dash; Key_MX
SW18: W; Key_MX
SW19: P; Key_MX
SW20: 4; Key_MX
SW21: Caret; Key_MX
SW22: E; Key_MX
SW23: AT; Key_MX
SW24: 5; Key_MX
SW25: LT Bracket; Key_MX
SW26: R; Key_MX
SW27: Return: 1.5x; Key_MX
SW28: 6; Key_MX
SW29: Backslash; Key_MX
SW30: T; Key_MX
SW31: Line Feed; Key_MX
SW32: 7; Key_MX
SW33: RT Bracket; Key_MX
SW34: Y; Key_MX
SW35: Load; Key_MX
SW36: LT Ctrl; Key_MX
SW37: J; Key_MX
SW38: Upper Case: 1.5x; Key_MX
SW39: M; Key_MX
SW40: Shift Lock: 1.5x; Key_MX
SW41: K; Key_MX
SW42: LT Shift: 1.5x; Key_MX
SW43: Comma; Key_MX
SW44: A; Key_MX
SW45: L; Key_MX
SW46: Z; Key_MX
SW47: Period; Key_MX
SW48: S; Key_MX
SW49: Semicolon; Key_MX
SW50: X; Key_MX
SW51: Slash; Key_MX
SW52: D; Key_MX
SW53: Colon; Key_MX
SW54: C; Key_MX
SW55: RT Shift: 2x; Key_MX_2u
SW56: F; Key_MX
SW57: DEL; Key_MX
SW58: V; Key_MX
SW59: Mode Select: 1.75x; Key_MX
SW60: G; Key_MX
SW61: Repeat: 1.25x; Key_MX
SW62: B; Key_MX
SW63: H; Key_MX
SW64: RT Ctrl; Key_MX
SW65: N; Key_MX
SW66: Local; Key_MX
SW67: NP Dash; Key_MX
SW68: NP 4; Key_MX
SW69: NP Zero; Key_MX
SW70: Up Arrow; Key_MX
SW71: NP 7; Key_MX
SW72: NP 1; Key_MX
SW73: NP period; Key_MX
SW74: LT Arrow; Key_MX
SW75: NP asterisk; Key_MX
SW76: NP 5; Key_MX
SW77: NP plus; Key_MX
SW78: Spacebar; Key_MX_Spacebar_5.25
SW79: NP 8; Key_MX
SW80: NP 2; Key_MX
SW81: RT Arrow; Key_MX
SW82: NP divide; Key_MX
SW83: NP 6; Key_MX
SW84: Down Arrow; Key_MX
SW85: NP 9; Key_MX
SW86: NP 3; Key_MX
SW87: Home; Key_MX
SW88: Clear; Key_MX
U1: ATmega2560-16AU; TQFP-100_14x14mm_P0.5mm
Y1: 16.000 MHz; Crystal_SMD_HC49-SD

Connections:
/Col0: D90.2, SW4.1, SW5.1, SW6.1, SW7.1, SW36.1, SW37.1, SW38.1, SW39.1, SW66.1, SW67.1, SW68.1, SW69.1, U1.53
/Col1: D89.2, SW8.1, SW9.1, SW10.1, SW11.1, SW40.1, SW41.1, SW42.1, SW43.1, SW70.1, SW71.1, SW72.1, SW73.1, U1.54
/Col2: D91.2, SW12.1, SW13.1, SW14.1, SW15.1, SW44.1, SW45.1, SW46.1, SW47.1, SW74.1, SW75.1, SW76.1, SW77.1, U1.55
/Col3: D86.2, SW16.1, SW17.1, SW18.1, SW19.1, SW48.1, SW49.1, SW50.1, SW51.1, SW78.1, SW79.1, SW80.1, U1.56
/Col4: D92.2, SW20.1, SW21.1, SW22.1, SW23.1, SW52.1, SW53.1, SW54.1, SW55.1, SW81.1, SW82.1, SW83.1, U1.57
/Col5: D87.2, SW24.1, SW25.1, SW26.1, SW27.1, SW56.1, SW57.1, SW58.1, SW59.1, SW84.1, SW85.1, SW86.1, U1.58
/Col6: D93.2, SW28.1, SW29.1, SW30.1, SW31.1, SW60.1, SW61.1, SW62.1, SW87.1, U1.59
/Col7: D88.2, SW32.1, SW33.1, SW34.1, SW35.1, SW63.1, SW64.1, SW65.1, SW88.1, U1.60
/Row0: D33.1, D37.1, D41.1, D45.1, D49.1, D53.1, D57.1, D60.1, U1.63
/Row1: D34.1, D38.1, D42.1, D46.1, D50.1, D54.1, D58.1, D61.1, U1.64
/Row2: D35.1, D39.1, D43.1, D47.1, D51.1, D55.1, D59.1, D62.1, U1.65
/Row3: D36.1, D40.1, D44.1, D48.1, D52.1, D56.1, U1.66
/Row4: D1.1, D5.1, D9.1, D13.1, D17.1, D21.1, D25.1, D29.1, U1.67
/Row5: D2.1, D6.1, D10.1, D14.1, D18.1, D22.1, D26.1, D30.1, U1.68
/Row6: D3.1, D7.1, D11.1, D15.1, D19.1, D23.1, D27.1, D31.1, U1.69
/Row7: D4.1, D8.1, D12.1, D16.1, D20.1, D24.1, D28.1, D32.1, U1.79
/Row9: D63.1, D67.1, D71.1, D75.1, D78.1, D81.1, D84.1, D85.1, U1.77
/Row10: D64.1, D68.1, D72.1, D76.1, D79.1, D82.1, U1.76
/Row11: D65.1, D69.1, D73.1, D77.1, D80.1, D83.1, U1.75
/Row12: D66.1, D70.1, D74.1, U1.74
/encoder/D0: J2.5, U1.12
/encoder/D1: J2.6, U1.13
/encoder/D2: J2.7, U1.14
/encoder/D3: J2.8, U1.15
/encoder/D4: J2.15, U1.16
/encoder/D5: J2.16, U1.17
/encoder/D6: J2.17, U1.18
/encoder/D7: J2.18, U1.27
/encoder/LED1: R1.1, R4.1, U1.48
/encoder/LED2: R2.1, R5.1, U1.49
/encoder/LED3: R3.1, R6.1, U1.50
/encoder/MISO: J3.11, U1.22
/encoder/MOSI: J3.14, U1.21
/encoder/OUT1: J1.4, J2.14, U1.24
/encoder/OUT2: J1.3, J2.4, U1.25
/encoder/OUT3: J1.2, J2.13, U1.26
/encoder/Row8: SW1.1, SW1.2, SW1.3, SW1.4, SW1.5, SW1.6, SW1.7, SW1.8, U1.78
/encoder/SCK: J3.13, U1.20
/encoder/TCK: J3.1, U1.93
/encoder/TDI: J3.9, U1.90
/encoder/TDO: J3.3, U1.91
/encoder/TMS: J3.5, U1.92
/encoder/~RESET: J3.6, J3.15, R7.2, U1.30
/encoder/~STROBE: J2.3, U1.23
GND: C1.2, C2.2, C3.2, C4.2, C5.2, C6.2, C7.2, J1.1, J2.1, J2.10, J2.11, J2.20, J3.2, J3.10, J3.16, U1.11, U1.32, U1.62, U1.81, U1.99
unnamed: C1.1, U1.34, Y1.2
unnamed: C2.1, U1.33, Y1.1
unnamed: D1.2, SW4.2
unnamed: D2.2, SW5.2
unnamed: D3.2, SW6.2
unnamed: D4.2, SW7.2
unnamed: D5.2, SW8.2
unnamed: D6.2, SW9.2
unnamed: D7.2, SW10.2
unnamed: D8.2, SW11.2
unnamed: D9.2, SW12.2
unnamed: D10.2, SW13.2
unnamed: D11.2, SW14.2
unnamed: D12.2, SW15.2
unnamed: D13.2, SW16.2
unnamed: D14.2, SW17.2
unnamed: D15.2, SW18.2
unnamed: D16.2, SW19.2
unnamed: D17.2, SW20.2
unnamed: D18.2, SW21.2
unnamed: D19.2, SW22.2
unnamed: D20.2, SW23.2
unnamed: D21.2, SW24.2
unnamed: D22.2, SW25.2
unnamed: D23.2, SW26.2
unnamed: D24.2, SW27.2
unnamed: D25.2, SW28.2
unnamed: D26.2, SW29.2
unnamed: D27.2, SW30.2
unnamed: D28.2, SW31.2
unnamed: D29.2, SW32.2
unnamed: D30.2, SW33.2
unnamed: D31.2, SW34.2
unnamed: D32.2, SW35.2
unnamed: D33.2, SW36.2
unnamed: D34.2, SW37.2
unnamed: D35.2, SW38.2
unnamed: D36.2, SW39.2
unnamed: D37.2, SW40.2
unnamed: D38.2, SW41.2
unnamed: D39.2, SW42.2
unnamed: D40.2, SW43.2
unnamed: D41.2, SW44.2
unnamed: D42.2, SW45.2
unnamed: D43.2, SW46.2
unnamed: D44.2, SW47.2
unnamed: D45.2, SW48.2
unnamed: D46.2, SW49.2
unnamed: D47.2, SW50.2
unnamed: D48.2, SW51.2
unnamed: D49.2, SW52.2
unnamed: D50.2, SW53.2
unnamed: D51.2, SW54.2
unnamed: D52.2, SW55.2
unnamed: D53.2, SW56.2
unnamed: D54.2, SW57.2
unnamed: D55.2, SW58.2
unnamed: D56.2, SW59.2
unnamed: D57.2, SW60.2
unnamed: D58.2, SW61.2
unnamed: D59.2, SW62.2
unnamed: D60.2, SW63.2
unnamed: D61.2, SW64.2
unnamed: D62.2, SW65.2
unnamed: D63.2, SW66.2
unnamed: D64.2, SW67.2
unnamed: D65.2, SW68.2
unnamed: D66.2, SW69.2
unnamed: D67.2, SW70.2
unnamed: D68.2, SW71.2
unnamed: D69.2, SW72.2
unnamed: D70.2, SW73.2
unnamed: D71.2, SW74.2
unnamed: D72.2, SW75.2
unnamed: D73.2, SW76.2
unnamed: D74.2, SW77.2
unnamed: D75.2, SW78.2
unnamed: D76.2, SW79.2
unnamed: D77.2, SW80.2
unnamed: D78.2, SW81.2
unnamed: D79.2, SW82.2
unnamed: D80.2, SW83.2
unnamed: D81.2, SW84.2
unnamed: D82.2, SW85.2
unnamed: D83.2, SW86.2
unnamed: D84.2, SW87.2
unnamed: D85.2, SW88.2
unnamed: D86.1, SW1.13
unnamed: D87.1, SW1.11
unnamed: D88.1, SW1.9
unnamed: D89.1, SW1.15
unnamed: D90.1, SW1.16
unnamed: D91.1, SW1.14
unnamed: D92.1, SW1.12
unnamed: D93.1, SW1.10
unnamed: LED1.1, R1.2, R4.2
unnamed: LED2.1, R2.2, R5.2
unnamed: LED3.1, R3.2, R6.2
VCC: C3.1, C4.1, C5.1, C6.1, C7.1, J1.5, J2.2, J2.9, J2.12, J2.19, J3.4, J3.12, LED1.2, LED2.2, LED3.2, R7.1, U1.10, U1.31, U1.61, U1.80, U1.100

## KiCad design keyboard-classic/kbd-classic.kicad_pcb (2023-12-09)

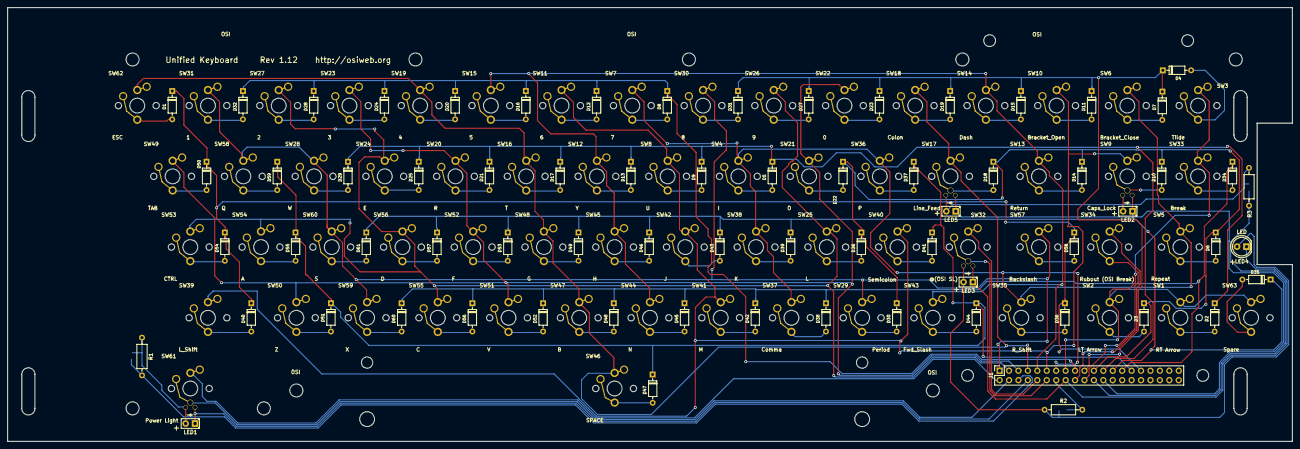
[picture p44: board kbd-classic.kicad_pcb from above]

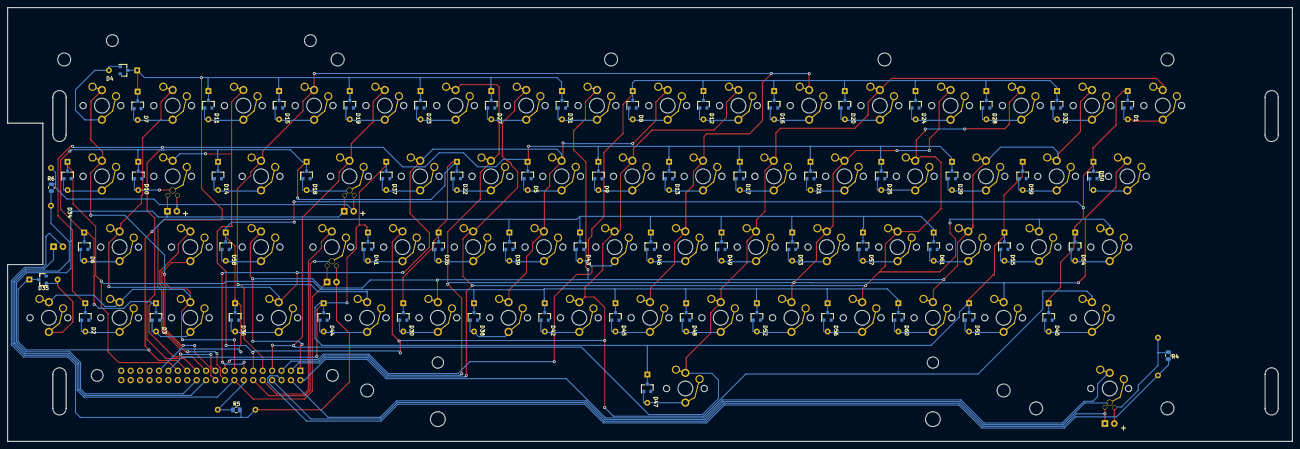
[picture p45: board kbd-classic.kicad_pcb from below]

Board: 2 copper layers, 346.1 x 116.8 mm, 135 parts (63 on the bottom side), 91 nets.

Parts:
D1, D2, D3, D4, D5, D6, D7, D8, D9, D10, D11, D12, D13, D14, D15, D16, D17, D18, D19, D20, D21, D22, D23, D24, D25, D26, D27, D28, D29, D30, D31, D32, D34, D35, D36, D37, D38, D39, D40, D41, D42, D43, D44, D45, D46, D47, D48, D49, D50, D51, D52, D53, D54, D55, D56, D57, D58, D59, D60, D61: 1N4148; diode-combined
J1: Controller; kbd_header_and_mounting_holes
LED1, LED2, LED3, LED5: LED; LED_D2.0mm_W4.8mm_H2.5mm_FlatTop
LED4: LED; LED_D5.0mm
R1, R2, R3: 470; R_Axial_DIN0207_L6.3mm_D2.5mm_P10.16mm_Horizontal
R4, R5, R6: 470; R_0805_2012Metric
SW1: RT Arrow; Key_MX
SW2: LT Arrow; Key_MX
SW3: Tilde; Key_MX
SW4: I; Key_MX
SW5: Repeat; Key_MX
SW6: Bracket_Close; Key_MX
SW7: 7; Key_MX
SW8: U; Key_MX
SW9: Caps_Lock; Key_MX_LED
SW10: Bracket_Open; Key_MX
SW11: 6; Key_MX
SW12: Y; Key_MX
SW13: Return; Key_MX
SW14: Dash; Key_MX
SW15: 5; Key_MX
SW16: T; Key_MX
SW17: Line_Feed; Key_MX_LED
SW18: Colon; Key_MX
SW19: 4; Key_MX
SW20: R; Key_MX
SW21: O; Key_MX
SW22: 0; Key_MX
SW23: 3; Key_MX
SW24: E; Key_MX
SW25: L; Key_MX
SW26: 9; Key_MX
SW27: 2; Key_MX
SW28: W; Key_MX
SW29: Period; Key_MX
SW30: 8; Key_MX
SW31: 1; Key_MX
SW32: @(OSI SL); Key_MX_LED
SW33: Break; Key_MX
SW34: Rubout (OSI Break); Key_MX
SW35: R_Shift; Key_MX
SW36: P; Key_MX
SW37: Comma; Key_MX
SW38: K; Key_MX
SW39: L_Shift; Key_MX
SW40: Semicolon; Key_MX
SW41: M; Key_MX
SW42: J; Key_MX
SW43: Fwd_Slash; Key_MX
SW44: N; Key_MX
SW45: H; Key_MX
SW46: SPACE; Key_MX_Spacebar_5.25
SW47: B; Key_MX
SW48: G; Key_MX
SW49: TAB; Key_MX
SW50: Z; Key_MX
SW51: V; Key_MX
SW52: F; Key_MX
SW53: CTRL; Key_MX
SW54: A; Key_MX
SW55: C; Key_MX
SW56: D; Key_MX
SW57: Backslash; Key_MX
SW58: Q; Key_MX
SW59: X; Key_MX
SW60: S; Key_MX
SW61: Power Light; Key_MX_LED
SW62: ESC; Key_MX
SW63: Spare; Key_MX

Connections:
/Col0: J1.15, SW1.1, SW2.1, SW3.1, SW33.1, SW63.1
/Col1: J1.13, SW4.1, SW5.1, SW6.1, SW7.1, SW35.1, SW36.1, SW37.1, SW38.1
/Col2: J1.11, SW8.1, SW9.1, SW10.1, SW11.1, SW39.1, SW40.1, SW41.1, SW42.1
/Col3: J1.9, SW12.1, SW13.1, SW14.1, SW15.1, SW43.1, SW44.1, SW45.1
/Col4: J1.7, SW16.1, SW17.1, SW18.1, SW19.1, SW46.1, SW47.1, SW48.1, SW62.1
/Col5: J1.5, SW20.1, SW21.1, SW22.1, SW23.1, SW49.1, SW50.1, SW51.1, SW52.1
/Col6: J1.3, SW24.1, SW25.1, SW26.1, SW27.1, SW53.1, SW54.1, SW55.1, SW56.1
/Col7: J1.1, SW28.1, SW29.1, SW30.1, SW31.1, SW57.1, SW58.1, SW59.1, SW60.1
/Row0: D1.1 (K), D36.1 (K), D40.1 (K), D50.1 (K), D54.1 (K), D58.1 (K), J1.31
/Row1: D37.1 (K), D41.1 (K), D44.1 (K), D47.1 (K), D51.1 (K), D55.1 (K), D59.1 (K), J1.29
/Row2: D34.1 (K), D38.1 (K), D42.1 (K), D45.1 (K), D48.1 (K), D52.1 (K), D56.1 (K), D60.1 (K), J1.27
/Row3: D35.1 (K), D39.1 (K), D43.1 (K), D46.1 (K), D49.1 (K), D53.1 (K), D57.1 (K), D61.1 (K), J1.25
/Row4: D2.1 (K), D5.1 (K), D9.1 (K), D13.1 (K), D17.1 (K), D21.1 (K), D25.1 (K), D29.1 (K), J1.23
/Row5: D3.1 (K), D6.1 (K), D10.1 (K), D14.1 (K), D18.1 (K), D22.1 (K), D26.1 (K), D30.1 (K), J1.21
/Row6: D4.1 (K), D7.1 (K), D11.1 (K), D15.1 (K), D19.1 (K), D23.1 (K), D27.1 (K), D31.1 (K), J1.19
/Row7: D8.1 (K), D12.1 (K), D16.1 (K), D20.1 (K), D24.1 (K), D28.1 (K), D32.1 (K), J1.17
unnamed: D1.2 (A), SW62.2
unnamed: D2.2 (A), SW1.2
unnamed: D3.2 (A), SW2.2
unnamed: D4.2 (A), SW3.2
unnamed: D5.2 (A), SW4.2
unnamed: D6.2 (A), SW5.2
unnamed: D7.2 (A), SW6.2
unnamed: D8.2 (A), SW7.2
unnamed: D9.2 (A), SW8.2
unnamed: D10.2 (A), SW9.2
unnamed: D11.2 (A), SW10.2
unnamed: D12.2 (A), SW11.2
unnamed: D13.2 (A), SW12.2
unnamed: D14.2 (A), SW13.2
unnamed: D15.2 (A), SW14.2
unnamed: D16.2 (A), SW15.2
unnamed: D17.2 (A), SW16.2
unnamed: D18.2 (A), SW17.2
unnamed: D19.2 (A), SW18.2
unnamed: D20.2 (A), SW19.2
unnamed: D21.2 (A), SW20.2
unnamed: D22.2 (A), SW21.2
unnamed: D23.2 (A), SW22.2
unnamed: D24.2 (A), SW23.2
unnamed: D25.2 (A), SW24.2
unnamed: D26.2 (A), SW25.2
unnamed: D27.2 (A), SW26.2
unnamed: D28.2 (A), SW27.2
unnamed: D29.2 (A), SW28.2
unnamed: D30.2 (A), SW29.2
unnamed: D31.2 (A), SW30.2
unnamed: D32.2 (A), SW31.2
unnamed: D34.2 (A), SW33.2
unnamed: D35.2 (A), SW63.2
unnamed: D36.2 (A), SW35.2
unnamed: D37.2 (A), SW36.2
unnamed: D38.2 (A), SW37.2
unnamed: D39.2 (A), SW38.2
unnamed: D40.2 (A), SW39.2
unnamed: D41.2 (A), SW40.2
unnamed: D42.2 (A), SW41.2
unnamed: D43.2 (A), SW42.2
unnamed: D44.2 (A), SW43.2
unnamed: D45.2 (A), SW44.2
unnamed: D46.2 (A), SW45.2
unnamed: D47.2 (A), SW46.2
unnamed: D48.2 (A), SW47.2
unnamed: D49.2 (A), SW48.2
unnamed: D50.2 (A), SW49.2
unnamed: D51.2 (A), SW50.2
unnamed: D52.2 (A), SW51.2
unnamed: D53.2 (A), SW52.2
unnamed: D54.2 (A), SW53.2
unnamed: D55.2 (A), SW54.2
unnamed: D56.2 (A), SW55.2
unnamed: D57.2 (A), SW56.2
unnamed: D58.2 (A), SW57.2
unnamed: D59.2 (A), SW58.2
unnamed: D60.2 (A), SW59.2
unnamed: D61.2 (A), SW60.2
unnamed: J1.2, SW61.1
unnamed: J1.4, SW61.2
unnamed: J1.6, R1.2, R4.2
unnamed: J1.8, LED1.1 (K), SW61.4
unnamed: J1.10, SW32.1
unnamed: J1.12, SW32.2
unnamed: J1.14, R2.2, R5.2
unnamed: J1.16, LED3.1 (K), LED4.1 (K), SW32.4
unnamed: J1.18, SW34.1
unnamed: J1.20, SW34.2
unnamed: J1.22, R3.1, R6.1
unnamed: J1.24, LED2.1 (K), LED5.1 (K), SW9.4, SW17.4
unnamed: LED1.2 (A), R1.1, R4.1, SW61.3
unnamed: LED2.2 (A), LED5.2 (A), R3.2, R6.2, SW9.3, SW17.3
unnamed: LED3.2 (A), LED4.2 (A), R2.1, R5.1, SW32.3

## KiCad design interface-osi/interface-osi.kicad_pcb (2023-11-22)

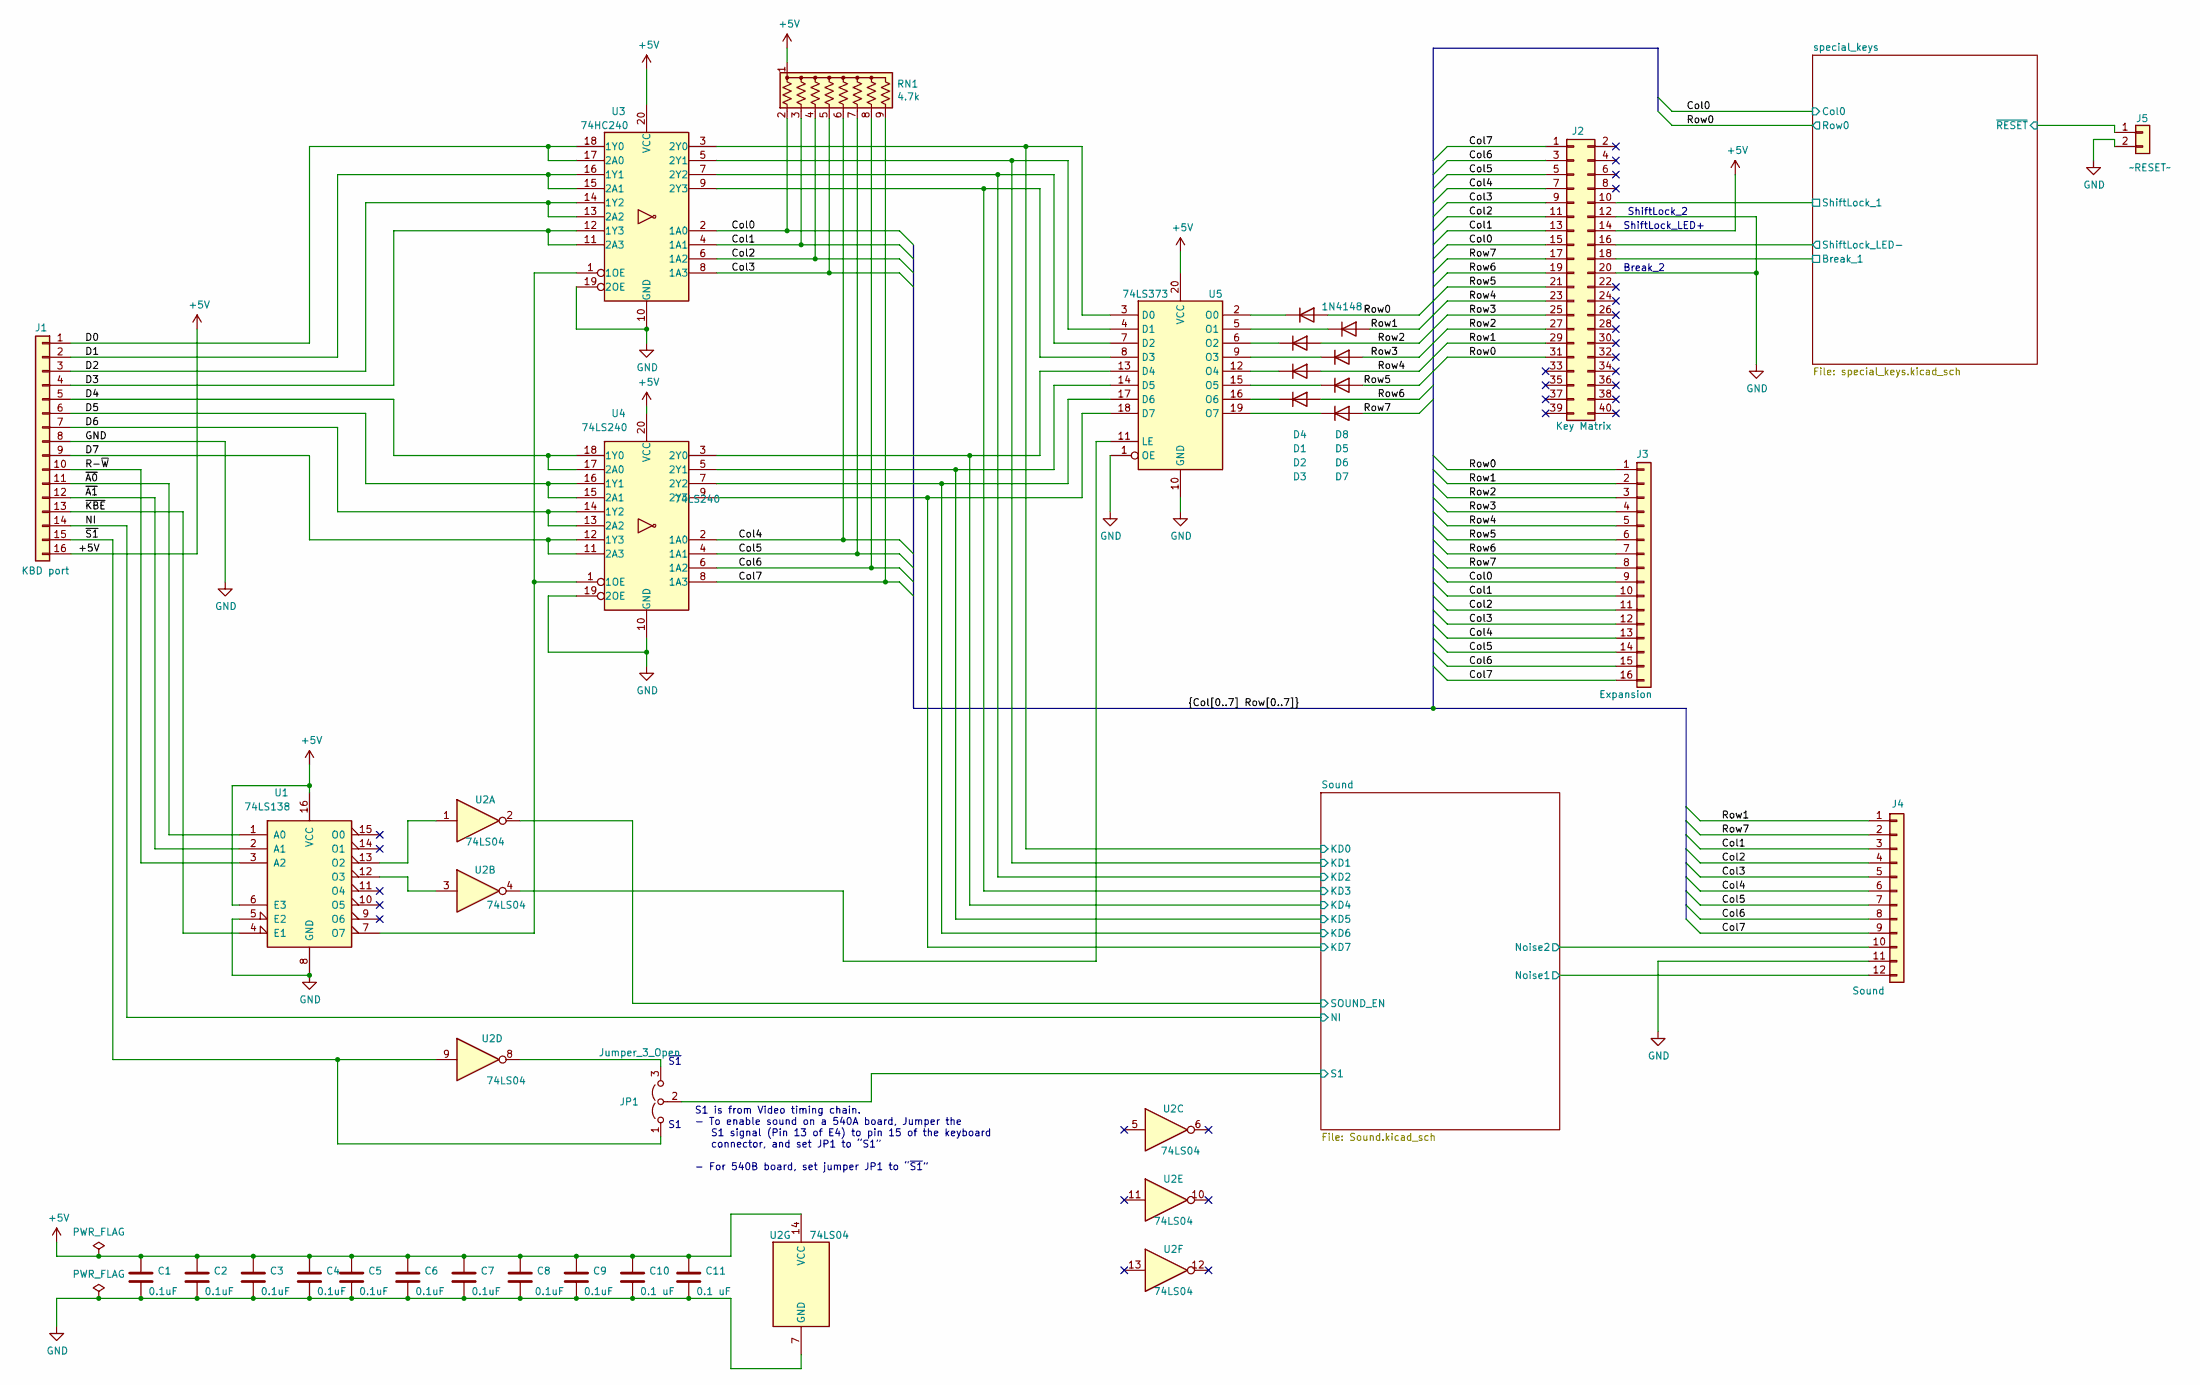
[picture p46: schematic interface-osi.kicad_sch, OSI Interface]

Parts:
C1, C2, C3, C4, C5, C6, C7, C8, C9: 0.1uF; C_Disc_D3.0mm_W2.0mm_P2.50mm
C10, C11: 0.1 uF; C_Disc_D3.0mm_W2.0mm_P2.50mm
D1, D2, D3, D4, D5, D6, D7, D8: 1N4148; D_DO-35_SOD27_P7.62mm_Horizontal_bypassed
J1: KBD port; DIP-16_W7.62mm_Socket
J2: Key Matrix; kbd_header_and_mounting_holes
J3: Expansion; DIP-16_W7.62mm_Socket
J4: Sound; Molex_KK-396_A-41791-0012_1x12_P3.96mm_Vertical
J5: ~RESET~; Molex_KK-396_A-41791-0002_1x02_P3.96mm_Vertical
JP1: Jumper_3_Open; PinHeader_1x03_P2.54mm_Horizontal
RN1: 4.7k; R_Array_SIP9
U1: 74LS138; DIP-16_W7.62mm
U2: 74LS04; DIP-14_W7.62mm
U3: 74HC240; DIP-20_W7.62mm; Tolerance n/a; Power Rating If applicable; Manufacturer PN SN74LS240N
U4: 74LS240; DIP-20_W7.62mm; Tolerance n/a; Power Rating If applicable; Manufacturer PN SN74LS240N
U5: 74LS373; DIP-20_W7.62mm

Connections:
+5V: C1.1, C2.1, C3.1, C4.1, C5.1, C6.1, C7.1, C8.1, C9.1, C10.1, C11.1, J1.16, J2.14, RN1.1 (common), U1.6 (E3), U1.16 (VCC), U2.14 (VCC), U3.20 (VCC), U4.20 (VCC), U5.20 (VCC); also elsewhere on the board
/Col0: J2.15, J3.9, RN1.2 (R1), U3.2 (1A0); also elsewhere on the board
/Col1: J2.13, J3.10, J4.3, RN1.3 (R2), U3.4 (1A1)
/Col2: J2.11, J3.11, J4.4, RN1.4 (R3), U3.6 (1A2)
/Col3: J2.9, J3.12, J4.5, RN1.5 (R4), U3.8 (1A3)
/Col4: J2.7, J3.13, J4.6, RN1.6 (R5), U4.2 (1A0)
/Col5: J2.5, J3.14, J4.7, RN1.7 (R6), U4.4 (1A1)
/Col6: J2.3, J3.15, J4.8, RN1.8 (R7), U4.6 (1A2)
/Col7: J2.1, J3.16, J4.9, RN1.9 (R8), U4.8 (1A3)
/D0: J1.1, U3.17 (2A0), U3.18 (1Y0)
/D1: J1.2, U3.15 (2A1), U3.16 (1Y1)
/D2: J1.3, U3.13 (2A2), U3.14 (1Y2)
/D3: J1.4, U3.11 (2A3), U3.12 (1Y3)
/D4: J1.5, U4.17 (2A0), U4.18 (1Y0)
/D5: J1.6, U4.15 (2A1), U4.16 (1Y1)
/D6: J1.7, U4.13 (2A2), U4.14 (1Y2)
/D7: J1.9, U4.11 (2A3), U4.12 (1Y3)
/NI: J1.14; also elsewhere on the board
/R-~W: J1.10, U1.3 (A2)
/Row0: D4.2 (A), J2.31, J3.1; also elsewhere on the board
/Row1: D8.2 (A), J2.29, J3.2, J4.1
/Row2: D1.2 (A), J2.27, J3.3
/Row3: D5.2 (A), J2.25, J3.4
/Row4: D2.2 (A), J2.23, J3.5
/Row5: D6.2 (A), J2.21, J3.6
/Row6: D3.2 (A), J2.19, J3.7
/Row7: D7.2 (A), J2.17, J3.8, J4.2
/Sound/KD0: U3.3 (2Y0), U5.3 (D0); also elsewhere on the board
/Sound/KD1: U3.5 (2Y1), U5.4 (D1); also elsewhere on the board
/Sound/KD2: U3.7 (2Y2), U5.7 (D2); also elsewhere on the board
/Sound/KD3: U3.9 (2Y3), U5.8 (D3); also elsewhere on the board
/Sound/KD4: U4.3 (2Y0), U5.13 (D4); also elsewhere on the board
/Sound/KD5: U4.5 (2Y1), U5.14 (D5); also elsewhere on the board
/Sound/KD6: U4.7 (2Y2), U5.17 (D6); also elsewhere on the board
/Sound/KD7: U4.9 (2Y3), U5.18 (D7); also elsewhere on the board
/Sound/Noise1: J4.12; also elsewhere on the board
/Sound/S1: JP1.2 (C); also elsewhere on the board
/Sound/SOUND_EN: U2.2; also elsewhere on the board
/special_keys/Break_1: J2.18; also elsewhere on the board
/special_keys/ShiftLock_1: J2.10; also elsewhere on the board
/special_keys/ShiftLock_LED-: J2.16; also elsewhere on the board
/special_keys/~RESET: J5.1; also elsewhere on the board
/~A0: J1.11, U1.1 (A0)
/~A1: J1.12, U1.2 (A1)
/~KBE: J1.13, U1.4 (E1)
/~S1: J1.15, JP1.1 (A), U2.9
GND: C1.2, C2.2, C3.2, C4.2, C5.2, C6.2, C7.2, C8.2, C9.2, C10.2, C11.2, J1.8, J2.12, J2.20, J4.11, J5.2, U1.5 (E2), U1.8 (GND), U2.7 (GND), U3.10 (GND), U3.19 (2OE), U4.10 (GND), U4.19 (2OE), U5.1 (OE), U5.10 (GND); also elsewhere on the board
unnamed: D1.1 (K), U5.6 (O2)
unnamed: D2.1 (K), U5.12 (O4)
unnamed: D3.1 (K), U5.16 (O6)
unnamed: D4.1 (K), U5.2 (O0)
unnamed: D5.1 (K), U5.9 (O3)
unnamed: D6.1 (K), U5.15 (O5)
unnamed: D7.1 (K), U5.19 (O7)
unnamed: D8.1 (K), U5.5 (O1)
unnamed: JP1.3 (B), U2.8
unnamed: U1.13 (O2), U2.1
unnamed: U1.12 (O3), U2.3
unnamed: U1.7 (O7), U3.1 (1OE), U4.1 (1OE)
unnamed: U2.4, U5.11 (LE)

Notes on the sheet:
ShiftLock_2
ShiftLock_LED+
S1 is from Video timing chain. - To enable sound on a 540A board, Jumper the S1 signal (Pin 13 of E4) to pin 15 of the keyboard connector, and set JP1 to “S1” - For 540B board, set jumper JP1 to “~{S1}”
Break_2
~{S1}

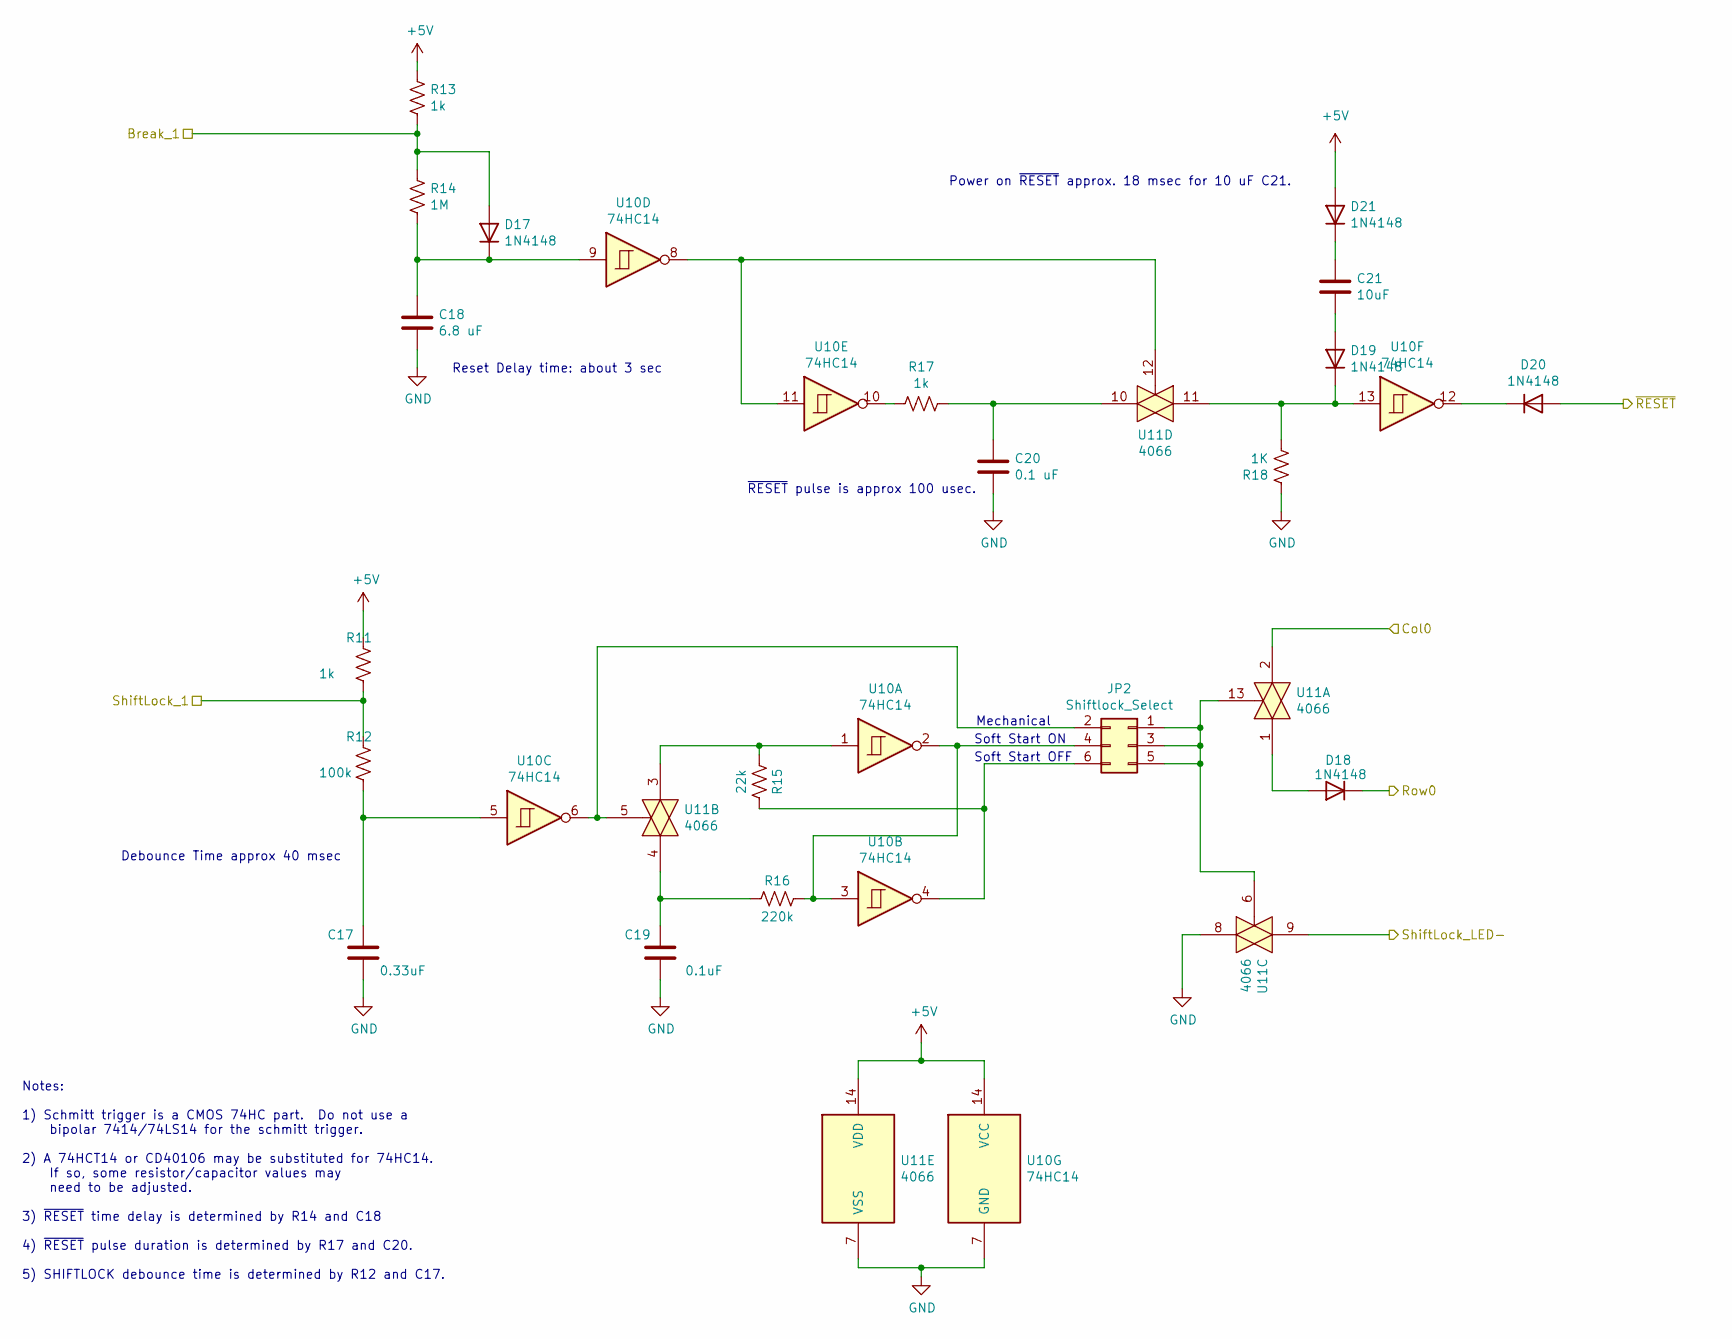
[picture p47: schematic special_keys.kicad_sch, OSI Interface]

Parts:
C17: 0.33uF; C_Disc_D3.0mm_W2.0mm_P2.50mm
C18: 6.8 uF; C_Disc_D3.0mm_W2.0mm_P2.50mm
C19: 0.1uF; C_Disc_D3.0mm_W2.0mm_P2.50mm
C20: 0.1 uF; C_Disc_D3.0mm_W2.0mm_P2.50mm
C21: 10uF; C_Disc_D3.0mm_W2.0mm_P2.50mm
D17, D18, D19, D20, D21: 1N4148; D_DO-35_SOD27_P7.62mm_Horizontal
JP2: Shiftlock_Select; PinHeader_2x03_P2.54mm_Horizontal
R11, R13, R17: 1k; R_Axial_DIN0207_L6.3mm_D2.5mm_P10.16mm_Horizontal
R12: 100k; R_Axial_DIN0207_L6.3mm_D2.5mm_P10.16mm_Horizontal
R14: 1M; R_Axial_DIN0207_L6.3mm_D2.5mm_P10.16mm_Horizontal
R15: 22k; R_Axial_DIN0207_L6.3mm_D2.5mm_P10.16mm_Horizontal
R16: 220k; R_Axial_DIN0207_L6.3mm_D2.5mm_P10.16mm_Horizontal
R18: 1K; R_Axial_DIN0207_L6.3mm_D2.5mm_P10.16mm_Horizontal
U10: 74HC14; DIP-14_W7.62mm
U11: 4066; DIP-14_W7.62mm

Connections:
+5V: D21.2 (A), R11.1, R13.1, U10.14 (VCC), U11.14 (VDD); also elsewhere on the board
/Col0: U11.2; also elsewhere on the board
/Row0: D18.1 (K); also elsewhere on the board
/special_keys/Break_1: D17.2 (A), R13.2, R14.1; also elsewhere on the board
/special_keys/ShiftLock_1: R11.2, R12.1; also elsewhere on the board
/special_keys/ShiftLock_LED-: U11.9; also elsewhere on the board
/special_keys/~RESET: D20.2 (A); also elsewhere on the board
GND: C17.1, C18.2, C19.1, C20.2, R18.1, U10.7 (GND), U11.7 (VSS), U11.8; also elsewhere on the board
unnamed: C17.2, R12.2, U10.5
unnamed: C19.2, R16.1, U11.4
unnamed: C20.1, R17.1, U11.10
unnamed: C18.1, D17.1 (K), R14.2, U10.9
unnamed: D18.2 (A), U11.1
unnamed: C21.2, D19.2 (A)
unnamed: D19.1 (K), R18.2, U10.13, U11.11
unnamed: D20.1 (K), U10.12
unnamed: C21.1, D21.1 (K)
unnamed: JP2.1, JP2.3, JP2.5, U11.6, U11.13
unnamed: JP2.2, U10.6, U11.5
unnamed: JP2.4, R16.2, U10.2, U10.3
unnamed: JP2.6, R15.2, U10.4
unnamed: R15.1, U10.1, U11.3
unnamed: R17.2, U10.10
unnamed: U10.8, U10.11, U11.12

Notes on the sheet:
Power on ~{RESET} approx. 18 msec for 10 uF C21.
Reset Delay time: about 3 sec
Debounce Time approx 40 msec
~{RESET} pulse is approx 100 usec.
Notes: 1) Schmitt trigger is a CMOS 74HC part. Do not use a bipolar 7414/74LS14 for the schmitt trigger. 2) A 74HCT14 or CD40106 may be substituted for 74HC14. If so, some resistor/capacitor values may need to be adjusted. 3) ~{RESET} time delay is determined by R14 and C18 4) ~{RESET} pulse durati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
Mechanical
Soft Start OFF
Soft Start ON

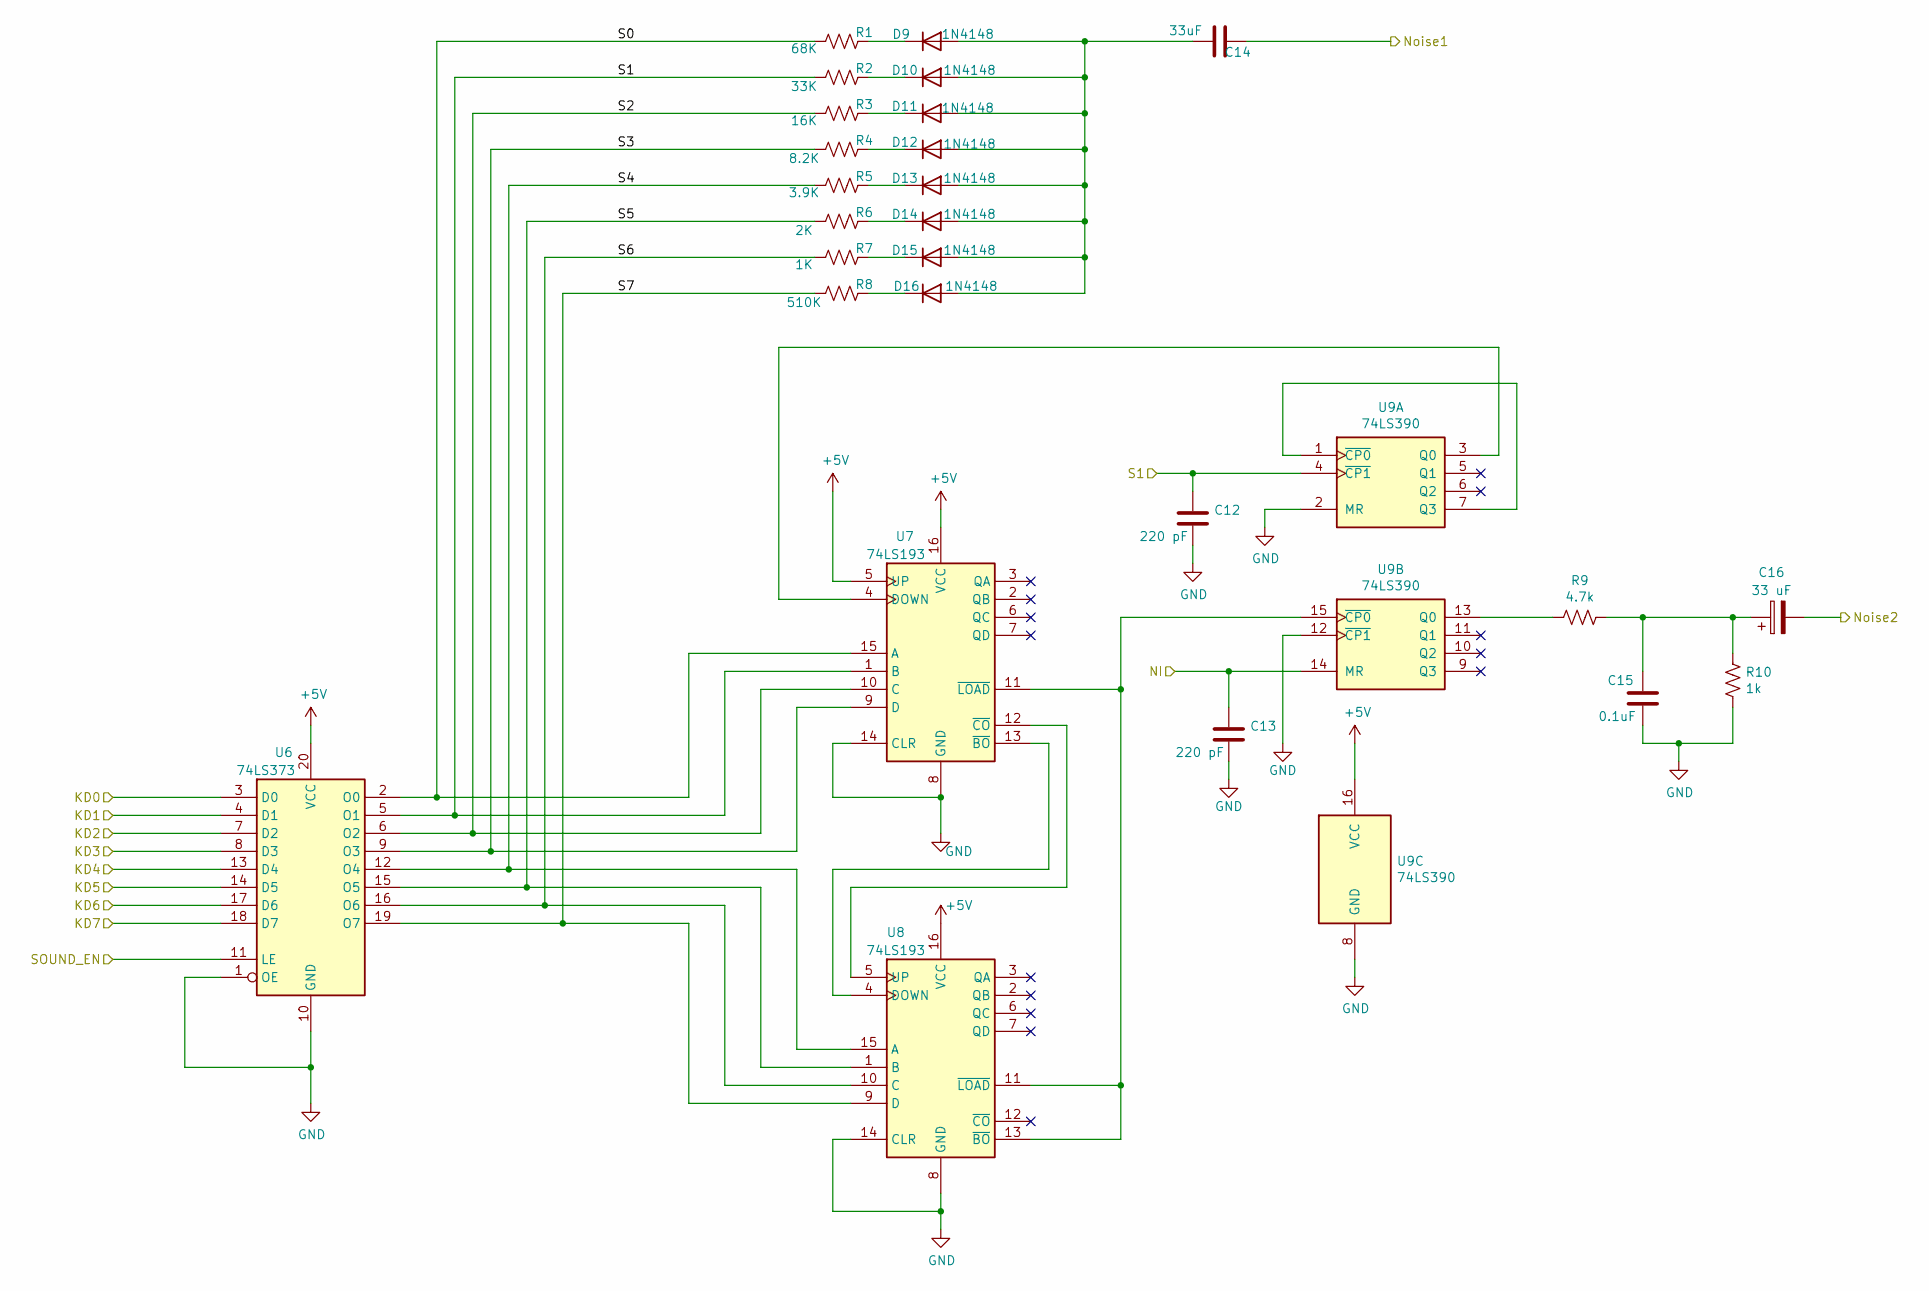
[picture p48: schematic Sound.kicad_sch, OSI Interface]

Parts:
C12, C13: 220 pF; C_Disc_D3.0mm_W2.0mm_P2.50mm
C14: 33uF; C_Disc_D3.0mm_W2.0mm_P2.50mm
C15: 0.1uF; C_Disc_D3.0mm_W2.0mm_P2.50mm
C16: 33 uF; CP_Radial_D4.0mm_P1.50mm
D9, D10, D11, D12, D13, D14, D15, D16: 1N4148; D_DO-35_SOD27_P7.62mm_Horizontal
R1: 68K; R_Axial_DIN0207_L6.3mm_D2.5mm_P10.16mm_Horizontal
R2: 33K; R_Axial_DIN0207_L6.3mm_D2.5mm_P10.16mm_Horizontal
R3: 16K; R_Axial_DIN0207_L6.3mm_D2.5mm_P10.16mm_Horizontal
R4: 8.2K; R_Axial_DIN0207_L6.3mm_D2.5mm_P10.16mm_Horizontal
R5: 3.9K; R_Axial_DIN0207_L6.3mm_D2.5mm_P10.16mm_Horizontal
R6: 2K; R_Axial_DIN0207_L6.3mm_D2.5mm_P10.16mm_Horizontal
R7: 1K; R_Axial_DIN0207_L6.3mm_D2.5mm_P10.16mm_Horizontal
R8: 510K; R_Axial_DIN0207_L6.3mm_D2.5mm_P10.16mm_Horizontal
R9: 4.7k; R_Axial_DIN0207_L6.3mm_D2.5mm_P10.16mm_Horizontal
R10: 1k; R_Axial_DIN0207_L6.3mm_D2.5mm_P10.16mm_Horizontal
U6: 74LS373; DIP-20_W7.62mm
U7, U8: 74LS193; DIP-16_W7.62mm
U9: 74LS390; DIP-16_W7.62mm

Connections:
+5V: U6.20 (VCC), U7.5 (UP), U7.16 (VCC), U8.16 (VCC), U9.16 (VCC); also elsewhere on the board
/NI: C13.1, U9.14 (MR); also elsewhere on the board
/Sound/KD0: U6.3 (D0); also elsewhere on the board
/Sound/KD1: U6.4 (D1); also elsewhere on the board
/Sound/KD2: U6.7 (D2); also elsewhere on the board
/Sound/KD3: U6.8 (D3); also elsewhere on the board
/Sound/KD4: U6.13 (D4); also elsewhere on the board
/Sound/KD5: U6.14 (D5); also elsewhere on the board
/Sound/KD6: U6.17 (D6); also elsewhere on the board
/Sound/KD7: U6.18 (D7); also elsewhere on the board
/Sound/Noise1: C14.1; also elsewhere on the board
/Sound/S0: R1.2, U6.2 (O0), U7.15 (A)
/Sound/S1: C12.1, R2.2, U6.5 (O1), U7.1 (B), U9.4 (~CP1); also elsewhere on the board
/Sound/S2: R3.2, U6.6 (O2), U7.10 (C)
/Sound/S3: R4.2, U6.9 (O3), U7.9 (D)
/Sound/S4: R5.2, U6.12 (O4), U8.15 (A)
/Sound/S5: R6.2, U6.15 (O5), U8.1 (B)
/Sound/S6: R7.2, U6.16 (O6), U8.10 (C)
/Sound/S7: R8.2, U6.19 (O7), U8.9 (D)
/Sound/SOUND_EN: U6.11 (LE); also elsewhere on the board
GND: C12.2, C13.2, C15.2, R10.2, U6.1 (OE), U6.10 (GND), U7.8 (GND), U7.14 (CLR), U8.8 (GND), U8.14 (CLR), U9.2 (MR), U9.8 (GND), U9.12 (~CP1); also elsewhere on the board
unnamed: D9.1 (K), R1.1
unnamed: C14.2, D9.2 (A), D10.2 (A), D11.2 (A), D12.2 (A), D13.2 (A), D14.2 (A), D15.2 (A), D16.2 (A)
unnamed: D10.1 (K), R2.1
unnamed: D11.1 (K), R3.1
unnamed: D12.1 (K), R4.1
unnamed: D13.1 (K), R5.1
unnamed: D14.1 (K), R6.1
unnamed: D15.1 (K), R7.1
unnamed: D16.1 (K), R8.1
unnamed: U7.4 (DOWN), U9.3 (Q0)
unnamed: U7.13 (~BO), U8.4 (DOWN)
unnamed: U7.12 (~CO), U8.5 (UP)
unnamed: U7.11 (~LOAD), U8.11 (~LOAD), U8.13 (~BO), U9.15 (~CP0)
unnamed: U9.1 (~CP0), U9.7 (Q3)
unnamed: R9.2, U9.13 (Q0)

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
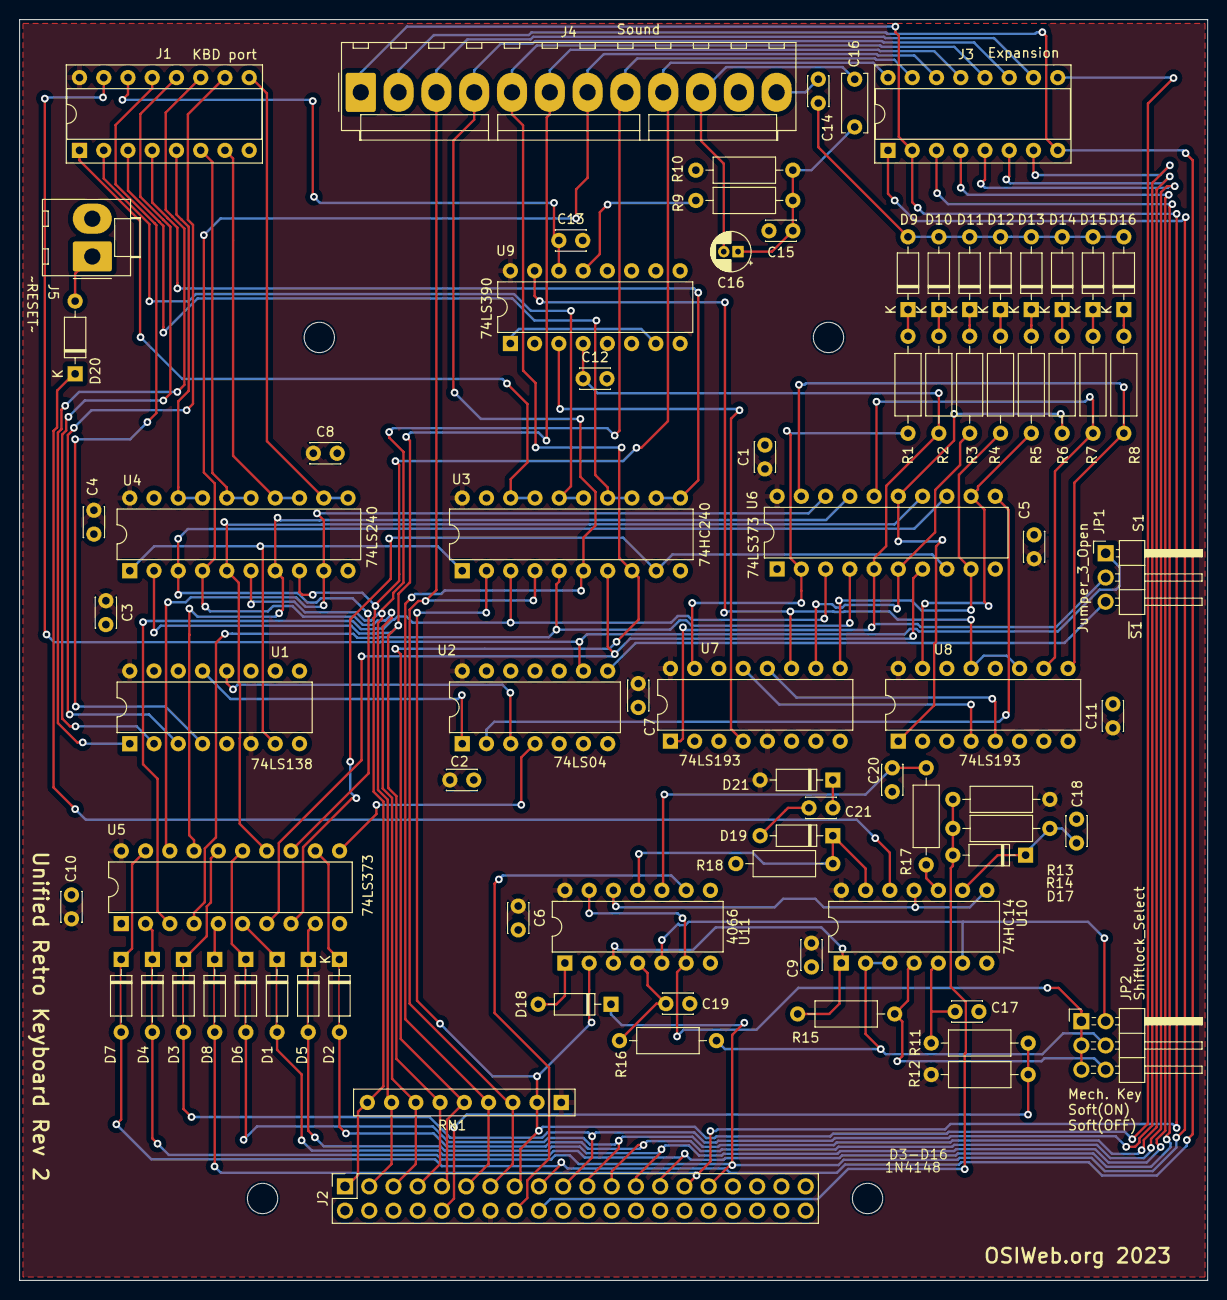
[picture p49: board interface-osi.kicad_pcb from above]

Board: 2 copper layers, 124.5 x 132.1 mm, 80 parts (0 on the bottom side), 100 nets.

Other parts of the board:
C16#2: 33 uF; CP_Radial_D4.0mm_P1.50mm

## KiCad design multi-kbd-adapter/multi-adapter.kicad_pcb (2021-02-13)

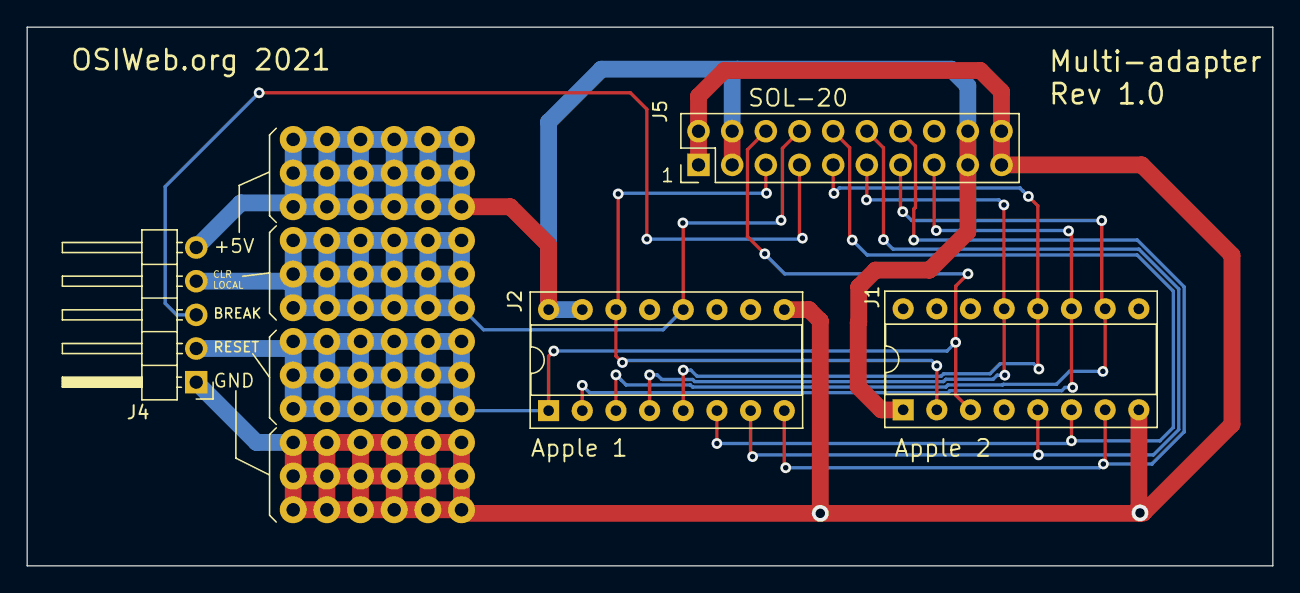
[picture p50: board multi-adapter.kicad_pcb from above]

Board: 2 copper layers, 94.0 x 40.6 mm, 4 parts (0 on the bottom side), 13 nets.

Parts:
J1: Apple 2; DIP-16_W7.62mm_Socket
J2: Apple 1; DIP-16_W7.62mm_Socket
J4: Outputs; PinHeader_1x05_P2.54mm_Horizontal
J5: SOL-20; SOL20-header-vertical

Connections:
/BREAK: J4.3, J5.4
/CLR-LOCAL: J2.12, J4.4, J5.14
/D0: J1.12, J2.5, J5.5
/D1: J1.13, J2.4, J5.6
/D2: J1.10, J2.3, J5.7
/D3: J1.11, J2.2, J5.8
/D4: J1.6, J2.6, J5.15
/D5: J1.5, J2.7, J5.16
/D6: J1.7, J2.8, J5.17
/~RESET: J1.3, J2.1, J4.2, J5.13
/~STROBE: J1.2, J2.14, J5.3
GND: J1.8, J2.9, J4.1, J5.1, J5.10, J5.11, J5.20
VCC: J1.1, J2.15, J2.16, J4.5, J5.2, J5.9, J5.12, J5.19

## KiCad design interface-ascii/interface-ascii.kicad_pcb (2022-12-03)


Board: 2 copper layers, 88.9 x 132.1 mm, 48 parts (0 on the bottom side), 81 nets.

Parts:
C1, C2, C3, C4, C5: 0.1 uF; C_Disc_D3.0mm_W1.6mm_P2.50mm
D1, D2, D3, D4, D5, D6, D7, D8, D9, D10, D11, D12, D13, D14, D15, D16: 1N4148; D_DO-35_SOD27_P7.62mm_Horizontal_bypassed
D17, D18, D19, D20, D21, D22, D23, D24, D25, D26, D27: 1N4148; D_DO-35_SOD27_P7.62mm_Horizontal
J1: Apple 2; DIP-16_W7.62mm_Socket
J2: Apple 1; DIP-16_W7.62mm_Socket
J3: UART; PinHeader_1x04_P2.54mm_Horizontal
J4: Outputs; PinHeader_1x05_P2.54mm_Horizontal
J5: ISP header; PinHeader_2x03_P2.54mm_Horizontal
J6: Keyboard; kbd_header_and_mounting_holes
J7: SOL-20; SOL20-header-vertical
R1, R3: 470; R_Axial_DIN0207_L6.3mm_D2.5mm_P10.16mm_Horizontal
RN1: 4.7k; R_Array_SIP9
SW1: Options; SW_DIP_SPSTx08_oriented_backward
U1: ATmega328P; DIP-28_W7.62mm
U2: 74LS166; DIP-16_W7.62mm
U3, U4: 74LS138; DIP-16_W7.62mm
U5: 74LS04; DIP-14_W7.62mm

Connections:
+5V: C1.1, C2.1, C3.1, C4.1, C5.1, J1.1, J2.15, J2.16, J3.1, J4.5, J5.2, J6.6, J6.14, J6.22, J7.2, J7.9, J7.12, J7.19, RN1.1 (common), U1.7 (VCC), U1.20 (AVCC), U1.21 (AREF), U2.1 (Ds), U2.9 (Clr), U2.16 (VCC), U3.6 (E3), U3.16 (VCC), U4.16 (VCC), U5.14 (VCC)
/Col0: D17.2 (A), J6.2, J6.10, J6.15, J6.18, RN1.2 (R1), U2.14 (D0)
/Col1: D21.2 (A), J6.13, RN1.3 (R2), U2.12 (D1)
/Col2: D18.2 (A), J6.11, RN1.4 (R3), U2.11 (D2)
/Col3: D22.2 (A), J6.9, RN1.5 (R4), U2.10 (D3)
/Col4: D19.2 (A), J6.7, RN1.6 (R5), U2.5 (D4)
/Col5: D23.2 (A), J6.5, RN1.7 (R6), U2.4 (D5)
/Col6: D20.2 (A), J6.3, RN1.8 (R7), U2.3 (D6)
/Col7: D24.2 (A), J6.1, RN1.9 (R8), U2.2 (D7)
/D0: J1.12, J2.5, J7.5, R3.1, U1.2 (PD0)
/D1: J1.13, J2.4, J7.6, R1.1, U1.3 (PD1)
/D2: J1.10, J2.3, J7.7, U1.4 (PD2)
/D3: J1.11, J2.2, J7.8, U1.5 (PD3)
/D4: J1.6, J2.6, J7.15, U1.6 (PD4)
/D5: J1.5, J2.7, J7.16, U1.11 (PD5)
/D6: J1.7, J2.8, J7.17, U1.12 (PD6)
/D7: J7.18, U1.13 (PD7)
/LED1: J6.8, U1.27 (PC4)
/MISO-LED3: J5.1, U1.18 (MISO/PB4), U5.1
/MOSI-OUT2: J5.4, U1.17 (MOSI), U5.13
/OUT1: J2.12, J4.4, J7.14, U1.28 (PC5)
/OUT2: J4.3, J7.4, U5.12
/OUT3: J1.3, J2.1, J4.2, J7.13, U1.10 (PB7)
/Row0: D9.2 (A), D25.1 (K), J6.31
/Row1: D12.2 (A), D27.1 (K), J6.29
/Row2: D10.2 (A), J6.27
/Row3: D3.2 (A), J6.25
/Row4: D11.2 (A), J6.23
/Row5: D2.2 (A), J6.21
/Row6: D1.2 (A), J6.19
/Row7: D4.2 (A), D26.1 (K), J6.17
/Row8: D13.2 (A), J6.34, SW1.1, SW1.2, SW1.3, SW1.4, SW1.5, SW1.6, SW1.7, SW1.8
/Row9: D5.2 (A), J6.36
/Row10: D14.2 (A), J6.38
/Row11: D6.2 (A), J6.40
/Row12: D15.2 (A), J6.39
/Row13: D7.2 (A), J6.37
/Row14: D16.2 (A), J6.35
/Row15: D8.2 (A), J6.33
/Rx: J3.3, R3.2
/SCK-LED2: J5.3, U1.19 (SCK/PB5), U5.3
/Tx: J3.2, R1.2
/~RESET: J5.5, U1.1 (~RESET)
/~STROBE: J1.2, J2.14, J7.3, U1.9 (PB6)
GND: C1.2, C2.2, C3.2, C4.2, C5.2, J1.8, J2.9, J3.4, J4.1, J5.6, J7.1, J7.10, J7.11, J7.20, U1.8 (GND), U1.22 (GND), U2.6 (CK_INH), U2.8 (GND), U3.4 (E1), U3.8 (GND), U4.4 (E1), U4.5 (E2), U4.8 (GND), U5.5, U5.7 (GND), U5.9, U5.11
unnamed: D1.1 (K), U3.9 (O6)
unnamed: D2.1 (K), U3.10 (O5)
unnamed: D3.1 (K), U3.12 (O3)
unnamed: D4.1 (K), U3.7 (O7)
unnamed: D5.1 (K), U4.14 (O1)
unnamed: D6.1 (K), U4.12 (O3)
unnamed: D7.1 (K), U4.10 (O5)
unnamed: D8.1 (K), U4.7 (O7)
unnamed: D9.1 (K), U3.15 (O0)
unnamed: D10.1 (K), U3.13 (O2)
unnamed: D11.1 (K), U3.11 (O4)
unnamed: D12.1 (K), U3.14 (O1)
unnamed: D13.1 (K), U4.15 (O0)
unnamed: D14.1 (K), U4.13 (O2)
unnamed: D15.1 (K), U4.11 (O4)
unnamed: D16.1 (K), U4.9 (O6)
unnamed: D17.1 (K), SW1.16
unnamed: D18.1 (K), SW1.14
unnamed: D19.1 (K), SW1.12
unnamed: D20.1 (K), SW1.10
unnamed: D21.1 (K), SW1.15
unnamed: D22.1 (K), SW1.13
unnamed: D23.1 (K), SW1.11
unnamed: D24.1 (K), SW1.9
unnamed: D25.2 (A), J6.4
unnamed: D26.2 (A), J6.12
unnamed: D27.2 (A), J6.20
unnamed: J6.16, U5.4
unnamed: J6.24, U5.2
unnamed: U1.14 (PB0), U2.13 (Qh)
unnamed: U1.15 (PB1), U2.15 (SH_~LD)
unnamed: U1.16 (PB2), U2.7 (CLK)
unnamed: U1.23 (PC0), U3.1 (A0), U4.1 (A0)
unnamed: U1.24 (PC1), U3.2 (A1), U4.2 (A1)
unnamed: U1.25 (PC2), U3.3 (A2), U4.3 (A2)
unnamed: U1.26 (PC3), U3.5 (E2), U4.6 (E3)

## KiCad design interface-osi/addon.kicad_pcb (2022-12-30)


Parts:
C1, C5: 0.33uF; C_Disc_D6.0mm_W2.5mm_P5.00mm
C2: 6.8uF; C_Disc_D6.0mm_W2.5mm_P5.00mm
C3, C4, C6: 0.1uF; C_Disc_D6.0mm_W2.5mm_P5.00mm
D1, D3, D4, D5: 1N914; D_DO-35_SOD27_P7.62mm_Horizontal
J1: Conn_01x13_Male; PinHeader_1x13_P2.54mm_Vertical
JP1: ShiftLock_Select; PinHeader_2x03_P2.54mm_Vertical
R1, R3, R7: 1k; R_Axial_DIN0207_L6.3mm_D2.5mm_P10.16mm_Horizontal
R2, R6: 100k; R_Axial_DIN0207_L6.3mm_D2.5mm_P10.16mm_Horizontal
R4: 1M; R_Axial_DIN0207_L6.3mm_D2.5mm_P10.16mm_Horizontal
R5: 10k; R_Axial_DIN0207_L6.3mm_D2.5mm_P10.16mm_Horizontal
R8: 1K; R_Axial_DIN0207_L6.3mm_D2.5mm_P10.16mm_Horizontal
U1: 4066; DIP-14_W7.62mm
U2: 74HC14; DIP-14_W7.62mm

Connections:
/Break1: D1.2 (A), J1.3, R3.2, R4.1
/ShiftLock1: J1.6, R1.2, R2.1
Col0: J1.10, U1.10
GND: C1.1, C2.2, C3.1, C4.2, C6.1, J1.2, J1.4, J1.7, J1.12, R8.1, U1.7 (VSS), U1.8, U2.7 (GND)
unnamed: C1.2, R2.2, U2.13
unnamed: C2.1, D1.1 (K), R4.2, U2.3
unnamed: C3.2, R6.1, U1.4
unnamed: C4.1, R7.1, U1.2
unnamed: C5.1, D5.1 (K)
unnamed: C5.2, D3.2 (A)
unnamed: D3.1 (K), R8.2, U1.1, U2.1
unnamed: D4.1 (K), U2.2
unnamed: JP1.1, R5.2, U2.8
unnamed: JP1.2, JP1.4, JP1.6, U1.6, U1.12
unnamed: JP1.3, R6.2, U2.9, U2.10
unnamed: JP1.5, U1.5, U2.12
unnamed: R5.1, U1.3, U2.11
unnamed: R7.2, U2.6
unnamed: U1.13, U2.4, U2.5
Row0: J1.11, U1.11
ShifLockLED+: C6.2, D5.2 (A), J1.1, J1.8, J1.13, R1.1, R3.1, U1.14 (VDD), U2.14 (VCC)
ShiftLockLED-: J1.9, U1.9
~RESET: D4.2 (A), J1.5

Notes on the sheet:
Mechanical
Soft Initital OFF
Break2
Reset Delay time: about 3.3 sec Reset delay is approx. proportional to 5 sec/uF * C1 value
Debounce Time approx 40 msec
~{RESET} pulse is approx 50 usec.
Soft Initial ON
ShiftLock2


Board: 2 copper layers, 43.2 x 60.5 mm, 22 parts (0 on the bottom side), 23 nets.

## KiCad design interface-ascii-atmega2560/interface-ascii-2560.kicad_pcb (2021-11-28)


Board: 2 copper layers, 88.9 x 132.1 mm, 49 parts (0 on the bottom side), 80 nets.

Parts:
C1, C2: 36pf; C_Disc_D3.0mm_W1.6mm_P2.50mm
C3, C4, C5, C6: 0.1 uF; C_Disc_D3.0mm_W1.6mm_P2.50mm
D1, D2, D3, D4, D5, D6, D7, D8, D9, D10, D11, D12, D13, D14, D15, D16: 1N4148; D_DO-35_SOD27_P7.62mm_Horizontal_bypassed
D17, D18, D19, D20, D21, D22, D23, D24, D25, D26, D27: 1N4148; D_DO-35_SOD27_P7.62mm_Horizontal
J1: Apple 2; DIP-16_W7.62mm_Socket
J2: Apple 1; DIP-16_W7.62mm_Socket
J3: UART; PinHeader_1x04_P2.54mm_Horizontal
J4: Conn_01x05; PinHeader_1x05_P2.54mm_Horizontal
J5: SOL-20; SOL20-header-vertical
J6: Conn_01x16; PinHeader_2x08_P2.54mm_Horizontal
J7: Custom Connector 1 / Proto; DIP-16_W7.62mm_Proto
J8: Custom Connector 2; ExpansionHeader_1x25_P2.54
J10: Keyboard; kbd_header_and_mounting_holes
MH1, MH2: Apple II; MountingHole_3.7mm
R1: 10k; R_Axial_DIN0207_L6.3mm_D2.5mm_P10.16mm_Horizontal
RN1: 4.7k; R_Array_SIP9
SW1: Options; SW_DIP_SPSTx08_Piano_CTS_Series194-8MSTN_W7.62mm_P2.54mm
U1: ATmega2560-16AU; TQFP-100_14x14mm_P0.5mm
Y1: 16.000 MHz; Crystal_SMD_HC49-SD_HandSoldering

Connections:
/Col0: D20.2, J10.2, J10.10, J10.15, J10.18, RN1.2, U1.53
/Col1: D24.2, J10.13, RN1.3, U1.54
/Col2: D21.2, J10.11, RN1.4, U1.55
/Col3: D25.2, J10.9, RN1.5, U1.56
/Col4: D22.2, J10.7, RN1.6, U1.57
/Col5: D26.2, J10.5, RN1.7, U1.58
/Col6: D23.2, J10.3, RN1.8, U1.59
/Col7: D27.2, J10.1, RN1.9, U1.60
/D0: J1.12, J2.5, J5.5, U1.12
/D1: J1.13, J2.4, J5.6, U1.13
/D2: J1.10, J2.3, J5.7, U1.14
/D3: J1.11, J2.2, J5.8, U1.15
/D4: J1.6, J2.6, J5.15, U1.16
/D5: J1.5, J2.7, J5.16, U1.17
/D6: J1.7, J2.8, J5.17, U1.18
/D7: J5.18, U1.27
/LED1: J10.8, U1.48
/LED2: J10.16, U1.49
/LED3: J10.24, U1.50
/MISO: J6.11, U1.22
/MOSI: J6.14, U1.21
/OUT1: J2.12, J4.4, J5.14, U1.24
/OUT2: J4.3, J5.4, U1.25
/OUT3: J1.3, J2.1, J4.2, J5.13, U1.26
/Row0: D9.2, D17.1, J10.31
/Row1: D1.2, D19.1, J10.29
/Row2: D10.2, J10.27
/Row3: D2.2, J10.25
/Row4: D11.2, J10.23
/Row5: D3.2, J10.21
/Row6: D12.2, J10.19
/Row7: D4.2, D18.1, J10.17
/Row8: D13.2, J10.34, SW1.1, SW1.2, SW1.3, SW1.4, SW1.5, SW1.6, SW1.7, SW1.8
/Row9: D5.2, J10.36
/Row10: D14.2, J10.38
/Row11: D6.2, J10.40
/Row12: D15.2, J10.39
/Row13: D7.2, J10.37
/Row14: D16.2, J10.35
/Row15: D8.2, J10.33
/Rx: J3.3, U1.2
/SCK: J6.13, U1.20
/TCK: J6.1, U1.93
/TDI: J6.9, U1.90
/TDO: J6.3, U1.91
/TMS: J6.5, U1.92
/Tx: J3.2, U1.3
/~RESET: J6.6, J6.15, R1.2, U1.30
/~STROBE: J1.2, J2.14, J5.3, U1.23
GND: C1.2, C2.2, C3.2, C4.2, C5.2, C6.2, J1.8, J2.9, J3.4, J4.1, J5.1, J5.10, J5.11, J5.20, J6.2, J6.10, J6.16, U1.11, U1.32, U1.62, U1.81, U1.99
unnamed: C1.1, U1.34, Y1.2
unnamed: C2.1, U1.33, Y1.1
unnamed: D1.1, U1.64
unnamed: D2.1, U1.66
unnamed: D3.1, U1.68
unnamed: D4.1, U1.79
unnamed: D5.1, U1.77
unnamed: D6.1, U1.75
unnamed: D7.1, U1.73
unnamed: D8.1, U1.71
unnamed: D9.1, U1.63
unnamed: D10.1, U1.65
unnamed: D11.1, U1.67
unnamed: D12.1, U1.69
unnamed: D13.1, U1.78
unnamed: D14.1, U1.76
unnamed: D15.1, U1.74
unnamed: D16.1, U1.72
unnamed: D17.2, J10.4
unnamed: D18.2, J10.12
unnamed: D19.2, J10.20
unnamed: D20.1, SW1.16
unnamed: D21.1, SW1.14
unnamed: D22.1, SW1.12
unnamed: D23.1, SW1.10
unnamed: D24.1, SW1.15
unnamed: D25.1, SW1.13
unnamed: D26.1, SW1.11
unnamed: D27.1, SW1.9
VCC: C3.1, C4.1, C5.1, C6.1, J1.1, J2.15, J2.16, J3.1, J4.5, J5.2, J5.9, J5.12, J5.19, J6.4, J6.12, J10.6, J10.14, J10.22, R1.1, RN1.1, U1.10, U1.31, U1.61, U1.80, U1.100

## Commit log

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2019-12-15 Added screen clear and reset functions
    - added asdf_actions.c, asdf_actions.h to place misc. key actions
    - asdf.c: asdf_activate_action(): added actions for screen clear and reset
    - asdf_config.h, Arch/asdf_arch_atmega328p.c: added defs to specify polarity of data,
    strobe, SCREEN_CLEAR and reset outputs.
    - Arch/asdf_arch_atmega328p.h: fixed pin definitions for RESET and SCREEN_CLEAR
2019-12-24 ASCII keyboard fixes
    Keymaps/asdf_keymaps.h: swap '0' and 'O' codes to compensate for physically swapped '0' and 'O' in early prototypes
    asdf_ascii.h: fix wrong code for comma (44, 0x2C; was defined as 0x44).
2019-12-24 Comment fix
    Fix the comment in the "Swapped O and zero" keymap to indicate board rev that
    pairs with the keymap.
2019-12-24 Swap "O" (Cap O) and "0" (zero) keys
    The "0" and "O" keys were swapped on the PCB, requiring a keymap fix for the
    ASCII adapter. The swapped keys would not be an issue for a keyscanning ASCII
    converter, but would preclude use in OSI systems, so this fix puts the keys
    back in position compatible with OSI.
    [kbd-classic.kicad_pcb, kbd-classic.sch]
2019-12-25 Break out keymap definitions
    - Separate the "asdf_keymaps.h" files into
    -- "asdf_keymaps.h" which is not keymap dependent and contains keymap function
    prototypes
    -- "asdf_keymap_defs.h" which contains the keymap definitions
    -- Move definitions of number of rows and columns from asdf.h to keymaps_defs.h.
    -- keymap_defs.h is copied from the keymaps directory depending on which keymap
    is specified in the Makefile.
    -- Makefile fixes for the above changes
    -- Fix includes in several files to reflect the above changes.
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2019-12-27 Keyboard interface cleanups for ASCII controller
    Fixed lines for POWER LED and button, SHIFT Lock, Rubout, and CAPS LED.
    [interface-ascii.kicad_pcb, interface-ascii.sch]
2019-12-28 I/O cleanup and SYS_RESET fix
    - Break out initialization of SYS_RESET, CLEAR, STROBE, and CAPS LED into
    separate functions.
    - Emulate open collector output for SYS_RESET: OFF=input with weak pullup.
    ON=output low.
    - Add function to cap CAPS LED.
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2020-01-03 ASCII interface update
    - Fix wrong direction DIP switch diodes
    - Add buffers to permit ISP lines to also be used as output and LED drivers
    - Allow 3 keyboard LEDs and 3 host outputs (RESET, CLEAR, BREAK, LOCAL, etc.).
    - Outputs 1 and 3 are general purpose (can be open drain or driven). Output 2
    is open collector (with optional on-board pullup).
    [interface-ascii.kicad_pcb, interface-ascii.sch]
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2020-01-04 Trace fixes
    - removed extraneous unconnected traces
    - straightened an off-angle trace that was violating clearance.
    [kbd-classic.kicad_pcb]
2020-01-20 Keyboard layout updates
    - Add extra key to the left side of row 4 to permit "inverted T" for those who
    want it.
    - Tiny shifts of several keys to correct key distances
    - Include mounting holes with daughter board connector, to ensure consistency.
    [aligner-cherry.kicad_pcb, aligner-futaba.kicad_pcb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]
2020-01-28 Fix wrong apple-II mount dimensions
    - pulled in the right border and mounting holes for Apple-II mounting dimensions
    - modified the "~^" key courtyard to allow closer positioning of the upper right
    Apple II Mounting hole. (The ~^ key is not installed in an Apple II keyboard)
    - Moved tracks and diodes as needed to keep everything in the new outline.
    [kbd-classic.kicad_pcb]
2020-01-28 Aditional outline fix for Apple II
    [kbd-classic.kicad_pcb]
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2020-01-30 Fixed details of keycap sets
    - SOL-20: Specify SA profile, row 3
    - classic: Specify SA profile, row 3 (incorrectly specified DSA)
    - classic: add 8u spacebar. whoops.
    [sol-20-keycaps.xlsx]
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2020-02-16 OUT3 is /RESET on Apple1 and Apple2 connectors.
    OUT3 is RESET on both Apple 1 and Apple 2 connectors
    Fix comment on the OUT1, OUT2, and OUT3 functions.
    [interface-ascii.sch]
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2020-02-20 ASCII Keymap fixes
    Updated keymap definitions to fit current keyboard matrix PCB rev (1.3).
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2020-02-28 PCB cleanups
    - swap numbering of row select protection diodes for cleaner PCB labeling
    - clarify labeling on GPIO pins on the MCU
    - bump rev to 2.4 to indicate work in progress. Release will be 2.5.
    [interface-ascii.kicad_pcb, interface-ascii.sch]
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2020-03-08 Add virtual output device module (compiles without warning)
    * Created test fixture for virtual outputs
    * Added virtual output configuration to keymap definitions removed special
    actions_send_reset() and actions_send_screenclear() functions, and replaced with
    virtual output definitions.
    * asdf_actions.c is removed from build.
    * asdf_arch_atmega328p.c: added functions to set/clear each real output
    * asdf_arch_atmega328p.c: added pulse_delay() function
    * asdf_arch_test.c: added mock machinery to emulate outputs, test output
    settings, and detect properly and improperly-formed pulses on the outputs.
    * asdf_keymaps.c: allocate initialzer array. asdf_keymaps_select_keymap() calls
    asdf_virtual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
2020-03-11 Apple 2 map fixes
    Set the lamp under the caps lock key (next to RETURN, not in apple2 layout) to
    off.
    Remove the right square bracket "]" from the apple 2 map.
2020-03-13 Improved comments
    - Added physical PCB key mapping for reference
    - Make sure CAPSLOCK LED doesn't toggle in the ALL CAPS keymaps.
2020-03-14 Modifiers cleanup
    - asdf_modifiers.[ch]: Replace asdf_modifier_shiftlock_activate() with
    asdf_modifier_shiftlock_on_activate() and
    asdf_modifier_shiftlock_toggle_activate(). Instead of a configurateion
    setting for shiftlock state to switch between SHIFTLOCK locks on, SHIFT turns
    off, vs SHIFTLOCK toggles, and SHIFT turns off, create two different
    SHIFTLOCK functions, one for each behavior, and allow the keymap to bind the
    desired function.
    - asdf.h: replace ACTION_SHIFTLOCK with ACTION_SHIFTLOCK_ON and
    ACTION_SHIFTLOCK_TOGGLE.
    - asdf.h: move start of ACTION codes from 0x80 to 0x90, since SOL-20 uses codes
    from 0x80-0x8f.
    - asdf.c: test for ACTION code using (code > ASDF_A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
2020-03-16 Add support for "hi-z when low" outputs
    The apple 1 CLEAR input requires a high-impedance inactive state to avoid
    conflict with the pin output of the 7404 at D12 (via CR4). So, to cover this
    condition most generally, this patch changes the adds a Hi-Z when low physical
    device for each output line, to complement the Hi-Z-when-high open collector
    emulation. The nomenclature is changed from OUT*_OC (emulated open collector) to
    OUT*_OPEN_HI and OUT*_OPEN_LO to indicate which condition gets the Hi-Z state.
    - added the set() functions to the asdf_arch_atmega328p.[ch] files and applied
    the above nomenclature.
    - Added the set() functions to the asdf_physical.[ch] files and applied the
    above nomenc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
2020-03-16 SOL keyboard adjustments
    - Fixed position offset error in first three rows of the SOL keyboard
    - moved key matrix interface connector to bottom of board so the parallel output
    connector can be at the top of the keyboard.
    - Adjusted size of mounting slots to accommodate #6 screws.
    - ongoing clean up of traces.
    [kbd-sol.kicad_pcb, kbd-sol.sch, keys3.sch]
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2020-03-16 Add a header-and-mounting-holes footprint with fewer mounting holes
    The SOL-20 keyboard doesn't have space for mounting holes right next to the
    matrix header, so the new footprint eliminates those mounting holes.
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2020-03-18 Replace wrong cherry aligner file.
    [sol-aligner-cherry.kicad_pcb]
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2020-03-21 Put correct DIP switch row in sol keycap definitions for rev 2.3 interface
2020-03-23 Swapped text in futaba "main" aligner
    [aligner-futaba-main.kicad_pcb]
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2020-04-06 Move LED current limit resistors to keyboard PCB
    For better matching of current limit resistors to LEDs, the resistors are moved
    to the keyboard matrix PCB, where they can be tuned for maximum brightness (at
    100% duty cycle). This allows consistent keyboard brightness when a single
    interface PCB is swapped between keyboard matrices.
    [interface-ascii.kicad_pcb, interface-ascii.sch, kbd-classic.kicad_pcb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]
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2020-04-21 Add OSI interface schematic
    Provides a keyboard interface to interface with OSI computers. Equivalent to an
    OSI 542C.
    - Includes sound circuits
    - Includes RESET delay circuit
    - SHIFT LOCK can be mechanical push-on/push-off or soft toggle, selectable by
    jumper.
    - Provide SHIFT LOCK LED output.
    [Sound.sch, interface-osi.sch, special_keys.sch]
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2020-04-23 Circuit tweaks
    - Add power-on reset to reset circuit
    - Modify Shiftlock circuit to require only one jumper
    [Sound.sch, interface-osi.sch, special_keys.sch]
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2020-04-27 Fix unconnected wire to decoder for rows 8-15
    [interface-ascii.kicad_pcb, interface-ascii.sch]
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2020-05-06 ERC/DRC fixes
    - Removed diodes from pinout page; these were for illustrative purposes only
    - Added No-Connects on unused row signals.
    [Pinouts.sch]
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2020-05-12 Fix descriptive comment for keyboard connectors
    [interface-ascii.sch]
2020-05-12 ATMega2560 PCB fixes and updates
    - add additional key matrix connector (for custom matrix including Apple 2)
    - Fix bypassed diodes. Diodes on rows 8-15 should have been
    - jumpered (bypassed), but instead were standard diode footprints.
    [Pinouts.sch, interface-ascii-2560.kicad_pcb, interface-ascii-2560.sch]
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2020-05-15 Add DIP switch select for strobe polarity and autorepeat
    - arch-* files: replace private arch_strobe_init() function with public
    arch_set_neg_strobe() and arch_set_pos_strobe() functions
    - asdf.c,h: add ACTION hooks to set strobe polarity and enable/disable
    autorepeat
    - break out DIP switch definitions into a separate header file, included by each
    keymap. This ensures consistent DIP switch behavior across keymaps.
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2020-05-21 Adjustments for OSI RESET and shiftlock circuits
    - adjust RC constants to use simple, common values and reduce number of
    different part values.
    - Create add-on PCB to provide reset/shiftlock function for older 542 and SB2
    keyboards.
    [addon.kicad_pcb, addon.sch, interface-osi.sch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]
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2020-05-21 Add mounting holes for PCB along right side of keyboard
    - moving interface PCB to right side eliminates clearance issues.
    [kbd-sol.kicad_pcb]
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2020-05-21 Fix comment in addon.sch
    [addon.sch]
2020-05-27 Completed routing on OSI interface board
    Cleaned up and fixed schematics
    [Sound.sch, addon.sch, interface-osi.sch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]
2020-05-28 Update addon board updates
    - Add diode to C5 to prevent discharge into 5V
    - allow selection of default ON or OFF soft switch.
    [addon.kicad_pcb, addon.sch]
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2020-06-03 Fixed Keyboard encoder connector
    - remove unused "jumper holes"
    - align pins with spacer holes.
    [apple-encoder.kicad_pcb, apple-encoder.sch]
2020-06-03 Various PCB cleanup
    - Fix position of holes around 1x25 connector to match Apple 2 keyboard
    - silk screen fixes
    - minor trace shoves.
    [interface-ascii-2560.kicad_pcb, interface-ascii-2560.sch]
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2020-06-03 Fix connector J8 name to "custom connector 2"
    [interface-ascii-2560.kicad_pcb, interface-ascii-2560.sch]
2020-06-06 Corrections to Sol-20 keycap BOM
    - Add the _/DEL key
    - Specify that the keypad "." key be centered vertically and horizontally.
    [sol-20-keycaps.xlsx]
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2020-06-17 Update Sol keyboard to 1.5 (Minor changes)
    - Fix title in Schematic
    - Slightly enlarge center post hole on switch footprint, to allow a bit of
    tolerance. Very tight tolerance makes the keyboards hard to assemble.
    [kbd-sol.kicad_pcb, kbd-sol.sch]
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2020-06-17 Multiple fixes to classic keyboard for fit and build ease
    - remove material from PCB to allow keyboard to fit in Apple II case
    - enlarge center hole on cherry MX footprints slightly, to 0.160" to allow
    slightly more tolerance, which eases assembly.
    - include holes for LEDs on futaba aligner
    - include extra pads on main PCB for LEDs with futaba keys
    - Add LED on LINE FEED which maps to REPEAT/CAPSLOCK on Apple II keymap
    [aligner-cherry.kicad_pcb, aligner-futaba.kicad_pcb, kbd-classic.kicad_pcb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]
2020-06-19 Fixes for classic keyboard outline and mounting hole patters
    - Adjust upper right corner circular cutout for AppleII+ case fit.
    - Adjust OSI mounting hole pattern for improved fit.
    - Changed OSI mount holes along top of keyboard to slots, to fit both C2P (542
    keyboard) and C4P (542 Rev B/c keyboards).
    - PCB and aligners must be slightly taller to accommodate the slots along the
    top row
    [aligner-cherry.kicad_pcb, aligner-futaba.kicad_pcb, kbd-classic.kicad_pcb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]
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2020-06-23 mechanical fit and buildability fixes
    - Moved header slightly forward
    - Moved interface mount holes do reduce interference with case mount holes
    - For all keys in classic keyboard, add option for either through-hole or SMT
    diodes and resistors.
    [Sound.sch, aligner-cherry.kicad_pcb, aligner-futaba.kicad_pcb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]
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2020-06-29 Replaced standard 20-pin header with header+mounting holes
    [aligner-cherry.kicad_pcb]
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2020-07-03 tweaks for Cherry MX stabilizer posts on Futaba aligners
    - Slightly narrower posts.
    - slightly smaller hole, closer to end
    - added mouse bites for breakaway to avoid protruding breakaway
    - Applied to Sol and Classic
    [aligner-futaba.kicad_pcb]
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2020-07-09 Fixed futaba posts on SOl-20 futaba aligner
    [aligner-futaba.kicad_pcb]
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2020-07-20 BUGFIX: repeat apparatus not initiazized on keymap switch.
    Added call to asdf_repeat_init() form asdf_keymaps_select_keymap()
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2020-08-01 Multiple fixes for keyboard PCB
    - in combined CherryMX/futaba footprints, moved cherry pads down 1 mil and
    futaba pads up 2 mil, to reduce risk of shortin of LED pads with futaba pad.
    Adjusted all aligners accordingly
    - Fixed centroid for combined diode footprint and adjusted PCB placement on
    classic and SOL keyboards accordingly.
    - Moved SMT pads in combined diode footprint to top layer, so pick & place file
    will be usable.
    - changes to futaba stabilizer design. Longer post adapter passes through slots
    in keyboard and aligner.
    - Changed futaba post thickness gauge from board outline to a slot to improve
    tolerance.
    - Moved spacebar stabilizer bending guide to edge of PCB, in order to m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
    [aligner-cherry.kicad_pcb, aligner-futaba.kicad_pcb, kbd-classic.kicad_pcb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]
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2020-08-06 Apply fixes to cherry aligner.
    [aligner-cherry.kicad_pcb]
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2020-08-17 Update footprints to add soldermask clearance around Cherry MX posts
    [kbd-classic.kicad_pcb]
2020-08-17 Update Sol-20 keyboard to use fixed footprints
    - Update all footprints on sol-20 keyboard and aligners
    - Add soldermask clearance around cherry MX posts
    - Move Cherry MX pads down 1 mil, and Futaba pads up 2 mils
    - Adjust Cherry aligner footprints down 1 mil
    - Adjust Futaba aligner footprints up 2 mils
    - Move mounting slots up 1 mil on Cherry aligner
    - Move mounting slots down 1 mil on Futaba aligner
    - incorporate improved stabilizer post adapters in futaba aligner
    - add slots for stabilizer posts in futaba aligner and Sol kebyoard PCB
    - Move stabilizer bar bend guide to left bottom edge to facilitate bending
    - Bump rev to 1.6
    [aligner-cherry.kicad_pcb, aligner-futaba.kicad_pcb, kbd-sol.kicad_pcb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]
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2020-09-22 Fixed LED orientation on PCB
    - CapsLock, Line Feed LEDs and D33 were wired correctly, but oriented backwards
    on PCB relative to Power and OSI ShiftLock LEDs. Fixed so Cathode is always on
    the right.
    - Marked Anode for all LEDs with (+) symbol.
    [kbd-classic.kicad_pcb]
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2020-09-22 Fix LED orientation
    [kbd-classic.kicad_pcb, kbd-classic.sch]
2020-12-29 Modify to use DIP switch or jumpers
    - Add combined DIP-switch/Jumper footprint to footprint library
    - Fix Apple2-encoder and interface-ascii-atmega2560 schematics and PCB to use
    new footprint.
    [apple-encoder.kicad_pcb, apple-encoder.sch, interface-ascii-2560.kicad_pcb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]
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2021-02-01 Sol-20 spacebar stabilizer fix and other cleanups
    - Replaced standard MX footprint with spacebar footprint, including stabilizers
    - Fixed courtyard on MX footprints in library to avoid collisions
    - Added a DIP switch variant with header position closer to pin 1
    - moved option DIP switch/header to align header better with edge of PCB.
    [encoder-smt.sch, kbd-sol.kicad_pcb, kbd-sol.sch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]
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2021-03-05 Get keymap tests to pass (issues [#23] and [#25])
    Clean compile of asdf_keymaps.c/h and tests
    Clean up keymap pointer notation
    Reduce number of keymaps to 16, matching number of DIP switches allocated for
    keymap selection.
2021-03-05 Get virtual devices in new maps scheme to pass tests
    Remove initialization from data structure.
    Replace the previous virtual_init() with a virtual_init() that initializes the
    data structures to a default state
    Create virtual_sync() function to push the state of virtual devices to the
    physical outputs. Moved from the previous virtual_init() function.
    The virtual device table is now built by direct calls to virtual_add() from the
    setup function.
    Toward issue [#23]
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2021-08-08 Fix shunted diode footprints on encoder boards
    The encoder boards (ATmega328P, Atmega2560, Apple2(2560) can accomodate
    keyboard matrices with no diodes, by adding per-row diodes on the
    encoder board. For keyboards with per-key diodes (the typical use
    case), the per-row diodes are not needed, and therefore the footprints
    should be shunted by default, using a special shunted diode footprint.
    When diodes are installed, the shunt can be cut with an x-acto knife.
    Previous board revs had the correct footprint, but somehow the regular
    diode footprint was substituted on the last release of each of these
    PCBS. The correct footprint has been restored.
    [apple-encoder.kicad_pcb, apple-encoder.sch, interface-ascii-2560.kicad_pcb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]
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2021-09-22 Clean up keymap init routine
    - replace asdf_keymaps_clear() with asdf_keymaps_reset() which does the
    clear, and also resets hooks and virtual devices for the keymap
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2021-11-09 BUGFIX: 328P OUT2 output was changing OUT1
    This appears to have been a cut-paste typo in the asdf_arch_out2_set() function
    in asdf_arch_atmega328p.c. The port was set to OUT2, but the bit was OUT1.
2021-11-15 Fix name and date
    [classic-ascii-keycaps.xlsx]
2021-11-24 Move tracks in classic kbd to avoid mounting holes
    [kbd-classic.kicad_pcb, kbd-classic.sch, keys1.sch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]
2021-11-28 Fix library-related indirection bug
    Accessing library functions via function pointer seems to cause a reset.
    Still investigating the cause.
    - compile keymaps subdir as part of main src cmakefile, rather than as a
    separate library.
    - rather than setup table of function pointers and using an indirection
    in the main code, set up a jump table (switch). This is cleaner.
2021-11-29 Add apple 2 caps, printing, bug fixes
    - Added the apple 2 CAPS map
    - auto-generate a function to check validity of a keymap index
    - Added buffered message printing. This is different from keycode
    buffering, since an extra delay is added for each message character to
    allow polling hosts to keep up. Keycodes are generated at human speeds
    and need no further slowdown.
    - Added a message character delay to the arch-* modules
    - enlarged the buffer pool, and created a buffer for messages
    - bumped version number
2021-11-29 Typo fixes to classic keycap spreadsheet
    [classic-ascii-keycaps.xlsx]
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2021-12-05 Breakout keyboard init
    factor out common code and add back wrappers, so keyboard initializes to
    default keyboard on power up, and afterwards, won't reinitialize the
    keyboard unless the map changes.
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2021-12-11 make sure all tests pass
    - added keymap_setup() function to keymap tests
    - The test string was not long enough to overflow the larger buffer.
    Switched to use pseudo-random sequence intstead of a fixe test string.
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2022-02-22 OSI reset/shiftlock addon- add mounting holes
    [addon.kicad_pcb, addon.kicad_sch]
2022-02-22 Clean up DRC errors
    [addon.kicad_pcb]
2022-04-07 Cleanup RESET+SHIFTLOCK addon
    - replaced DIP header with 13-pin 0.1" vertical header. Added labels to
    the pins.
    - removed left over unused diode
    - reversed default on / default off labels on shiftlock mode jumper
    block.
    [addon.kicad_pcb, addon.kicad_sch]
2022-04-07 bump reset+SL addon to 1.4
    [addon.kicad_pcb, addon.kicad_sch]
2022-04-09 Update classic keyboard main PCB to kicad 6
    - fix various ERC and DRC errors resulting from upgrade
    - list included nets in busses on schematic
    - Modify Footprints with multiple options (therefore multiple sets of
    pads) to used shaped pads and proper pad numbering to eliminate DRC
    issues, and ensure proper behavior
    [kbd-classic.kicad_pcb, kbd-classic.kicad_sch, keys1.kicad_sch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]
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2023-03-19 Add support for Franklin ACE 1000 replacement keyboard (#42)
    * Initial commit.
    * Add support for Franklin ACE 1000.
    * Add ace1000_keyboard_test() for completeness.
    * Add link to replacement keyboard.
    * Add Franklin ACE 1000 replacement keyboard link.
    * Add Franklin ACE 1000 keyboard.
    * Activate caps-lock at powerup, and swap keymaps accordingly.
    ---------
    [Franklin ACE 1000 Keyboard.kicad_pcb, Franklin ACE 1000 Keyboard.kicad_sch]
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2023-04-22 Restore mounting holes
    A prior commit apparently deleted several mounting holes.
    - restore mounting holes
    - update to Kicad7
    - fix DRC errors resulting from update
    - update footprints to use new shaped pads
    [kbd-classic.kicad_pcb]
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2023-07-02 Updates to Franklin Ace keyboard
    - Use the dual footprints for futaba / cherry keys
    - include a diode for every key.
    - Add stabilizers to the spacebar
    - The Franklin keyboard is 9u, but it's very hard to find a 9u option. Instead, use 8u+1u
    - Replace the LOCK key with a 1.75U key with LED window. Fix LED spacing to match original.
    [franklin-ace-1000-keyboard.kicad_pcb, franklin-ace-1000-keyboard.kicad_sch]
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2023-08-31 Fix number row sizes in keycap spec
    [classic-ascii-keycaps.xlsx]
2023-11-05 Franklin updates (#44)
    * Remove rowcol references.
    Will re-implement row-col scanner after keymap improvements.
    * Fix number row sizes in keycap spec
    [classic-ascii-keycaps.xlsx]
2023-11-05 More key fixes
    [franklin-ace-1000-aligner-cherry.kicad_pcb, franklin-ace-1000-keyboard.kicad_pcb]
2023-11-11 Fixed multiple problems with OSI interface
    - off-by-one connections to keyboard connector
    - wrong demultiplexing of select signals
    - 2OE on 74LS240 was not inverted, resulting in wrong circuit.
    - use pre-jumpered row diodes.
    - fixed off-grid errors on schematic
    [Sound.kicad_sch, interface-osi.kicad_pcb, interface-osi.kicad_sch]
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2023-11-27 True up Franklin 1000 key spacing
    - Make sure each 1U is 0.75 inch.
    - Record key width for all keys > 1U, and ensure spacing is correct.
    - create symbols for the mx keys
    [franklin-ace-1000-keyboard.kicad_pcb, franklin-ace-1000-keyboard.kicad_sch]
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2023-12-09 Update to include mounting hardware
    - Fix all components to include full information including BOM
    information
    - Include all mounting hardware in components List
    - fix schematic to align on 0.1" grid.
    [kbd-classic.kicad_pcb, kbd-classic.kicad_sch, keys1.kicad_sch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]
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
